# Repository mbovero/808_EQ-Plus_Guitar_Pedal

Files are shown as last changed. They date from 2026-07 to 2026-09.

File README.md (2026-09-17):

# 808 EQ+

A faithful, buildable recreation of the original Tube Screamer 808 circuit with optional bass, treble, and clipping controls.

Most of the 808 EQ+ signal path closely replicates the original TS808 using modern, functionally equivalent components. Its added controls were intentionally designed so they can be switched out of the circuit, allowing the pedal to return to the familiar mid-focused response, symmetric silicon clipping, compression, and sustain associated with a traditional TS808.

When more flexibility is desired, the added switches can extend the pedal’s bass response, open its upper-frequency response, and select between three distinct clipping configurations.

<p align="center">
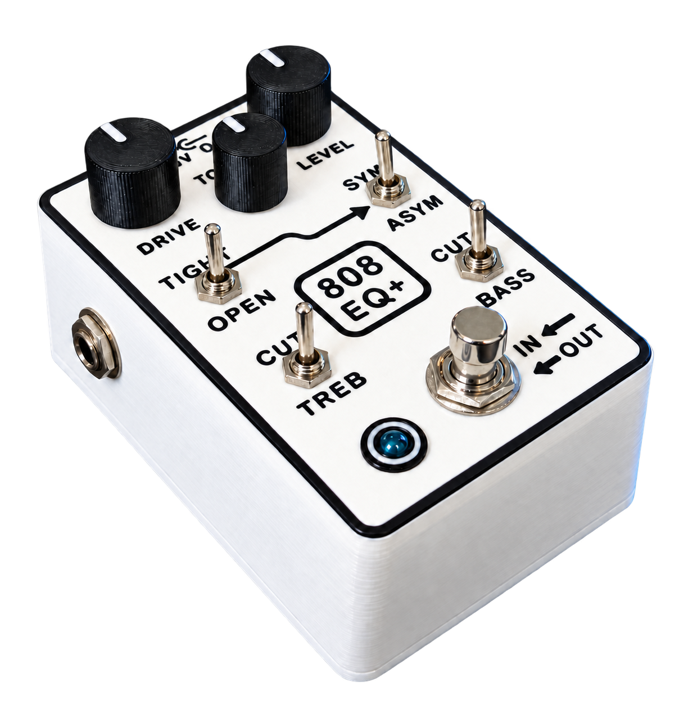
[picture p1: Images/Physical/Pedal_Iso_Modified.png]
Completed 808 EQ+ overdrive pedal.
  
</p>

<p align="center"><em>Completed 808 EQ+ overdrive pedal.</em></p>

## Table of Contents

* [What Is the 808 EQ+?](#what-is-the-808-eq)
* [Why Build Another Tube Screamer?](#why-build-another-tube-screamer)
* [Design Goals](#design-goals)
* [Controls and Operation](#controls-and-operation)
* [Technical Documentation](#technical-documentation)
* [Build Your Own 808 EQ+](#build-your-own-808-eq)
* [Warnings and Limitations](#warnings-and-limitations)
* [Credits and References](#credits-and-references)
* [Disclaimer](#disclaimer)

---

## What Is the 808 EQ+?

The Tube Screamer is best known for its characteristic mid hump, smooth symmetric clipping, and ability to act as a clean boost that pushes an amplifier while tightening and cleaning up the guitar tone.

The 808 EQ+ preserves that foundation.

Rather than replacing the original TS808 tone, the added controls make it possible to temporarily move beyond it. The bass and treble switches give the player access to a fuller, clearer sound with more low end and/or upper-frequency detail. The clipping switches change the headroom, compression, volume, and feel of the distortion.

With the added switches returned to their default positions, the pedal can operate like a traditional TS808.

### Traditional TS808 Character

In its default configuration, the 808 EQ+ provides:

* Reduced bass entering the distortion stage
* Reduced upper treble after the tone stage
* A pronounced mid-focused response
* Symmetric silicon-diode clipping
* Moderate compression and sustain
* Familiar Drive, Tone, and Level operation

### Expanded EQ+ Character

The added controls can provide:

* More low-frequency fullness without allowing excessive bass into the distortion stage
* Considerably more treble, presence, and clarity
* LED clipping with more headroom for dynamic distortion
* Asymmetric silicon clipping with slightly greater output and a rougher, more amp-like character

Beyond its expanded sound options, the project includes true-bypass switching, a custom through-hole PCB, and a fully modeled 3D-printed enclosure with custom knobs, an LED holder, integrated labels, and graphics. The repository also provides the design files, manufacturing files, and component information needed for hobbyist construction.

---

## Why Build Another Tube Screamer?

This project began as a way to learn how guitar pedals work internally and to apply the electronics, PCB design, CAD, and manufacturing skills I developed while studying computer engineering in college.

It was also an opportunity to put an existing collection of electronic components, fabrication tools, test equipment, and 3D-printing equipment to practical use.

Commercial guitar pedals can become expensive, especially when experimenting with several variations of a similar circuit. Building the pedal from the component level made it possible to study each circuit stage, experiment with tone-shaping and clipping behavior, and create a pedal tailored to my own preferences.

The idea of creating and sharing a design that could be reproduced, studied, and modified by other hobbyists was also a major motivation for the project.

## Design Goals

### Preserve the Original TS808 Circuit

The original TS808 was chosen as a reliable and well-understood foundation.

The goal was not to loosely imitate its sound or to create an unrelated overdrive with a similar name. The signal path was recreated carefully using modern but functionally equivalent components, and the added modifications were designed so they could be removed from the active signal path through the front-panel switches.

This allows the pedal to return to the original bass cut, treble cut, and symmetric silicon clipping that define the traditional Tube Screamer sound, with familiar Drive, Tone, and Level controls.

### Add More Tone-Shaping Flexibility

The original Tube Screamer response is useful because it prevents excessive low frequencies from becoming muddy and limits upper frequencies that might otherwise sound harsh.

However, those same filters can make the pedal feel narrow or overly mid-focused in some rigs.

Several tone-shaping approaches and component values were tested before selecting two modifications:

* A moderate bass extension that adds fullness without allowing the distortion to become excessively muddy
* A substantial treble extension that adds presence, clarity, and sparkle

Both modifications are independently switchable.

### Keep the Project Affordable and Customizable

A major goal was to reduce the cost of producing a complete pedal.

Traditional die-cast metal pedal enclosures can represent a significant portion of a DIY pedal’s cost. A 3D-printed enclosure reduces that cost while allowing much greater freedom over the enclosure shape, internal structure, labels, colors, mounting features, and overall appearance.

A 3D-printed enclosure can also be customized in ways that would be difficult or expensive with a standard metal box. In principle, the same electronics could be placed in a 3D-printed enclosure shaped like a cloud, mushroom, character, or other custom object.

### Make the Design Educational and Reproducible

The repository is intended for:

* Guitar-pedal enthusiasts with electronics and additive-manufacturing experience
* Electronics hobbyists interested in analog audio circuits
* Guitarists who want to build and modify their own equipment
* Students learning circuit simulation, PCB design, soldering, testing, or CAD
* Curious readers who want to understand how a Tube Screamer works
* Motivated builders who may not yet have enough knowledge to design a pedal independently

This is not intended to be the simplest possible beginner soldering kit. It is a complete engineering project that includes simulation, prototyping, PCB design, off-board wiring, mechanical design, additive manufacturing, and final assembly.

---

## Controls and Operation

The 808 EQ+ uses three knobs, four toggle switches, and a true-bypass footswitch.

<p align="center">
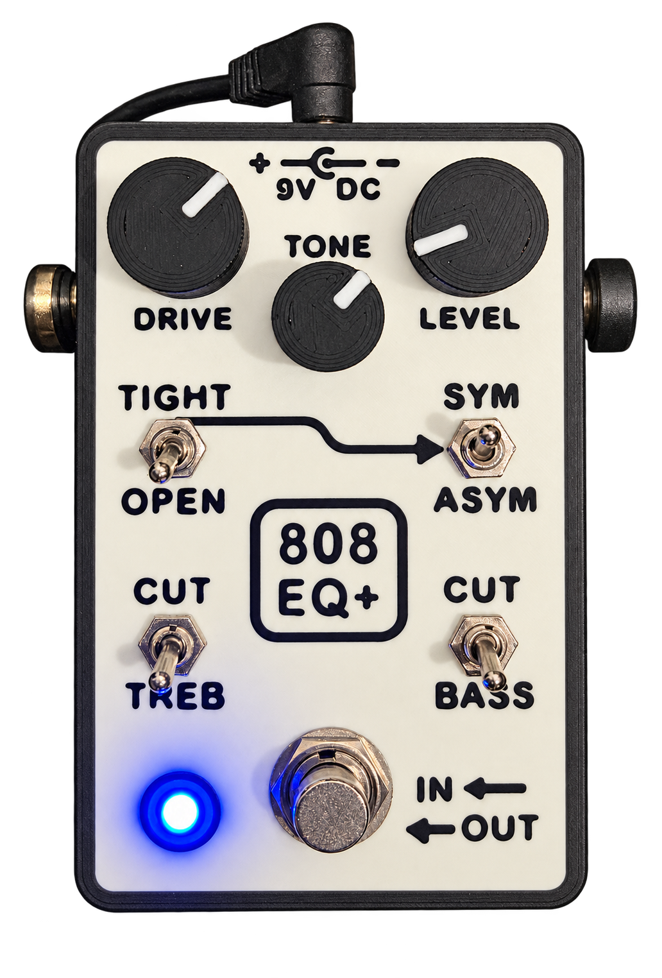
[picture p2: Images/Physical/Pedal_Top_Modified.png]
Top view of the completed 808 EQ+ pedal
  
</p>

<p align="center"><em>Top view of the completed pedal and its controls.</em></p>

| Control | What it does |
| --- | --- |
| **Drive** | Sets the amount of distortion. Turn it up for more grit, compression, and sustain. |
| **Tone** | Adjusts the pedal from darker and smoother to brighter and more present. |
| **Level** | Sets the final output volume. Start low and adjust it to match or boost the volume with the effect engaged. |
| **Tight / Open** | Selects a focused, more compressed sound or a louder, more dynamic sound. |
| **Sym / Asym** | Changes the texture of Tight-mode distortion from smoother and more even to thicker and grittier. This switch has no effect in Open mode. |
| **Cut / Treb** | Selects the traditional smoother treble response or adds clarity, presence, and sparkle. |
| **Cut / Bass** | Selects the traditional tighter low end or adds fullness and weight. |
| **Footswitch** | Turns the effect on or off. The LED lights while the effect is active; when it is off, true-bypass switching connects the input directly to the output. |

For the familiar TS808-style sound, flip all four toggle switches upward to select **Tight**, **Sym**, and both **Cut** settings. Lower the Level control before switching to Open mode because it can produce substantially more output.

For connection diagrams, detailed mode descriptions, recommended starting settings, power information, and troubleshooting help, see the [808 EQ+ User Manual](808_EQ-Plus_User_Manual.pdf).

---

## Technical Documentation

Detailed documentation for the project’s development process and major design stages is maintained separately:

* [Technical Documentation](TECHNICAL_DOCUMENTATION.md)

The separate document includes:

* Complete design and prototyping process
* In-depth circuit design
* PCB construction
* Enclosure design and mechanical integration
* 3D-printing considerations
* And plenty of information for curious minds

This material is separated to keep the main project page more approachable while preserving a deeper technical explanation for interested readers.

---

## Build Your Own 808 EQ+

If this project has made you curious about building an 808 EQ+ of your own, you are welcome to use the repository as a DIY construction resource. The project is intended for hobbyists who want to assemble the documented design, learn from it, or adapt it to suit their own ideas.

At a high level, the process involves reviewing the schematic and bill of materials, choosing between the provided PCB and a perfboard build, obtaining the components, printing and checking the enclosure parts, assembling and testing the electronics, installing the off-board controls and connections, and completing final mechanical and functional checks with a guitar and amplifier.

The complete [808 EQ+ DIY Build Guide](BUILD_GUIDE.md) brings together the component and tool lists, fabrication resources, PCB and perfboard options, recommended print settings, assembly guidance, staged testing, and troubleshooting information. Read through the guide before ordering parts or beginning construction.

---

## Warnings and Limitations

### Hobbyist 3D-Printed Enclosure Considerations

* The printed enclosure does not provide the same impact resistance as a cast-metal pedal enclosure.
* Common 3D-printing plastics are generally less resistant to high temperatures than metal enclosures and may soften, warp, or deform if exposed to excessive heat.
* A plastic enclosure does not inherently provide the electromagnetic shielding of a grounded metal enclosure.
* Print quality and dimensional accuracy will vary depending on the 3D printer, material, calibration, and print settings used. I cannot guarantee that every print will be suitable for mounting components or that all printed text will be legible.
* The enclosure does not include an internal battery compartment or an automatic battery-disconnection feature.

### Electronics and Assembly Considerations

* A regulated 9 V DC, center-negative pedal supply is recommended. An external 9 V battery adapter is also supported if its 2.1 mm connector polarity is verified before use.
* The circuit remains powered while bypassed. Disconnect an external battery when the pedal is not in use.
* Do not apply more than 9 V. The reverse-polarity diode does not protect the circuit from excessive input voltage.
* Some fabrication and assembly steps require prior soldering, electronics, CAD, or 3D-printing experience.

### Variations in Sound and Interpretation

* Exact sound will vary with the guitar, pickups, amplifier, speakers, signal level, power supply, and playing dynamics.
* Descriptions such as “smooth,” “open,” “gritty,” and “amp-like” are subjective and should not be treated as precise measurements.

---

## Credits and References

### Project Basis and Attribution

The 808 EQ+ is based on the established Tube Screamer 808 circuit topology. The underlying Tube Screamer circuit was not invented as part of this project.

The original contributions of this project include the specific circuit recreation, modern component selection, switchable tone and clipping modifications, PCB implementation, mechanical design, printed enclosure, documentation, and fabrication workflow.

Development drew on educational material covering TS808 circuit analysis, op-amp feedback-loop clipping, active tone controls, transistor buffering, analog filter design, guitar-pedal bypass wiring, through-hole PCB design, and additive-manufacturing practices.

### Primary References

Two resources were particularly helpful during the early research and circuit-analysis stages:

* [**ElectroSmash**](https://electrosmash.mas-effects.com/) — The ElectroSmash Tube Screamer analysis provided a detailed stage-by-stage explanation of the original circuit, including its operating theory, filter behavior, gain calculations, clipping, buffering, and tone control.
* [***Tracking Down Your Dream Tone — Build Your Own Guitar Effects Pedals: A Beginner’s Guide***](https://www.amazon.com/dp/B09ZCJLB9J) by Sascha Suhr — This book provided an accessible introduction to guitar-pedal electronics, circuit simulation, breadboard experimentation, component selection, practical construction, and troubleshooting.

### Additional Online Resources

The following websites, channels, and community forums were also consulted for circuit references, practical building information, equipment demonstrations, troubleshooting discussions, and perspectives from other pedal builders and guitarists:

* [Beavis Audio Research](https://beavisaudio.com/)
* [Analog Man](https://www.analogman.com/)
* [That Pedal Show](https://www.youtube.com/thatpedalshow)
* [GEO’s Effects](http://www.geofex.com/)
* [Free Stompboxes](https://www.freestompboxes.org/)
* [DIY Stompboxes](https://diystompboxes.com/wpress/)
* [PedalPCB Community Forum](https://forum.pedalpcb.com/)
* [The Gear Page](https://www.thegearpage.net/)

Community discussions and subjective descriptions were used as practical references rather than definitive technical sources. Circuit behavior and design decisions were evaluated through component datasheets, circuit analysis, simulation, electrical measurements, and hands-on listening tests.

### Software and Development Tools

Software and equipment used during development included:

* LTspice
* Analog Discovery 2 and WaveForms
* Altium Designer
* Autodesk Fusion 360
* Bambu Studio
* Bambu H2S
* DIY Layout Creator
* General electronic test, soldering, and assembly equipment

---

## Disclaimer

This project is provided for educational and personal-use purposes.

Build and use it at your own risk. Verify component values, component orientation, diode polarity, transistor pinouts, integrated-circuit orientation, power-supply polarity, operating voltages, and enclosure clearances before connecting the pedal to other equipment.

Disconnect power before modifying the circuit. Avoid making component changes while the pedal is connected to a guitar, amplifier, computer, audio interface, or other valuable equipment.

The repository may contain mistakes, and reports of any inconsistencies or errors would be greatly appreciated.

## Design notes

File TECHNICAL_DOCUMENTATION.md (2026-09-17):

# 808 EQ+ — Technical Documentation

This document contains the detailed development process, circuit design, PCB design, enclosure design, additive-manufacturing information, and experimental results for the 808 EQ+ guitar pedal.

For the project overview, controls, build guide, and current release status, return to the [main README](README.md).

## Table of Contents

<details>
<summary><strong><a href="#design-and-prototyping-overview">Design and Prototyping Overview</a></strong></summary>

* [1. Circuit Research and Part-by-Part Analysis](#1-circuit-research-and-part-by-part-analysis)
* [2. Original TS808 Simulation and Breadboard Prototype](#2-original-ts808-simulation-and-breadboard-prototype)
* [3. Frequency-Response and Clipping Experiments](#3-frequency-response-and-clipping-experiments)
* [4. Perfboard, Faceless Enclosure, and Prototype Validation](#4-perfboard-faceless-enclosure-and-prototype-validation)
* [5. Component Selection and Price Optimization](#5-component-selection-and-price-optimization)
* [6. PCB Design in Altium Designer](#6-pcb-design-in-altium-designer)
* [7. Enclosure Remodeling and Mechanical Integration](#7-enclosure-remodeling-and-mechanical-integration)
* [8. Final Assembly and Testing](#8-final-assembly-and-testing)

</details>

<details>
<summary><strong><a href="#circuit-design">Circuit Design</a></strong></summary>

* [Signal-Path Overview](#signal-path-overview)
* [Power Supply and Bias Network](#power-supply-and-bias-network)
* [Input Buffer](#input-buffer)
* [Variable-Gain and Clipping Stage](#variable-gain-and-clipping-stage)
* [Active Tone Stage](#active-tone-stage)
* [Output Buffer](#output-buffer)
* [True-Bypass and LED Circuit](#true-bypass-and-led-circuit)

</details>

<details>
<summary><strong><a href="#pcb-design">PCB Design</a></strong></summary>

* [Process Overview](#process-overview)
* [Design Priorities](#design-priorities)
* [Library Development](#library-development)
* [Through-Hole Components](#through-hole-components)
* [Socketed and Replaceable Components](#socketed-and-replaceable-components)
* [Routing and Grounding](#routing-and-grounding)
* [Manufacturer Selection and Design Files](#manufacturer-selection-and-design-files)

</details>

<details>
<summary><strong><a href="#enclosure-design-and-3d-printing">Enclosure Design and 3D Printing</a></strong></summary>

* [Why Use a Printed Enclosure?](#why-use-a-printed-enclosure)
* [Component-Driven Design](#component-driven-design)
* [Printed Labels and Graphics](#printed-labels-and-graphics)
* [Multi-Color Printing](#multi-color-printing)
* [Final Print Files and Build Guidance](#final-print-files-and-build-guidance)

</details>

<p><strong><a href="README.md">Return to the Main README</a></strong></p>

---

## Design and Prototyping Overview

The 808 EQ+ was developed through several stages, beginning with an in-depth study of the original TS808 circuit and progressing through simulation, breadboarding, measurement, perfboard prototyping, PCB design, enclosure modeling, and final assembly.

### 1. Circuit Research and Part-by-Part Analysis

The original TS808 circuit was studied in detail before beginning the physical design.

The [ElectroSmash](https://electrosmash.mas-effects.com/) Tube Screamer analysis was an especially useful reference. It provides an approachable but detailed explanation of the theory, mathematics, and behavior of the circuit and is a valuable resource for readers who want to understand why each stage operates as it does.

Additional background came from Sascha Suhr's book, [*Tracking Down Your Dream Tone — Build Your Own Guitar Effects Pedals: A Beginner's Guide*](https://www.amazon.com/dp/B09ZCJLB9J), which introduces both the theory and practical process involved in designing and building guitar effects pedals.

Other relevant concepts were researched through a wide range of freely available online educational resources. This research was supplemented by my background in computer engineering from the University of Utah.

Each major section of the TS808 circuit was analyzed separately, including:

* Input and output buffers
* Bias network
* Op-amp gain stage
* Frequency-dependent feedback
* Diode clipping
* Active tone control
* Power filtering
* Bypass behavior

This research established a known working baseline and made it possible to evaluate later modifications without losing track of the original circuit behavior. The part-by-part analysis was also used to identify modern components that could replace less-available original parts while preserving their electrical function.

### 2. Original TS808 Simulation and Breadboard Prototype

The development process began with a publicly available schematic of the original [TS808 circuit](https://electrosmash.mas-effects.com/ElectroSmash%20-%20Tube%20Screamer%20Circuit%20Analysis.pdf). That unmodified circuit was first recreated in LTspice and then assembled on a breadboard using the original topology and modern, functionally equivalent components.

Establishing a working unmodified circuit *first* provided a reference against which every later change could be evaluated. Full-size potentiometers, audio jacks, and a DC barrel jack were integrated into the breadboard during this stage so the circuit could be evaluated as a complete pedal system.

The breadboard stage facilitated the analysis of:

* Basic signal flow
* Input and output buffer operation
* Bias voltages
* Drive, Tone, and Level control behavior
* Symmetric silicon clipping
* Practical operation with a guitar and amplifier

The visual documentation in the following section begins with the final LTspice model and breadboard prototype after the EQ+ modifications were integrated.

### 3. Frequency-Response and Clipping Experiments

After the original circuit was operating correctly, the breadboard and LTspice models were modified one component and one circuit branch at a time.

The goal was to strike a useful balance between preserving the original TS808 character and adding meaningful tone-shaping options. The modifications were intended to be clearly audible without becoming either extreme or lackluster.

The Analog Discovery 2 and WaveForms software were used to examine:

* Frequency response
* Filter corner frequencies
* Gain changes
* Symmetric and asymmetric clipping
* Diode forward-voltage effects
* Output amplitude
* Waveform shape

Although these tools provided useful electrical measurements, a guitar-pedal circuit is difficult to characterize completely with a single set of tests. Its behavior can vary with the frequency and amplitude of the input signal, component tolerances, power-supply quality, radio-frequency interference, and other practical conditions. Each physical build may therefore behave slightly differently.

Final design decisions were made using a combination of circuit theory and analysis, LTspice simulation, Analog Discovery 2 measurements, and careful listening and experimentation with a guitar and amplifier. Measurements helped explain and compare circuit behavior, while hands-on playing determined whether each change was musically useful.

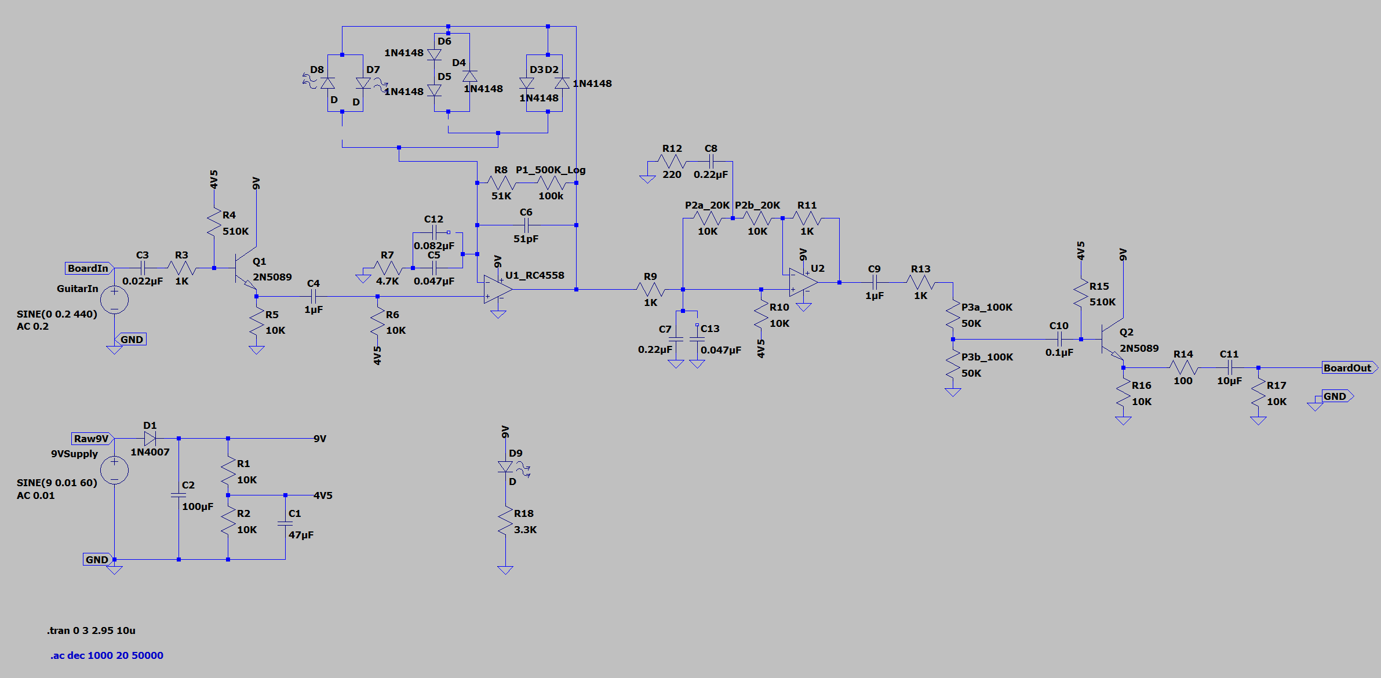
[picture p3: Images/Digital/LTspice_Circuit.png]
Modified 808 EQ+ LTspice circuit


*The circuit shown above is the final LTspice model containing the selected 808 EQ+ modifications.*

Much of the Bass Pass Through and Treble Pass Through development involved experimenting with different capacitor and resistor values, adding components at different points in the signal path, and comparing several switching arrangements.

The bass experiments focused on adding enough low-frequency content to produce a thicker, fuller sound without allowing the clipped bass frequencies to become excessively strong or muddy. The treble experiments focused on improving transparency, clarity, and presence without making the pedal sound harsh or fizzy. The final values were selected because they produced noticeable but controlled alternatives to the original TS808 response.

Detailed explanations of the selected circuits, component values, and filter corner frequencies are provided in [Bass Pass Through Switching](#bass-pass-through-switching) and [Treble Pass Through Switching](#treble-pass-through-switching).

The clipping experiments compared multiple arrangements of LEDs and 1N4148 silicon diodes. Symmetric, asymmetric, and mixed-diode configurations were evaluated for differences in output volume, compression, sustain, picking dynamics, and overall distortion character.

The final options were selected because each produced a distinct and practical sound: the original-style symmetric silicon configuration provides the familiar TS808 response, asymmetric silicon clipping offers a subtle variation with additional texture, and symmetric LED clipping provides a louder, more open, and dynamic alternative.

For a detailed explanation of the diode arrangements, clipping thresholds, and switch operation, see [Feedback-Loop Diode Clipping](#feedback-loop-diode-clipping) and [Clipping Switches and Configurations](#clipping-switches-and-configurations).

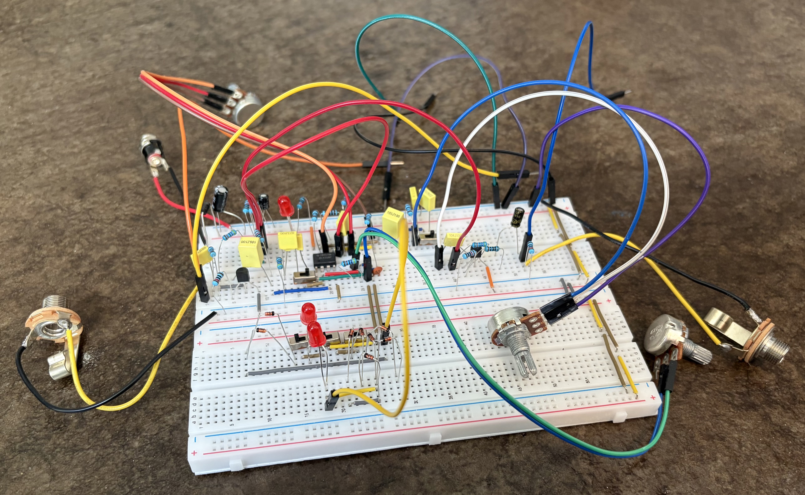
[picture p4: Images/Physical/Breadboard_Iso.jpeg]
Modified 808 EQ+ breadboard prototype


*Modified breadboard prototype used to evaluate the final EQ and clipping changes.*

Several other possible features were also considered and tested, including:

* A switch for increased distortion
* A switch that changed the output resistor between TS808 and TS9 values
* A wet/dry blend control
* Additional diode configurations

These options were not included in the final design because their changes were underwhelming or insignificant, or because the additional circuitry and controls fell outside the intended scope and complexity of the project.

### 4. Perfboard, Faceless Enclosure, and Prototype Validation

After the breadboard design was stable, it was transferred to perfboard to create a compact, more permanent circuit that reduced loose wiring, established a practical layout, and could be mounted inside a pedal enclosure.

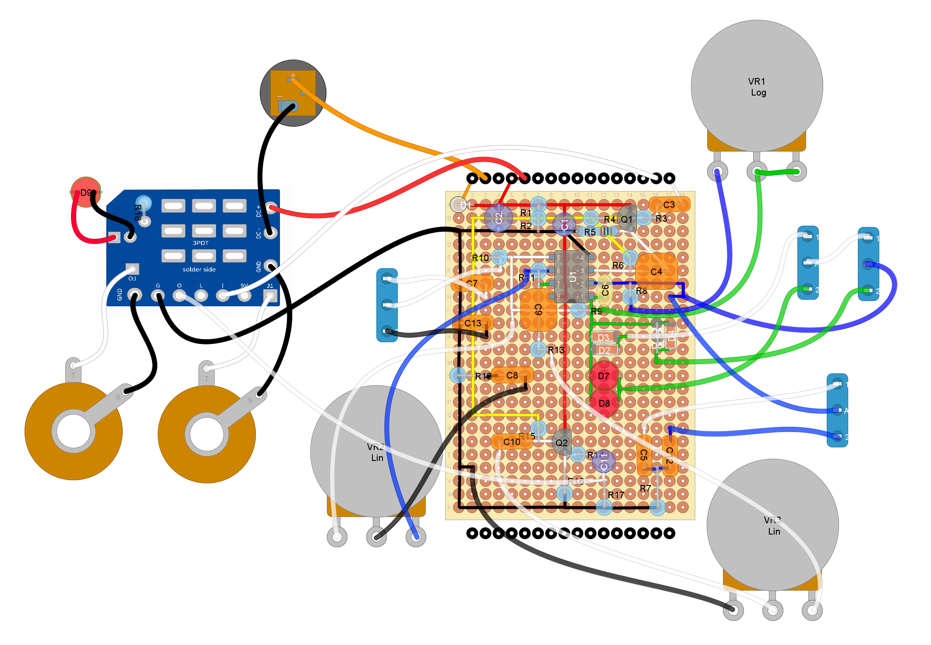
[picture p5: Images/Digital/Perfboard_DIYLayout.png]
Perfboard layout


The purpose of this design stage was to:

* Consolidate the circuit
* Integrate the true-bypass footswitch
* Reduce breadboard-related connection problems
* Test the design in a more durable and portable pedal format
* Confirm the final circuit before beginning PCB design

The first 3D-printed enclosure prototype was developed in Autodesk Fusion 360 and focused primarily on fit and function rather than appearance. It provided a practical way to mount the circuit and controls before committing to the custom PCB and final enclosure design.

The perfboard + test enclosure prototype was used to confirm:

* Basic effect operation
* True-bypass switching
* Drive, Tone, and Level controls
* Bass and Treble Pass Through behavior
* Symmetric silicon clipping
* Asymmetric silicon clipping
* LED clipping
* Switch interaction
* Practical off-board wiring
* Overall sound and usability

This validation established the final circuit configuration that would then be transferred to a custom PCB.

The perfboard circuit and faceless enclosure also exposed practical problems that were not as apparent during breadboard testing. These steps were helpful in understanding the intricacies of developing an intuitive, visually appealing, and reliable pedal. They allowed me to refine the physical circuit-assembly process, develop a more compact and easy-to-use enclosure, and configure 3D-printing settings that balanced appearance, dimensional accuracy, and functionality.

| Faceless prototype exterior | Perfboard prototype interior |
| --- | --- |
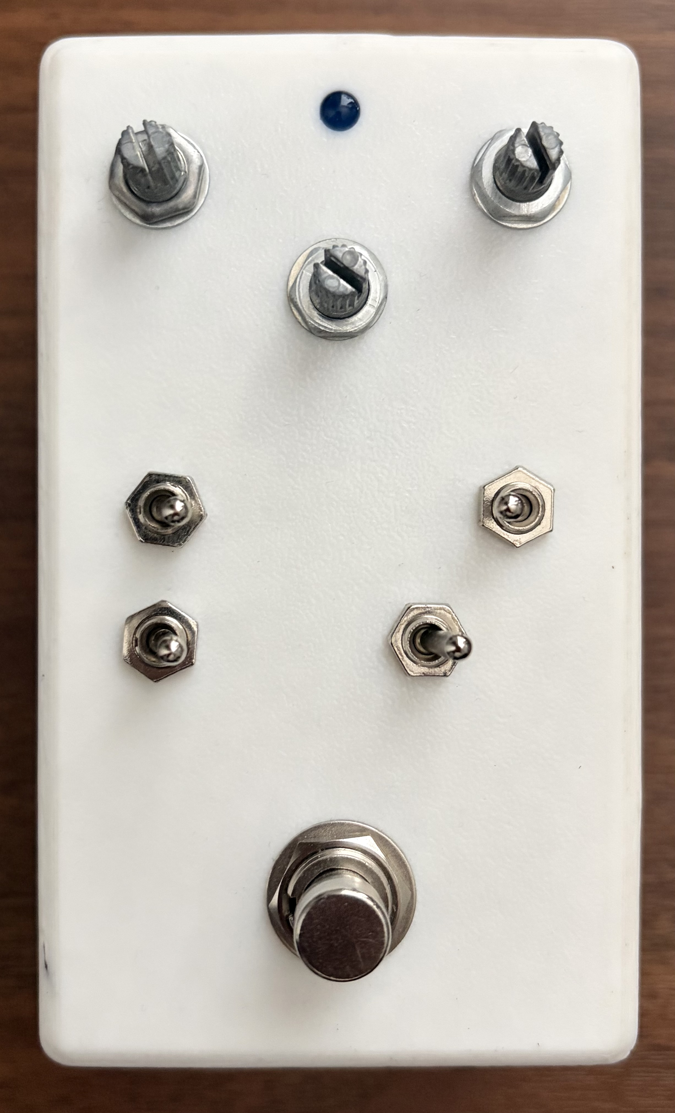
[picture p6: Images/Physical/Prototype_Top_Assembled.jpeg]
Top view of the assembled faceless prototype
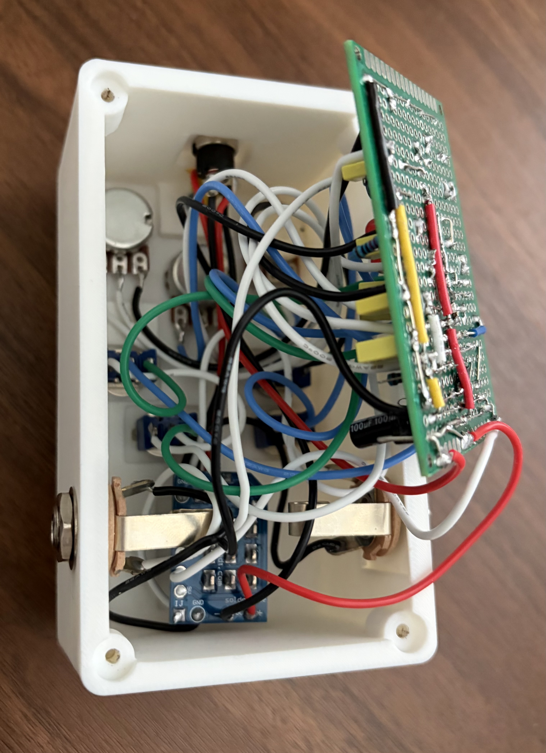
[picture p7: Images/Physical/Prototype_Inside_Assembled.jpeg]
Interior of the assembled prototype showing the perfboard circuit
|  |  |

### 5. Component Selection and Price Optimization

Considerable time was spent selecting quality components for the later revisions. This work had to be completed before PCB design because the exact component dimensions, pin spacing, and package styles were required to create or verify footprints and plan the board layout.

Many parts used in the early breadboard and perfboard prototypes came from bulk component variety kits. For the custom PCB revision, the goal was to source only the required parts, reduce unnecessary purchases, improve component consistency, and streamline assembly.

Parts were compared through [Octopart](https://octopart.com/) and supplier catalogs from [DigiKey](https://www.digikey.com/), [LCSC](https://www.lcsc.com/), [Tayda Electronics](https://www.taydaelectronics.com/), [Mouser](https://www.mouser.com/en/), and other vendors. DigiKey was selected as the primary source for on-board electronic components because it offered all the required parts, reputable component quality, reasonable pricing, and the ability to consolidate the order through one supplier.

The available options from these suppliers were less suitable for much of the off-board hardware. [Love My Switches](https://lovemyswitches.com/) was selected for affordable, good-quality potentiometers and mono jacks. The SPDT toggle switches and true-bypass footswitches were purchased through Amazon because they were significantly less expensive and the parts had already proved reliable in the first prototype.

Each supplier was chosen by balancing component cost, quality, availability, and total shipping expense. Enough parts were purchased to build five pedals, which reduced the estimated per-pedal cost through quantity pricing and by spreading shipping costs across multiple builds.

All components used in the final design, along with part numbers, quantities, suppliers, and estimated pricing, are listed in the [`808_EQ-Plus_Single_Pedal_BOM.xlsx`](Design/808_EQ-Plus_Single_Pedal_BOM.xlsx) file in the repository’s `Design` folder.

### 6. PCB Design in Altium Designer

The validated circuit was redrawn and laid out in Altium Designer as a compact, reproducible through-hole PCB. The process converted the working prototype into a board that balanced enclosure fit, signal routing, hand-assembly accessibility, serviceability, and support for continued component experimentation.

This stage included building and verifying the component libraries, organizing the circuit into functional blocks, optimizing component placement and routing, preparing clear assembly markings, checking the completed design, comparing fabrication services, and generating the required manufacturing files.

For a complete discussion of the component libraries, construction choices, socketed parts, grounding, routing, manufacturer selection, and fabrication outputs, see [PCB Design](#pcb-design).

### 7. Enclosure Remodeling and Mechanical Integration

After the electronic design and PCB dimensions were better understood, the enclosure was remodeled in Fusion around the physical requirements of the circuit and off-board hardware. Simplified models of the PCB, controls, switches, jacks, power connector, LED, and related hardware were used to refine component spacing, openings, internal clearance, wire routing, assembly access, and the overall enclosure dimensions.

The resulting enclosure was designed specifically for 3D printing and incorporates the pedal’s mounting features, labels, graphics, custom knobs, LED holder, and removable bottom cover into a unified design.

For additional information about the modeling process, component placement, printed labels, materials, multi-color fabrication, tolerances, and print considerations, see [Enclosure Design and 3D Printing](#enclosure-design-and-3d-printing).

### 8. Final Assembly and Testing

The final phase began with assembling the manufactured PCB, inspecting the solder joints, and verifying the orientation of polarized components. The completed board was then tested outside the enclosure so that electrical or assembly problems could be identified and corrected before the off-board components were mounted.

After confirming basic PCB operation, the controls, switches, jacks, LED, and other off-board components were installed. Enclosure fit, bypass operation, effect operation, and every switch configuration were evaluated alongside the pedal’s drive, output level, tone, and overall usability. Any mechanical or electrical issues identified during this process were corrected through further revisions.

The enclosure-printing process was also refined in Bambu Studio to improve appearance, dimensional accuracy, component fit, and overall functionality.

The completed PCB, enclosure, and assembled pedal have been fully tested and validated. Final fit checks confirmed that the PCB, off-board components, wiring, and printed enclosure function together as intended.

The final manufacturing files, PCB files, CAD exports, print files, dimensional drawings, and other supporting design resources have been released and are available in the repository’s [`Design`](Design/) folder.

---

## Circuit Design

The 808 EQ+ closely follows the original TS808 signal path while adding switchable filter and clipping options.

### Signal-Path Overview

```mermaid
flowchart TB
    IN["Guitar In"] --> SW{"3PDT true-bypass footswitch"}
    SW -->|"Bypass: effect off"| OUT["Guitar Out"]
    SW -->|"Effect engaged"| IB["Input Buffer"]
    IB --> CLIP["Variable-Gain and Clipping Stage"]
    CLIP --> TONE["Active Tone and Treble-Filtering Stage"]
    TONE --> LEVEL["Level Control"]
    LEVEL --> OB["Output Buffer"]
    OB --> OUT
```

When the effect is engaged, the footswitch routes the guitar through each functional circuit stage. In bypass, it connects the input directly to the output and grounds the unused effect input, removing the effect circuit from the guitar-signal path. The power connection is not shown; the circuit remains powered while bypassed.

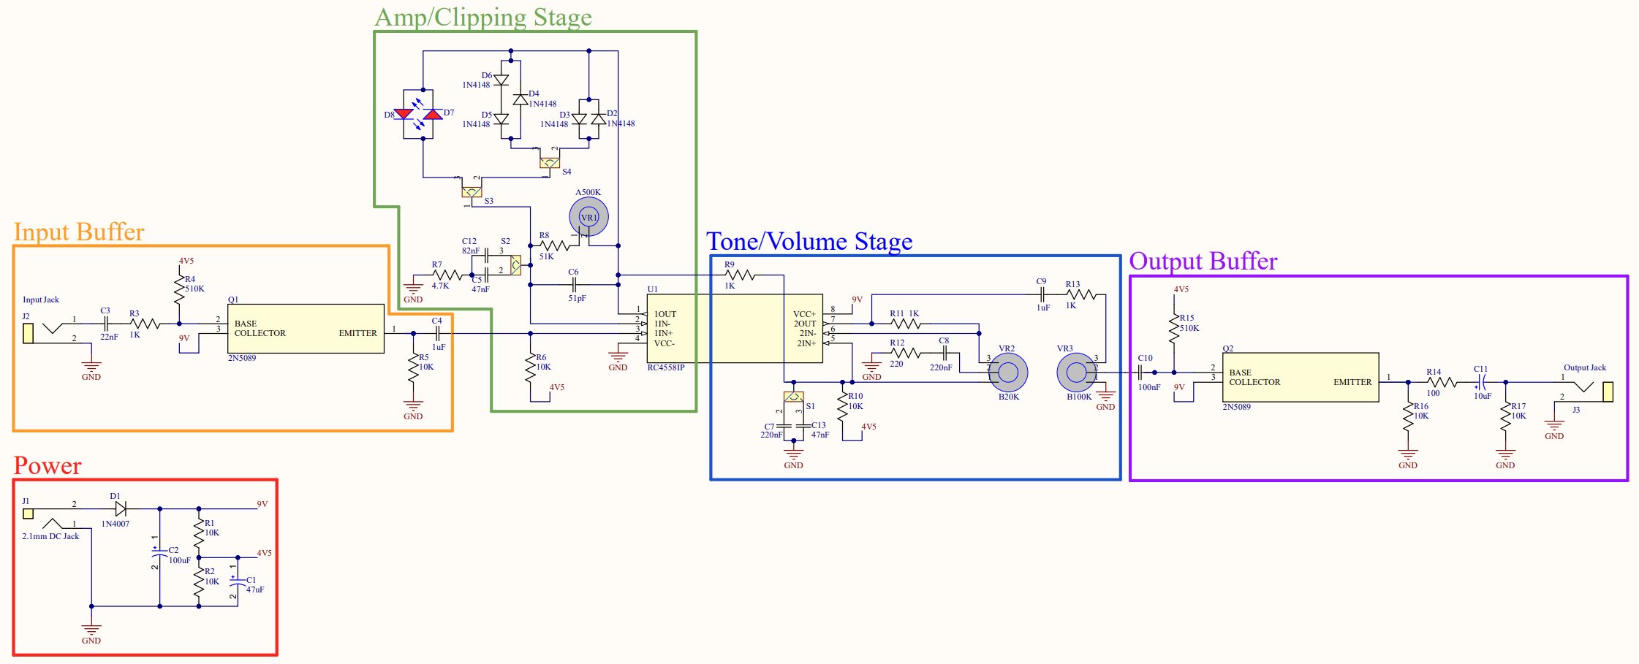
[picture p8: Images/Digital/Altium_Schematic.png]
808 EQ+ schematic


### Power Supply and Bias Network

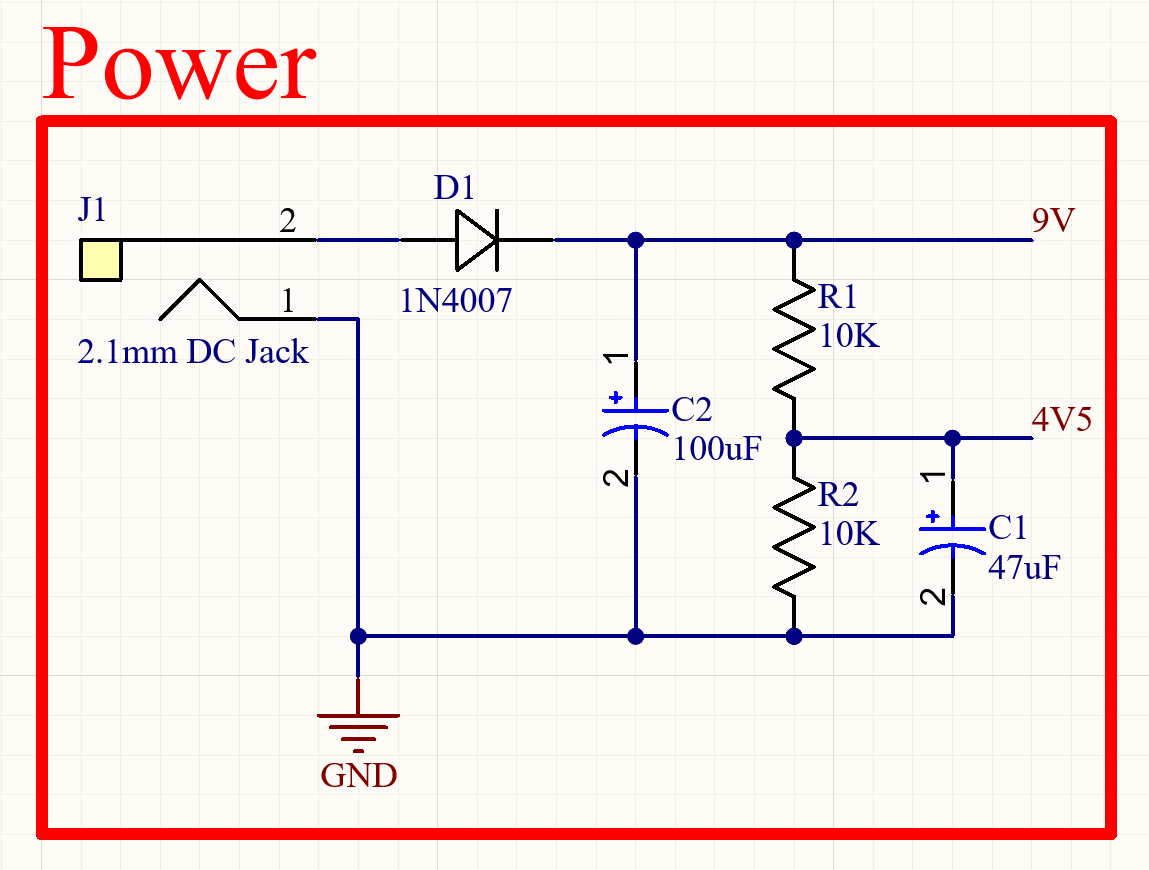
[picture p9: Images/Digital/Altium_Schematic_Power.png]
Power supply and bias network schematic


*Altium schematic of the 9 V input, reverse-polarity protection, supply filtering, and power rails.*

#### Power Input and Reverse-Polarity Protection

The recommended power source is a regulated **9 V DC, center-negative pedal supply** using the 2.1 mm barrel connector commonly found on modern guitar pedals. An external 9 V battery adapter is also supported if its connector polarity is verified before use. In either case, the connector’s outer sleeve supplies the positive voltage while its center pin is connected to ground.

D1, a **1N4007 rectifier diode**, is placed in series with the positive supply path to provide reverse-polarity protection. This diode differs from the protection components used in historical TS808 circuits, but it was selected to follow common modern pedal-design practices and provide a robust, readily available replacement. Because D1 is part of the power-supply path rather than the audio signal path, this change has no significant effect on the pedal’s sound or tone during normal operation.

If a supply with the opposite polarity is connected, the diode becomes reverse-biased and prevents significant current from flowing through the circuit. The pedal will not operate, and its transistors, op-amp, and polarized capacitors should be protected from reverse-polarity damage.

The diode protects against reversed polarity, but it does not regulate the input or protect the circuit from excessive voltage. Inputs above 9 V should not be used because they could exceed component ratings and damage the pedal.

#### 4V5 Bias Reference

R1 and R2 form a voltage divider that produces a nominal voltage equal to half of the protected supply rail. This node is labeled **4V5** and acts as a virtual midpoint for biasing the audio signal throughout the circuit.

Relatively low divider-resistance values were selected to reduce the reference node’s output impedance. This creates a firmer bias reference that is less susceptible to loading and transient voltage changes.

Because the circuit uses a single positive supply rather than positive and negative power rails, the guitar signal cannot remain centered around 0 V. Doing so would cause the negative half of the waveform to approach the ground rail, where it could be clipped or distorted by the BJTs and op-amp. Biasing the signal near half the supply voltage provides room for both halves of the AC waveform to swing above and below their DC operating point.

#### Supply Filtering and Distribution

C2 filters and stabilizes the protected 9 V rail, while C1 filters and stabilizes the 4V5 reference. Their relatively large capacitances provide a low-impedance path to ground for low-frequency supply ripple, transient disturbances, and some coupled interference. This helps provide cleaner and more stable power to the audio circuit, although it cannot eliminate every possible source of power-supply or radio-frequency noise.

The protected 9 V rail powers the active devices directly, including the op-amp supply and BJT collectors. The 4V5 reference is distributed through biasing resistors to establish the DC operating point at the beginning of the circuit’s audio stages.

#### Nominal and Actual Voltages

Labels such as **9V** and **4V5** describe the intended function of these rails rather than guaranteed measured voltages. The actual DC supply may differ slightly from exactly 9 V, and D1 introduces a forward-voltage drop that is typically around 0.7 V, although it varies with current and temperature. As a result, the protected rail may be closer to approximately 8–8.5 V when powered by a nominal 9 V supply, and the divided reference will be approximately half of that value.

A biasing resistor also does not automatically create a fixed voltage drop; the drop depends on the current flowing through it. Op-amp inputs draw very little current and may remain close to the 4V5 reference, while BJT bias nodes may differ more because of base current and surrounding component values.

These variations are expected and do not prevent normal operation. The important requirement is that each stage maintains a stable operating point with enough headroom for the guitar waveform. A guitar signal is often only a few hundred millivolts during typical playing, although strong transients from high-output pickups can approach roughly 2 V peak-to-peak or more.

### Input Buffer

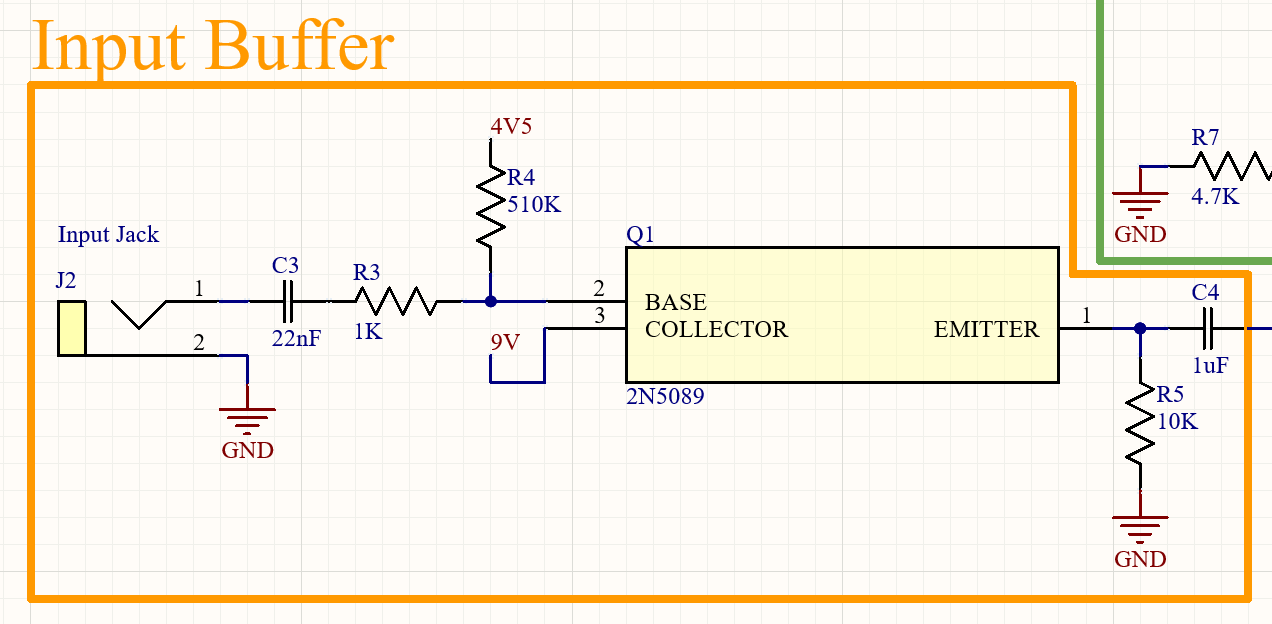
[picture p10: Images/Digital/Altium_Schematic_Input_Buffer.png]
Input buffer schematic


*Altium schematic of the input jack, coupling capacitors, bias network, and BJT emitter-follower buffer.*

#### Purpose and Impedance

The input buffer provides a stable interface between the guitar and the rest of the effect circuit. It isolates the guitar pickups from the more complex loading conditions created by the clipping stage and allows the original signal to be passed forward without intentional voltage amplification.

A good guitar buffer has a **high input impedance** and a **low output impedance**. An input impedance near 1 MΩ is commonly considered desirable, although values of several hundred kilohms are also widely used in guitar pedals. A high input impedance prevents the circuit from drawing substantial current from the pickups and reduces the damping of their natural frequency response. In this circuit, R4 and the transistor’s base impedance provide a sufficiently high input impedance for the guitar signal.

Cable and wiring capacitance can contribute to unwanted filtering. Before the buffer, the guitar pickup impedance, cable capacitance, and pedal input impedance form a more complex frequency-dependent network that can reduce high-frequency content and alter the pickup resonance. Commonly described as “tone sucking,” this effect becomes more noticeable when the following circuit presents too low of an input impedance or when long cables add substantial capacitance.

After the buffer, the interaction can be approximated more simply using:

`f_c = 1 / (2πRC)`

In this relationship, reducing the driving resistance moves the low-pass corner frequency upward. The buffer’s low output impedance therefore allows it to drive the following circuit and its associated capacitance without producing significant filtering within the audible range. A buffer cannot recover high frequencies already lost in the cable before it, but it prevents the following pedal stages from adding substantial additional loading.

#### Input Jack

The input uses a mono 1/4-inch audio jack. The sleeve is connected to circuit ground, while the tip carries the guitar signal into the input buffer.

Stereo input jacks are often used in pedals to disconnect an internal battery when the instrument cable is removed. The 808 EQ+ has no internal battery compartment or automatic battery-disconnection feature, so a mono jack was selected to simplify the wiring and reduce cost. An external 9 V battery adapter remains supported, but it supplies the circuit whenever it is connected—including while the effect is bypassed—and should be disconnected when the pedal is not in use.

#### Coupling Capacitors and Bias Transfer

C3 is an input coupling capacitor. The guitar signal arriving from the input jack is centered around 0 V, while the transistor base must operate at a positive DC bias. C3 blocks the guitar’s original DC level while allowing its AC audio content to pass into the transistor’s bias network.

R4 connects the transistor base to the 4V5 reference, causing the incoming guitar waveform to become centered around the nominal half-supply voltage. This provides room for the signal to swing above and below its new DC operating point without approaching the circuit’s ground rail.

C4 performs a similar function at the buffer output. Because the transistor is configured as an emitter follower, its emitter sits approximately one base-emitter voltage drop below the base—typically around 3–4 V DC in this circuit. C4 blocks that emitter DC level while passing the AC guitar signal to the clipping stage, where it is established around that stage’s own nominal 4V5 bias.

In addition to transferring signals between different DC operating points, the coupling capacitors interact with the surrounding resistances to form high-pass filters. Their values were selected so the desired guitar-frequency range can pass without excessive low-frequency loss.

#### BJT Emitter-Follower Configuration

The BJT is configured as an **emitter follower**, also called a **common-collector amplifier**. The input signal enters through the base, and the buffered output is taken from the emitter. The collector is connected directly to the protected 9 V rail, which supplies the transistor’s operating current and establishes its upper voltage limit.

R3 is a small series base resistor that provides isolation, limits transient base current, and can help reduce unwanted high-frequency or radio-frequency behavior. R4 supplies the base bias while also contributing to the buffer’s input impedance.

R5 provides the emitter with a path to ground and helps establish the transistor’s quiescent current and DC operating point. It also introduces negative feedback: changes in emitter current change the voltage across R5 in a direction that resists further change, improving stability.

An emitter follower has a voltage gain slightly below 1, so it does not significantly amplify the guitar waveform. Its primary benefit is current gain and impedance conversion. The original high-impedance guitar signal is reproduced at the emitter as a lower-impedance, higher-drive signal that can reliably feed the clipping stage.

### Variable-Gain and Clipping Stage

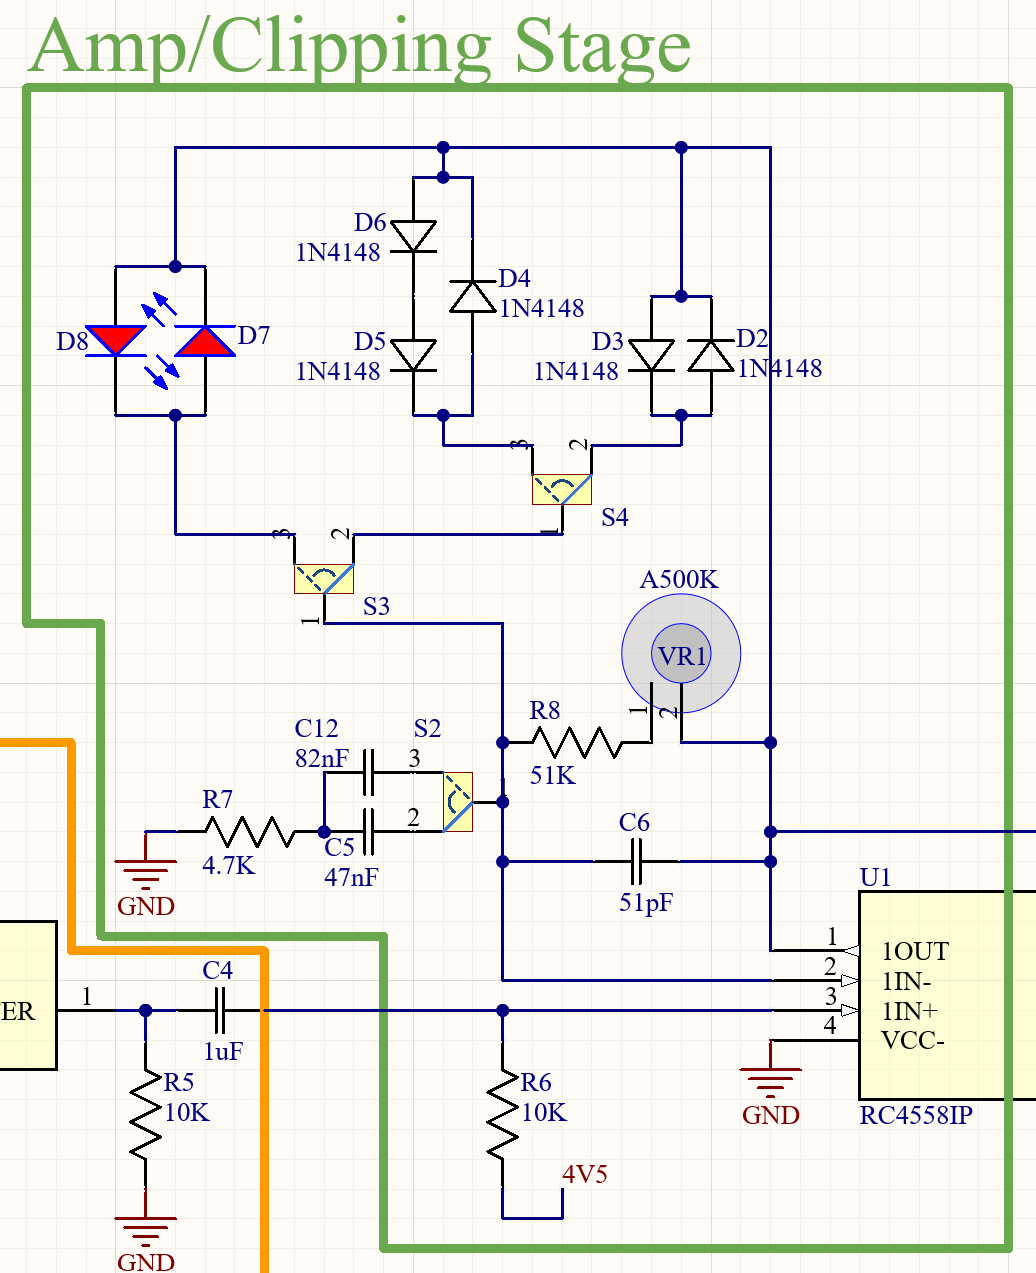
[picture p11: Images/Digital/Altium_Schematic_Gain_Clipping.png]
Amplification and clipping stage schematic


*Altium schematic of the non-inverting op-amp gain stage, frequency-dependent feedback network, Bass Pass Through switching, and selectable diode-clipping configurations.*

#### High-Level Behavior

The purpose of this stage is to add controlled, musically useful distortion to the guitar signal. The input is amplified by an op-amp in a non-inverting configuration until the voltage across the feedback network becomes large enough to forward-bias the clipping diodes. As the diodes begin conducting, they reduce the stage’s effective gain and progressively limit the waveform’s peaks. This produces the smoother transition into distortion commonly described as **soft clipping**.

Rather than amplifying every frequency equally, the TS808 feedback network reduces the gain applied to lower frequencies. This keeps excessive bass out of the clipped signal and helps prevent the distortion from becoming loose or muddy. The stage’s frequency-dependent gain, phase response, and diode clipping combine to produce the Tube Screamer’s characteristic waveform, including its tilted and rounded peaks and valleys.

This stage also contains the Bass Pass Through modification and the switches used to select the three clipping configurations.

#### Non-Inverting Amplifier and Drive Control

The op-amp is configured as a non-inverting amplifier. Within the frequency range where the feedback capacitors are not substantially affecting the circuit, its closed-loop gain can be approximated as:

`Gain = 1 + (Rf / Rg)`

In this circuit, `Rf` is primarily formed by R8 and the variable resistance of the Drive potentiometer, while `Rg` is R7. This produces an approximate midband gain range of **12 to 120**.

At the minimum Drive setting, the potentiometer’s wiper and connected outer terminal produce nearly 0 Ω of additional feedback resistance. The gain is then determined primarily by R8 and R7. Turning the Drive control clockwise increases the potentiometer resistance in the feedback path, raising the stage gain and driving the clipping diodes harder.

These gain values are frequency-dependent rather than constant across the entire guitar spectrum. At sufficiently low frequencies, the impedance of C5 or C12 causes the gain to fall toward unity. At very high frequencies, C6 also reduces the gain.

#### Frequency-Dependent Feedback

A capacitor’s opposition to AC current is called **capacitive reactance** and can be approximated as:

`Xc = 1 / (2πfC)`

Capacitive reactance decreases as frequency increases.

C6 is connected across the op-amp’s feedback resistance. At low and middle frequencies, its reactance is high, so the Drive potentiometer and R8 primarily determine `Rf`. At very high frequencies, C6 presents a lower-impedance path around the feedback resistance. This lowers the effective value of `Rf`, reduces the stage gain, and helps prevent very high-frequency noise and harsh, fizzy content from being excessively amplified.

C5 and C12 create the opposite frequency-dependent effect because the selected capacitor is placed in series with R7 in the feedback path to ground. At higher frequencies, the capacitor’s reactance is low and the stage operates near the gain predicted by `1 + Rf/R7`. As frequency decreases, the capacitor’s reactance rises, increasing the impedance of the feedback path to ground (`Rg`) and reducing the stage gain toward unity.

The result is a high-pass response in the stage’s distortion gain: middle and upper frequencies receive substantial amplification and clipping, while lower frequencies remain comparatively cleaner.

#### Bass Pass Through Switching

The original C5 value creates a distortion-stage high-pass corner at approximately **720 Hz**. Selecting C12 lowers this corner to approximately **410 Hz**, allowing more low-frequency content to receive the additional gain needed to enter clipping.

The Bass Pass Through capacitor value was chosen to give the guitar a thicker and fuller low end without allowing the distorted bass frequencies to become excessively strong or muddy.

A passive SPDT switch selects between C5 and C12. This keeps the modification simple and avoids placing an additional active switching circuit inside the sensitive feedback network. However, the inactive capacitor does not have a dedicated discharge path and may retain a small charge. A brief switching pop may therefore occur when changing between the Bass Cut and Bass Pass Through settings.

C5 and C12 also introduce a frequency-dependent phase shift, particularly around their respective corner frequencies. This phase response contributes to the shape of the resulting waveform, although the visible waveform is produced by the combined effects of filtering, amplification, clipping, and phase shift rather than by a simple time delay alone.

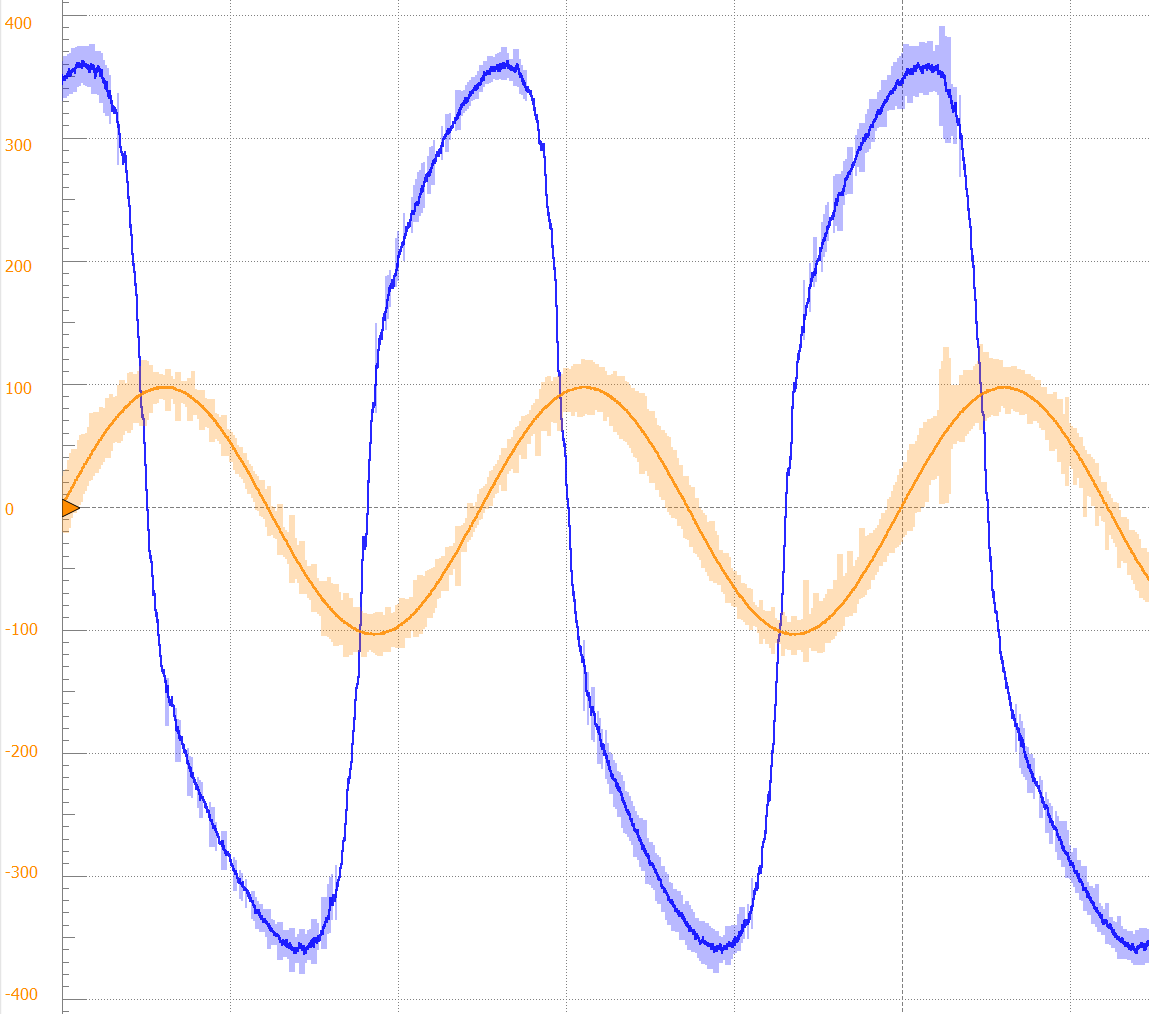
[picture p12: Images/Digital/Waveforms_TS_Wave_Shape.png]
Tube Screamer waveform shape


*Measured Tube Screamer-style waveform showing the characteristic shape produced by frequency-dependent amplification, capacitor phase shift, and feedback-loop clipping. Input is orange, and output is blue.*

#### Feedback-Loop Diode Clipping

The clipping diodes are connected inside the op-amp feedback loop. When the voltage difference across the diode network remains below its forward-conduction threshold, the diodes have little effect and the op-amp operates at the gain established by the feedback resistors.

As the amplified signal increases, the diodes begin to conduct and provide a lower-impedance feedback path. This increases negative feedback and reduces the stage’s effective gain near the waveform peaks. Because diode conduction increases progressively rather than switching instantaneously, the peaks are rounded instead of being cut off abruptly.

The 1N4148 silicon diodes have a forward voltage of approximately **0.6–0.7 V**, while the red LEDs have a substantially higher forward voltage of approximately **1.8 V**. The exact values vary with current, temperature, and the individual components.

Lower-forward-voltage diodes begin clipping at a lower signal level, producing greater compression and a tighter, more saturated response. Higher-forward-voltage diodes allow the op-amp output to reach a greater amplitude before substantial clipping occurs, resulting in more output volume, greater headroom, less compression, and a more dynamic response.

Amplification + clipping reduces the difference between louder and quieter portions of the signal. This compression can make the decaying portion of a note remain more consistent in volume and distortion character, which is often perceived as increased sustain.

#### Clipping Switches and Configurations

The **Tight/Open** switch selects between the silicon-diode network and the symmetric LED network:

* **Tight** engages the 1N4148 silicon clipping selected by the Sym/Asym switch.
* **Open** engages symmetric red-LED clipping and bypasses the Sym/Asym selection.

The **Sym/Asym** switch only affects the silicon clipping network:

* **Sym** uses one 1N4148 diode in each direction for the traditional symmetric TS808 configuration.
* **Asym** uses one 1N4148 in one direction and two series-connected 1N4148 diodes in the opposite direction, producing different positive and negative clipping thresholds.

| Tight/Open | Sym/Asym | Clipping configuration | General character |
| --- | --- | --- | --- |
| **Tight** | **Sym** | Symmetric silicon clipping | Traditional TS808-style clipping with relatively low headroom, moderate compression, and an even response on both halves of the waveform. |
| **Tight** | **Asym** | Asymmetric silicon clipping | Unequal clipping thresholds produce slightly greater output, less uniform compression, and additional even-order harmonic content associated with a thicker, more textured sound. |
| **Open** | Either position | Symmetric LED clipping | The higher clipping threshold provides substantially greater output, more headroom, reduced compression, and a more dynamic distortion response. |

The three configurations were selected because they provide distinct but practical variations without moving too far from the original TS808 character.

### Active Tone Stage

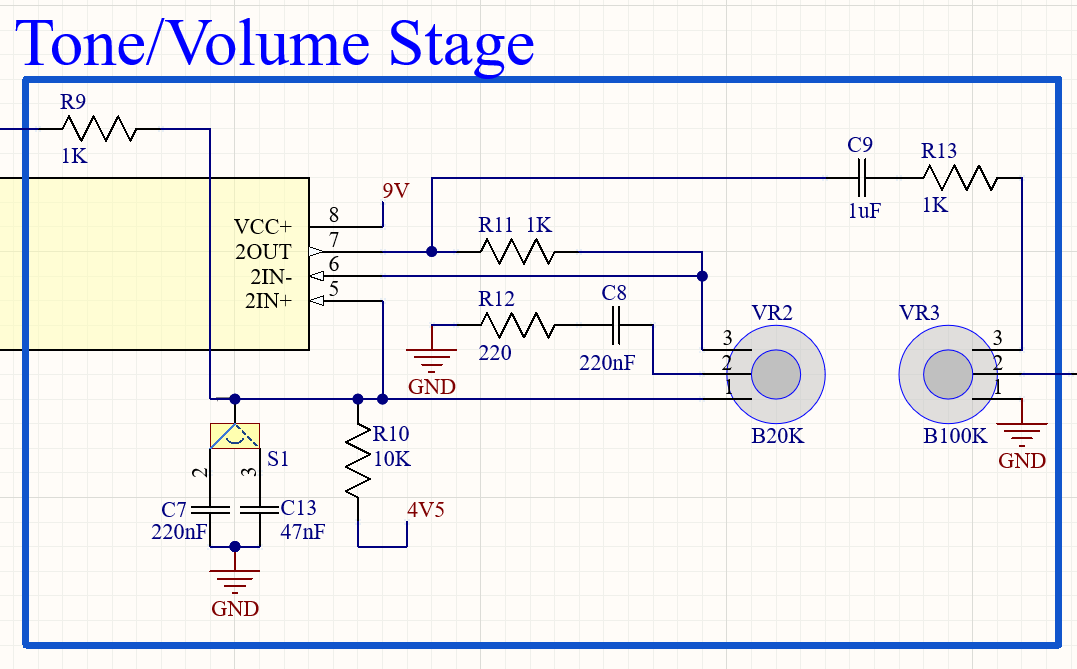
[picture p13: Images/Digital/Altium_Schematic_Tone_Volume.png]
Active tone and level-control schematic


*Altium schematic of the fixed low-pass filter, active upper-frequency boost, Tone control, Treble Pass Through modification, and Level control.*

#### High-Level Function

This stage provides control over the pedal’s upper-midrange and treble response. It combines a passive low-pass filter with an active, frequency-dependent op-amp stage. The Tone potentiometer blends between the darker filtered interaction and the brighter actively boosted interaction, allowing the player to move gradually from substantial treble reduction to a brighter and more present response.

The selected signal is then passed to the Level potentiometer, which controls the overall output amplitude. The coupling and buffering circuitry surrounding the Level control prevents the DC bias and external load from substantially interfering with the tone circuit.

#### Frequency-Dependent Signal Paths

The tone stage contains two primary frequency-dependent paths. The first is a low-pass filter formed by R9 and either C7 or C13, depending on the position of the Treble Pass Through switch. Its output is connected to the non-inverting (`+`) input of the op-amp. The selected capacitor determines the filter corner: C7 produces a corner near **720 Hz**, while C13 raises it to approximately **3.4 kHz**. The filter reduces content above the selected corner and passes the remaining signal into the rest of the tone circuit.

The second frequency-dependent path is formed by R12 and C8. This path can be reached from the initial low-pass-filtered path through one portion of the Tone potentiometer. C8 and R12 also interact with the op-amp feedback loop through the other side of the Tone potentiometer.

#### Active Upper-Frequency Boost

The op-amp is configured as a non-inverting amplifier. R11 forms the feedback resistance, while the Tone potentiometer, R12, and C8 form the frequency-dependent path from the inverting input to ground. Initially, it is helpful to analyze this portion of the circuit assuming the Tone pot is positioned all the way clockwise, giving a direct path from the feedback loop through C8 and R12 to ground.

At lower frequencies, C8 has relatively high capacitive reactance. This restricts current through the feedback path to ground and causes the op-amp gain to remain close to 1.

At higher frequencies, C8’s reactance decreases, leaving R12 as the primary resistance in the feedback path to ground. The high-frequency gain can then be approximated as:

`Gain = 1 + (R11 / R12)`

Using the selected component values, the maximum high-frequency gain is approximately **5.5**. This means the active path can amplify upper-frequency content by roughly five times relative to its low-frequency gain.

However, this does not mean the pedal’s final treble output is five times greater than the original guitar signal. The active boost occurs after the R9 and C7/C13 low-pass filter, which has already reduced some of the upper-frequency content. The final response results from the interaction between the initial low-pass filter, active high-frequency boost, Tone-pot position, and surrounding circuit impedances.

Although this simplified analysis does not capture every interaction in the circuit, it provides an intuitive explanation of how the tone stage can move between substantial treble reduction and an actively emphasized upper-frequency response.

#### Tone-Pot Operation

With the Tone control turned fully counterclockwise, its wiper is positioned toward the passive low-pass side of the circuit. This effectively puts C8 and R12 in parallel with C7 or C13, leading to a stronger reduction in upper-midrange and treble content. Simultaneously, the Tone pot's full resistance contributes to `Rg`, reducing the gain of the non-inverting op amp close to unity. These interactions produce a much darker, muted output.

With the Tone potentiometer turned fully clockwise, upper frequencies are actively boosted, providing substantially more upper-midrange and treble content. At the same time, the Tone potentiometer reduces current flow through C8 and R12, preventing higher frequencies from being cut as dramatically. This results in a significantly brighter and potentially harsh output.

Intermediate settings blend the two responses nicely, allowing the player to adjust the pedal continuously between a darker, more heavily filtered sound and a brighter, more present sound.

#### Treble Pass Through Switching

S1 and C13 form the **Treble Pass Through** modification. The SPDT switch selects the capacitor used with R9 in the tone-stage low-pass filter:

* Selecting C7 restores the original TS808-style corner frequency of approximately **720 Hz**.
* Selecting C13 raises the corner frequency to approximately **3.4 kHz**.

Raising the corner frequency allows substantially more upper-frequency content to reach the active tone circuit. C13 was selected to provide noticeably greater clarity, presence, and transparency without making the pedal excessively harsh or fizzy.

The Treble Pass Through switch changes the signal entering both sides of the Tone control. The Tone potentiometer continues to provide its normal dark-to-bright adjustment, but the overall available frequency range is extended when C13 is selected.

#### Level Control

After the Tone control selects the desired blend of passive and active responses, the AC signal is coupled to the Level potentiometer. The Level pot is configured as a voltage divider between the tone-stage output and ground.

At lower settings, a larger portion of the signal is directed toward ground and a smaller signal is taken from the wiper. Turning the Level control clockwise increases the proportion of the signal passed to the output buffer.

The Level control only attenuates the available signal; it does not provide additional gain. Its purpose is to set the final pedal output volume after the distortion and tone-shaping stages.

### Output Buffer

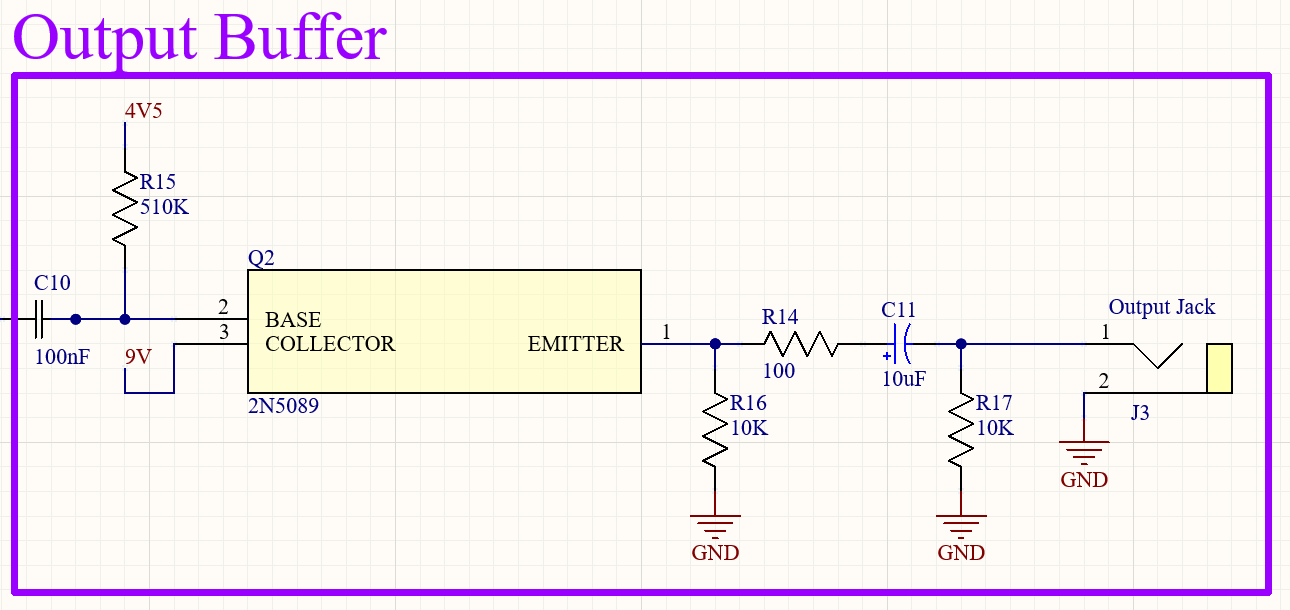
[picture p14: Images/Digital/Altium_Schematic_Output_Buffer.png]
Output buffer schematic


*Altium schematic of the BJT output buffer, output coupling capacitor, pull-down resistor, and output jack.*

#### Purpose

The output buffer performs a function similar to the [Input Buffer](#input-buffer), but its design priorities are slightly different. An extremely high input impedance is less critical here because the buffer is driven by the low-impedance tone-stage op-amp through the Level control rather than directly by passive guitar pickups.

Greater emphasis is placed on producing a low output impedance so the pedal can reliably drive an amplifier, another pedal, and the capacitance of the connected cable without significant signal loss or unwanted filtering.

The BJT uses essentially the same emitter-follower configuration as the input buffer. It provides a voltage gain close to 1 while increasing the available current drive and lowering the signal’s output impedance. See the [Input Buffer](#input-buffer) section for a more detailed explanation of emitter-follower operation.

#### Final Signal Preparation

The BJT emitter operates at a positive DC bias, but other pedals and amplifiers generally expect an audio signal centered around 0 V. C11 acts as the final coupling capacitor, blocking the buffer’s DC bias while allowing the AC guitar signal to pass to the output jack.

R17 is connected between the output side of C11 and ground. It establishes a 0 V DC reference and gives C11 a path to discharge when no output cable is connected. This prevents the output node from floating and helps reduce loud pops when connecting the pedal to other equipment.

C11, R17, and the input impedance of the connected equipment form a high-pass filter. Their values were selected to place the filter corner below the desired guitar-frequency range, preventing noticeable bass loss. The surrounding buffer components were selected to maintain a stable operating point and sufficiently low output impedance.

The prepared signal is delivered through the tip of the mono output jack, while the sleeve provides the ground connection.

### True-Bypass and LED Circuit

#### 3PDT Switching

Several true-bypass wiring arrangements are commonly used and can be found online. A 3PDT footswitch is especially useful when true-bypass signal routing, effect-input grounding, and LED indication must all be controlled by one switch.

A 3PDT switch contains three electrically independent poles that change state together. Each pole has a center common lug that connects to one of two outer lugs depending on the footswitch position. The switches purchased for this project included small breakout PCBs that simplify these connections and reduce the amount of point-to-point wiring required during assembly.

In this implementation, the three center connections correspond to the input jack, ground, and output jack. Pressing the footswitch connects these points to one of two sets of switched contacts.

#### Bypass State

When the effect is bypassed, the input jack is connected directly to the output jack. The guitar signal therefore travels through the mechanical switch without passing through the pedal’s input buffer, clipping stage, tone circuit, or output buffer.

At the same time, the effect-circuit input is connected to ground. Grounding the unused input prevents it from floating, where it could collect noise or create unpredictable behavior that becomes audible when the effect is re-engaged.

“True bypass” refers to the audio signal being disconnected from the effect circuit. The internal circuit remains electrically powered while bypassed, but it is removed from the active guitar-signal path.

#### Effect State

When the effect is engaged, the input jack is connected to the effect-circuit input and the effect-circuit output is connected to the output jack. The guitar signal then passes through the complete pedal circuit before continuing to the next pedal or amplifier.

The third pole completes the status-LED circuit, illuminating the LED to indicate that the effect is active.

#### LED Current Limiting

An LED requires a series current-limiting resistor to prevent excessive current from damaging the LED or placing unnecessary load on the power supply. The required resistance depends on the supply voltage, the LED’s forward voltage, and the desired operating current:

`R = (Vsupply - Vf) / ILED`

The LED forward voltage depends on its color and construction, while the selected current determines its brightness. In practice, a standard resistor value at or above the calculated resistance should be selected to keep the LED within its rated current. A lower-current operating point is often sufficient for a pedal indicator and reduces power consumption.

#### True Bypass Versus Buffered Bypass

Some pedals use buffered bypass, meaning the guitar signal continues to pass through an active buffer even when the effect itself is disabled. This can provide a low output impedance that helps drive long cables and other pedals, but it also means the bypassed signal is not completely isolated from the pedal’s electronics.

The 808 EQ+ does not use buffered bypass. When bypassed, the guitar signal follows a passive mechanical path directly from the input jack to the output jack. The pedal’s input and output buffers are only part of the signal path while the effect is engaged.

---

## PCB Design

The custom PCB was developed in Altium Designer to translate the validated prototype into a more durable, reproducible, and serviceable format.

### Process Overview

The PCB was developed through the following process:

1. Collect, revise, and organize the required schematic symbols and PCB footprints.
2. Redraw the complete schematic and assign the verified components, footprints, and designators.
3. Define the board shape and systematically place the through-hole components.
4. Position the off-board connection pads and orient component labels, values, and polarity markings for straightforward assembly.
5. Route the signal and power traces, then create the top and bottom ground pours.
6. Run electrical- and PCB-design-rule checks, correcting any identified problems.
7. Review the completed board in both 2D and 3D.
8. Generate the fabrication files and inspect the manufacturer previews before ordering.

| PCB top | PCB bottom |
| --- | --- |
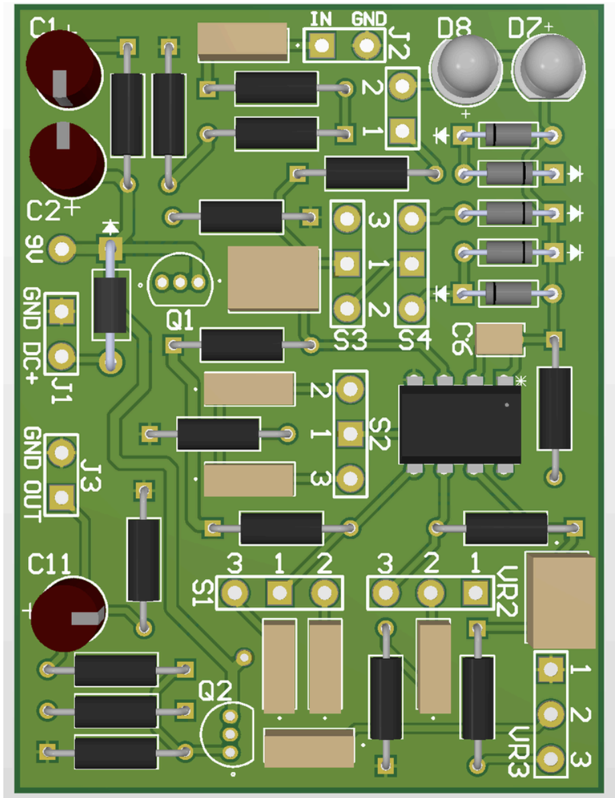
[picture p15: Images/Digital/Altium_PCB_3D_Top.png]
PCB top
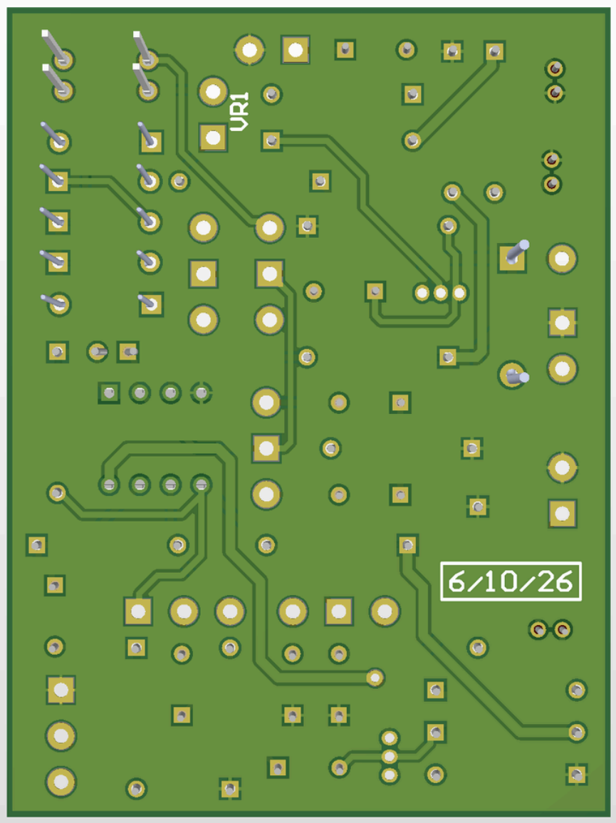
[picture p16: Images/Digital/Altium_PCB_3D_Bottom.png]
PCB bottom
|  |  |

### Design Priorities

The PCB was designed around the following priorities:

* Preserve the validated TS808-style circuit
* Use readily solderable through-hole components
* Group components by functional circuit block
* Provide practical connection points for off-board wiring
* Support component replacement and experimentation
* Fit efficiently within the custom printed enclosure
* Minimize trace length, unnecessary crossings, and layer changes
* Provide clearly aligned component designators, value labels, and polarity markings
* Make fabrication possible through common prototype-PCB services

### Library Development

Many schematic symbols and PCB footprints were sourced from DigiKey and collected into organized Altium project libraries. Each resource was reviewed for dimensional accuracy and checked against the corresponding component datasheet to verify its pinout, package dimensions, and lead spacing. Existing library components were corrected when necessary, and custom symbols or footprints were created when suitable resources were unavailable.

The completed Altium library files are available in the repository’s [`Design/PCB/Altium`](Design/PCB/Altium/) folder.

### Through-Hole Components

Through-hole components were selected because they are relatively easy to solder by hand, inspect visually, and replace when necessary. They are also familiar to many hobbyists, readily available in small quantities, and compatible with machine-pin sockets for experimentation or repair.

Although through-hole construction requires more board space than surface-mount construction, the increased accessibility and serviceability made the larger PCB area a worthwhile tradeoff.

### Socketed and Replaceable Components

Selected components can be installed in machine-pin sockets.

This is useful for:

* Comparing op-amps
* Comparing clipping diodes
* Replacing transistors
* Revising filter capacitors
* Troubleshooting damaged components
* Experimenting without repeatedly heating PCB pads

Sockets should be used selectively. Permanently installing every component in a socket would increase cost, assembly time, contact resistance, and the risk of intermittent connections.

Suggested components for machine-pin sockets include Q1, Q2, U1, C12, C13, and the clipping diodes. These locations are especially useful for tone experimentation, troubleshooting, repair, and comparing compatible replacement components.

### Routing and Grounding

The circuit’s typical current draw was measured at approximately **7–10 mA**. This range was entered into a PCB trace-width calculator, but the low current produced unusually narrow minimum-width recommendations. After researching trace widths commonly used by other guitar-pedal designers, wider traces were selected to provide more practical fabrication margins and greater physical robustness. The final layout uses **0.8 mm traces for the power rails** and **0.6 mm traces for signal paths**.

Signal traces were routed with attention to:

* Keeping related components close together
* Minimizing board area and trace length
* Reducing unnecessary trace crossings and layer changes
* Separating sensitive signal paths from power wiring
* Avoiding interference with through-hole pads
* Maintaining fabrication clearances

The board uses copper pours on both sides for ground distribution.

### Manufacturer Selection and Design Files

Several PCB manufacturers, including [OSH Park](https://oshpark.com/), [JLCPCB](https://jlcpcb.com/), [PCBWay](https://www.pcbway.com/orderonline.aspx), and [Elecrow](https://www.elecrow.com/pcb-manufacturing.html), were considered for producing the final board. Pricing, order quantities, fabrication options, shipping costs, turnaround time, and experiences reported by other hobbyists were compared. JLCPCB was ultimately selected because it offered an affordable option for the required boards and had received substantial positive feedback from other users online.

The relevant Altium project files, Gerber files, drill files, and other manufacturing outputs are available in the repository’s [`Design/PCB`](Design/PCB/) folder.

<table>
  <thead>
    <tr>
      <th>Bare PCB — component side</th>
      <th>Bare PCB — solder side</th>
    </tr>
  </thead>
  <tbody>
    <tr>
      <td align="center">
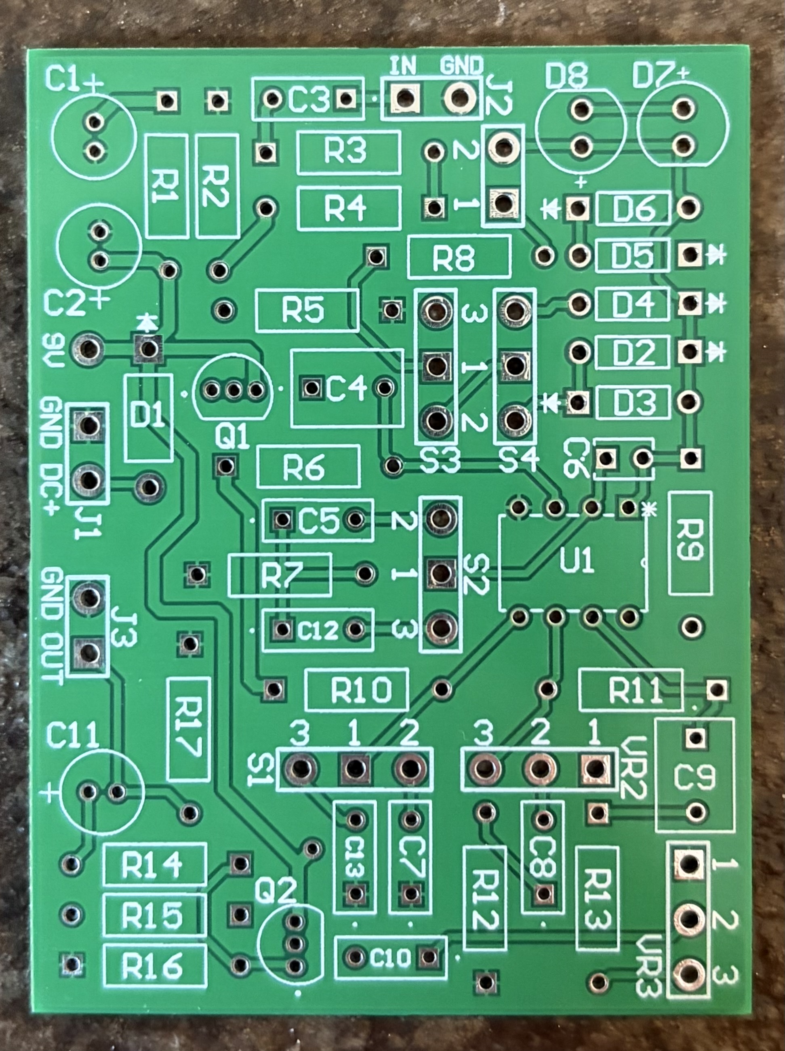
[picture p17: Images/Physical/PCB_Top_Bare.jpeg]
Component side of the bare PCB
        
      </td>
      <td align="center">
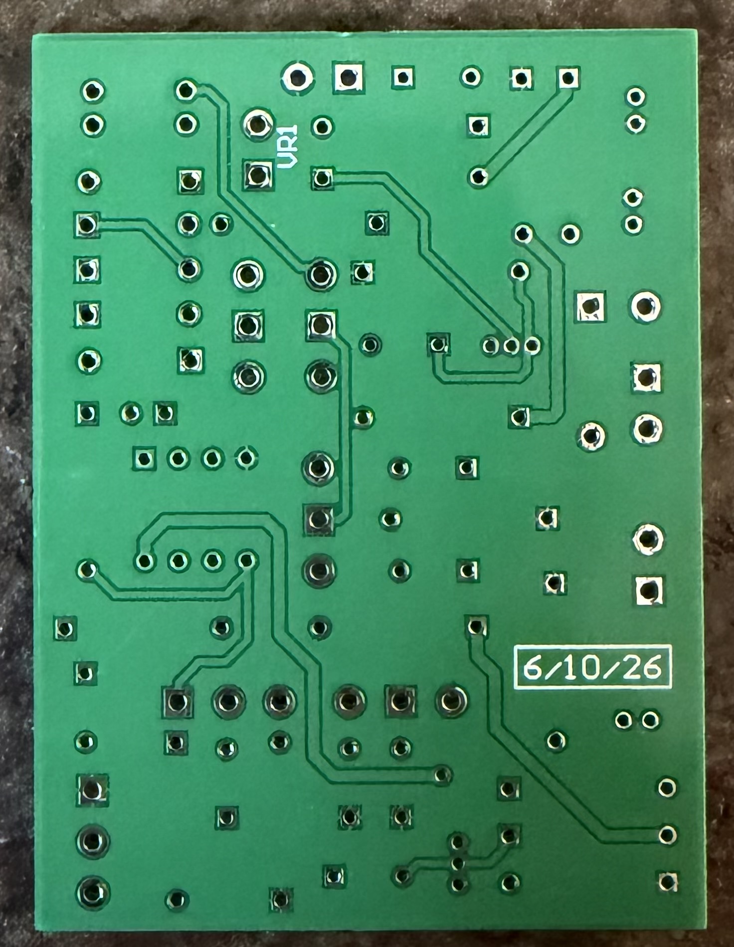
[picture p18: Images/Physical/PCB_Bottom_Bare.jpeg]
Solder side of the bare PCB
        
      </td>
    </tr>
  </tbody>
</table>

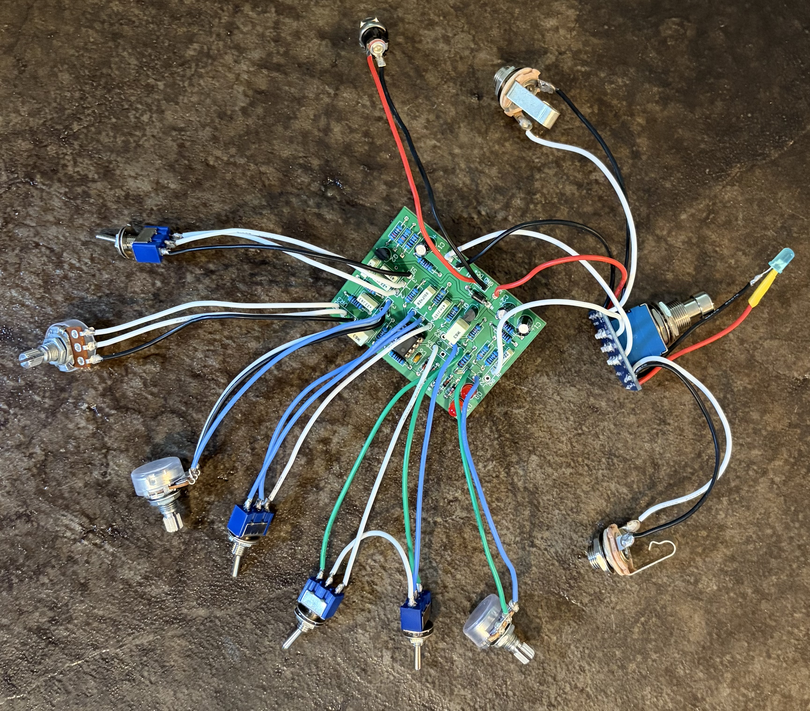
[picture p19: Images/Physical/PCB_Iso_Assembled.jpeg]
Assembled PCB with the off-board controls connected


*Assembled PCB and off-board controls prepared for bench testing.*

---

## Enclosure Design and 3D Printing

The enclosure was designed as an integrated part of the project rather than as a generic box added after the electronics were complete.

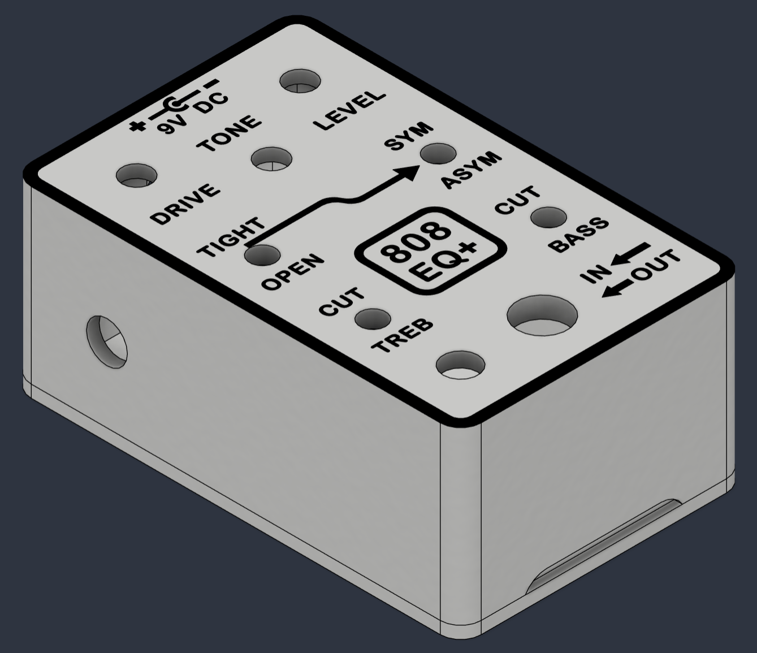
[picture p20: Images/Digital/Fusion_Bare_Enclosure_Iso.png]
Bare enclosure


### Why Use a Printed Enclosure?

A printed enclosure provides several advantages:

* Lower cost than many commercial pedal enclosures
* Freedom over the outer shape and proportions
* Integrated labels and symbols
* Rapid revision of holes and component spacing
* Custom knobs and LED hardware
* Multiple colors without decals or screen printing
* Easy reproduction from digital files

The main tradeoffs are:

* Reduced impact resistance
* Reduced temperature resistance
* Reduced electromagnetic shielding
* Potentially longer fabrication time
* Greater dependence on print orientation and tolerances

> **Warning:** Common 3D-printing plastics may soften, warp, or deform at temperatures that would not damage a metal enclosure.

### Component-Driven Design

All enclosure-mounted components were modeled specifically for this project, including the potentiometers, toggle switches, footswitch, input and output jacks, DC power connector, PCB boundary, and LED. No existing component models were imported. Nuts, washers, and other fasteners were excluded because their detailed geometry was not necessary for the enclosure design.

These component models were used to determine the required hole diameters, internal spacing, PCB position, wire-routing space, footswitch clearance, jack depth, wall thickness, bottom-cover geometry, and tool access needed during assembly.

| Component placement (top-down) | Enclosure interior |
| --- | --- |
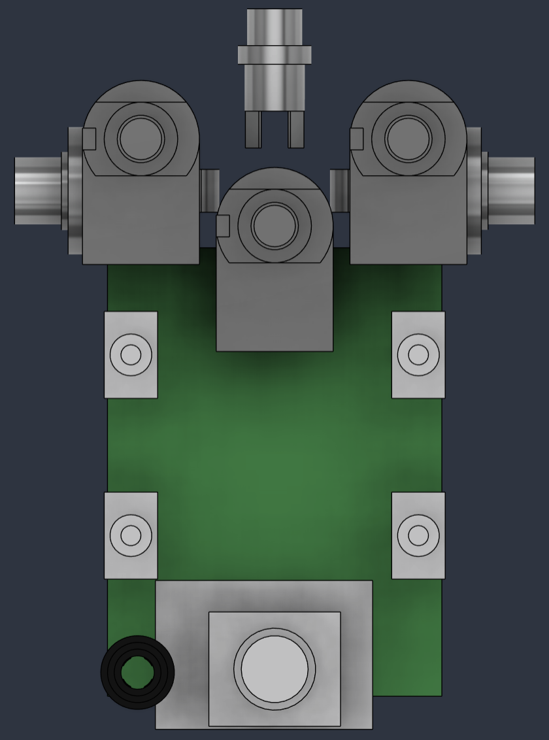
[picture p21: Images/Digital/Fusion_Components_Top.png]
Component placement
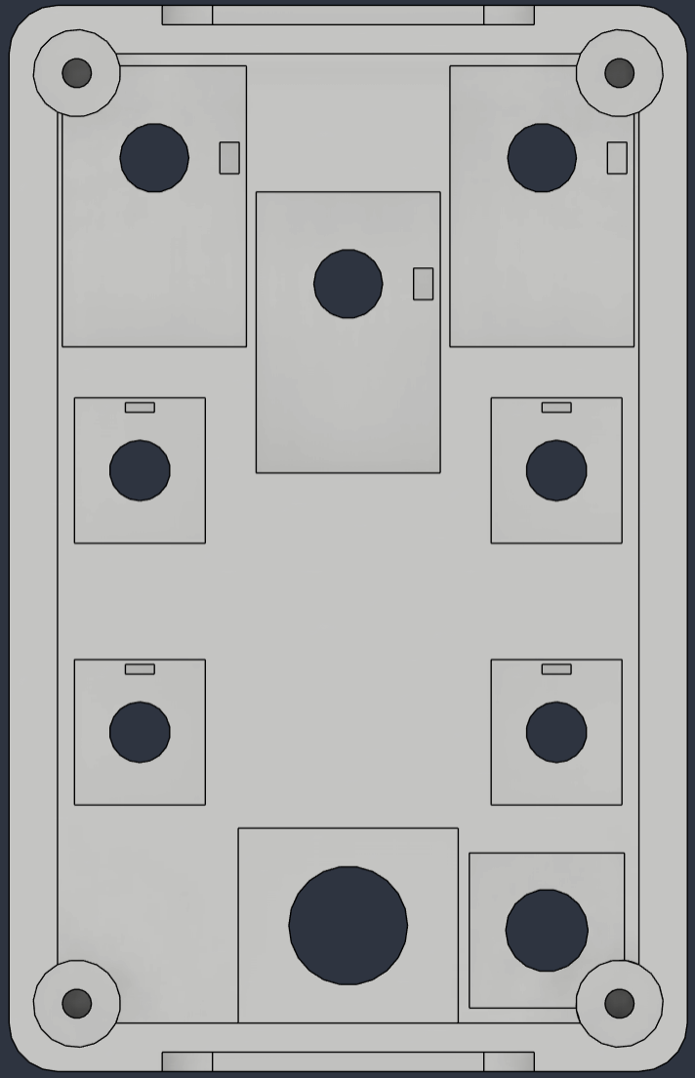
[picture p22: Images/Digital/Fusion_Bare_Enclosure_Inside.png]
Enclosure interior
|  |  |

The enclosure also includes:

* Custom printed knobs
* A custom LED holder
* Bottom-cover locating features
* Openings for enclosure-mounted components
* Print-aware wall thicknesses and tolerances
* A small access cutout that makes the bottom plate easier to remove after its screws have been removed

Dedicated PCB mounting features were intentionally omitted to simplify the enclosure design and final assembly process. Because the internal layout is compact, the PCB does not move freely once the pedal is fully assembled. The connected wiring constrains its position, while the bottom plate limits vertical movement and keeps the board mostly stationary inside the enclosure.

### Printed Labels and Graphics

The face labels and symbols are integrated into the enclosure model rather than applied afterward.

Contrasting filament is inlaid flush with the enclosure surface. The label geometry is designed to print against the build plate, producing a clean, flat front face without raised or recessed lettering.

A smooth PEI plate was used to improve the finish and readability of the labels. A textured plate may also work, but it can produce a shinier surface texture, less crisp lettering, more irregular edges, and blobbier or harder-to-read small text.

<p align="center">
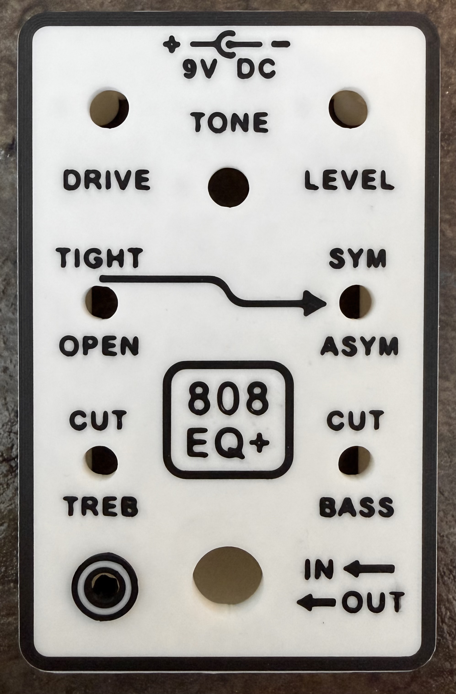
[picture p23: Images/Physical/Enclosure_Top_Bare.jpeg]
Printed enclosure face showing the flush labels and graphics.
  
</p>

<p align="center"><em>Printed enclosure face showing the flush labels and graphics.</em></p>

### Multi-Color Printing

The enclosure graphics were designed as separate inlays that print flush with the front surface. Printing the enclosure face-down places both the enclosure and label geometry against the build plate, producing a unified surface without decals, raised lettering, or post-processing.

The validated design uses shallow black inlays against a white enclosure. A dark accent remained clearly visible in a single layer, so the inlays could be kept thin to reduce filament changes and purge waste. The design is not limited to black and white, but contrast and opacity should guide other color choices. Light or translucent accents over a dark enclosure may require deeper inlays or a different finishing method to remain legible.

Multi-color printing is optional; the enclosure can also be printed in one color or finished with painted, filled, raised, recessed, or separately printed labels. For filament assignments, print order, manual STL preparation, and other fabrication guidance, see [Part 3 of the build guide](BUILD_GUIDE.md#3-print-and-verify-the-enclosure-parts).

| Sliced enclosure | Sliced underside |
| --- | --- |
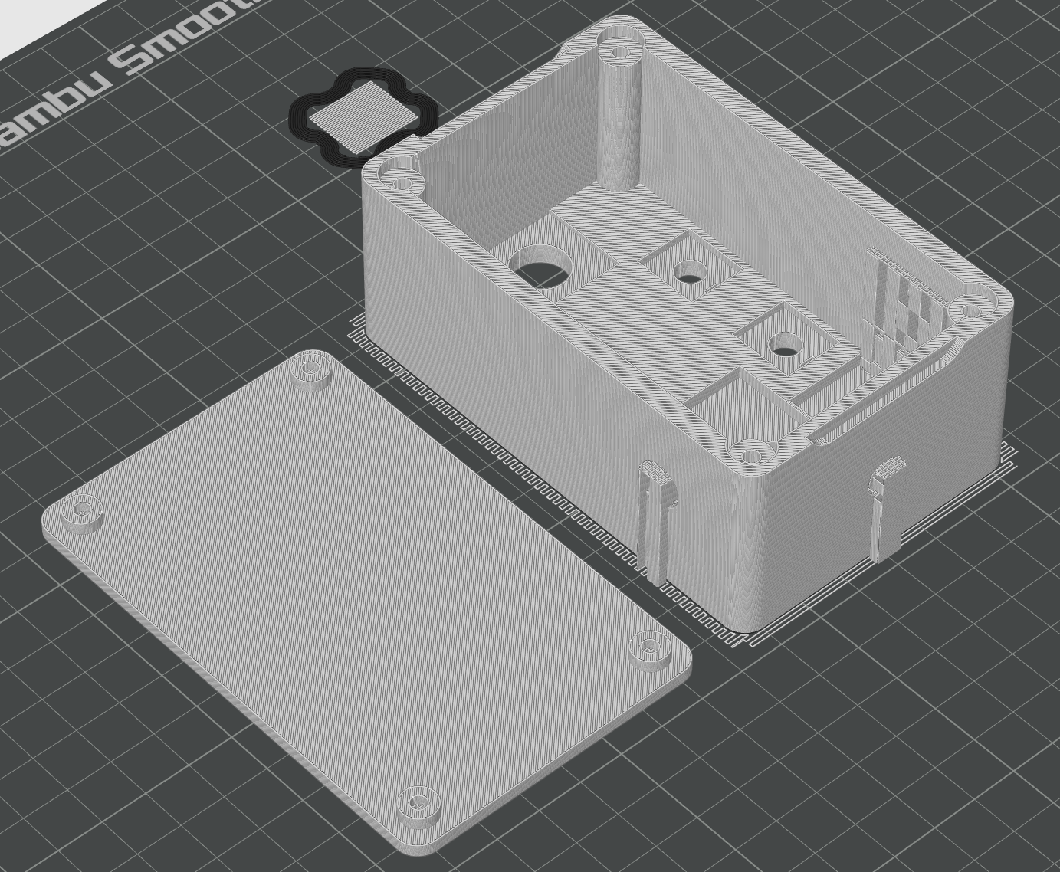
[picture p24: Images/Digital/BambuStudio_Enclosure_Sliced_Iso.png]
Sliced enclosure
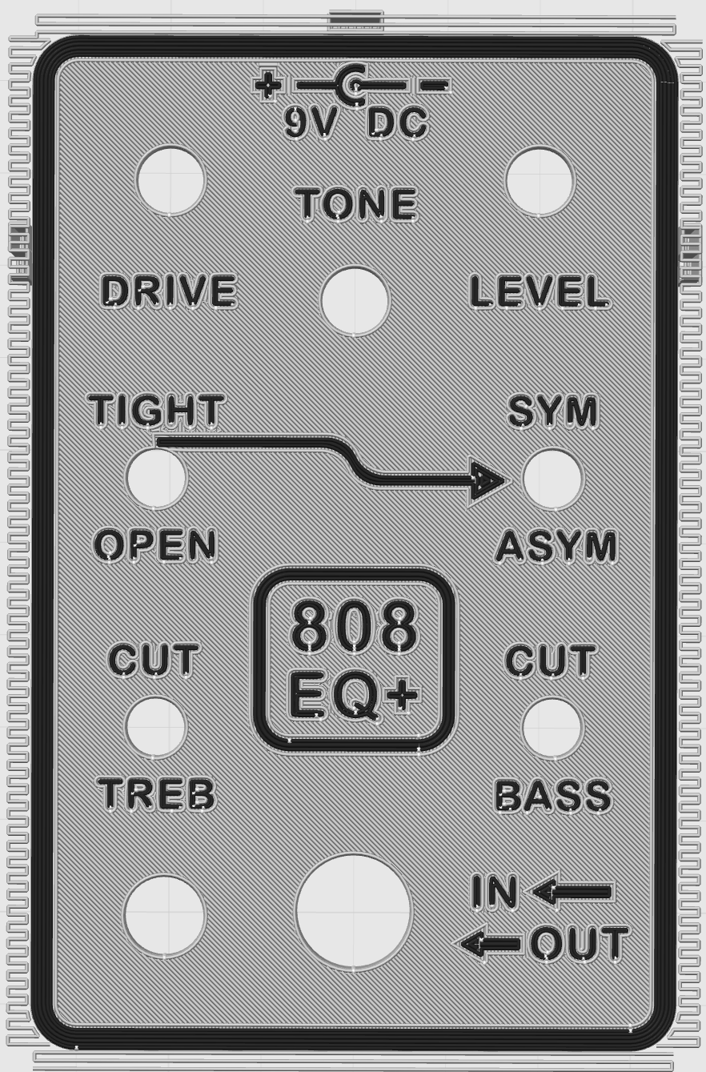
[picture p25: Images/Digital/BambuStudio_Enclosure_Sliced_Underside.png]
Sliced underside of enclosure
|  |  |

### Final Print Files and Build Guidance

The final enclosure geometry, tolerances, component fit, and appearance were physically validated before the print files were released. The design was developed around the components listed in the project BOM and balances label clarity, structural strength, accessible assembly, and a compact internal layout.

Both STL geometry and prepared 3MF projects are provided in [`Design/3D_Printing`](Design/3D_Printing/). The STL files preserve broad slicer compatibility, while the 3MF projects retain the validated Bambu Studio arrangement and provide a reference for the intended orientation, object separation, and color assignments.

Printer-specific results will still vary, so practical slicer settings, support checks, seam placement, part orientation, and pre-assembly fit guidance are maintained in [Part 3 of the build guide](BUILD_GUIDE.md#3-print-and-verify-the-enclosure-parts).

---

Return to the [main project README](README.md).

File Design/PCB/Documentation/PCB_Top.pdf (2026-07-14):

R3 | N

D6

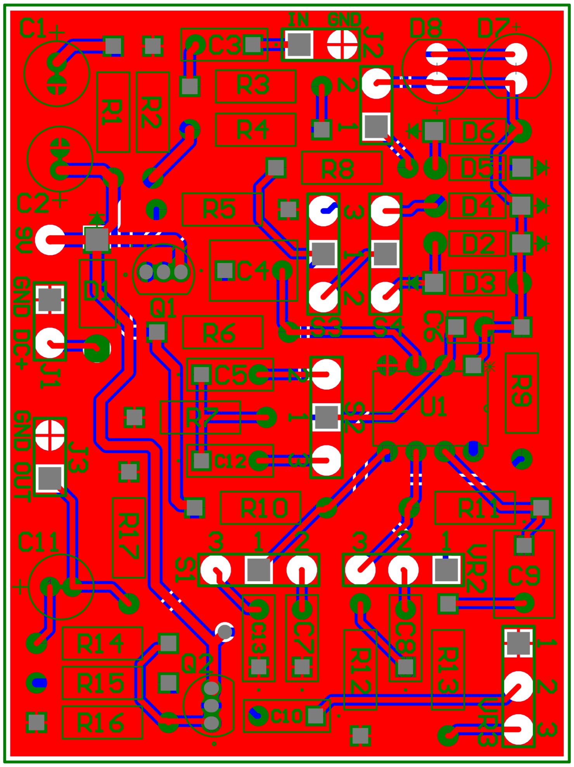
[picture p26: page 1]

R9

# C1+ IN GND D8 C3 R1 R2

+
R4 1

R8

C2+ | R5 | 3 | D4 R12 J3 J1 ⁹U GND DC+ GND OUT

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
R10 | R1
3 | 1 | 3
C9

1

2 3

# UR2 URB

R13

C8
R14
R12

C13

R15
R16 | C10




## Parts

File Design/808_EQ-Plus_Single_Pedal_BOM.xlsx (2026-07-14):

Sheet: Single Pedal BOM
Category | Qty / Pedal | Description | Manufacturer | Manufacturer Part No. | Supplier | Supplier SKU | Unit Cost | Allocated Cost | Purchased Pack | Pack Cost | Notes | Source / Datasheet
Capacitor | 1 | Film capacitor 0.022 µF, 5%, 100 V, radial | KEMET | R82EC2220SH50J | DigiKey | 399-11868-1-ND | $0.30 | $0.30 | 1 each | $0.30 | Quantities from DigiKey ModdedTS Parts List (https://www.digikey.com/en/mylists/list/OOEIMICZI4) | https://content.kemet.com/datasheets/KEM_F3101_R82.pdf
Capacitor | 2 | Film capacitor 0.047 µF, 5%, 100 V, radial | KEMET | R82EC2470SH60J | DigiKey | 399-R82EC2470SH60JCT-ND | $0.31 | $0.62 | 2 each | $0.62 | Quantities from DigiKey ModdedTS Parts List (https://www.digikey.com/en/mylists/list/OOEIMICZI4) | https://content.kemet.com/datasheets/KEM_F3101_R82.pdf
Capacitor | 1 | Film capacitor 0.082 µF, 5%, 100 V, radial | KEMET | R82EC2820SH60J | DigiKey | 399-R82EC2820SH60JCT-ND | $0.51 | $0.51 | 1 each | $0.51 | Quantities from DigiKey ModdedTS Parts List | https://content.kemet.com/datasheets/KEM_F3101_R82.pdf
Capacitor | 1 | Film capacitor 0.1 µF, 10%, 63 V, radial | KEMET | R82DC3100AA50K | DigiKey | 399-9684-ND | $0.28 | $0.28 | 1 each | $0.28 | Quantities from DigiKey ModdedTS Parts List | https://yageogroup.com/content/datasheet/asset/file/KEM_F3101_R82
Capacitor | 2 | Film capacitor 0.22 µF, 5%, 63 V, radial | KEMET | R82DC3220Z360J | DigiKey | 399-9688-ND | $0.31 | $0.62 | 2 each | $0.62 | Quantities from DigiKey ModdedTS Parts List | https://yageogroup.com/content/datasheet/asset/file/KEM_F3101_R82
Capacitor | 2 | Film capacitor 1 µF, 10%, 63 V, radial | KEMET | R82DC4100AA60K | DigiKey | 399-11515-ND | $0.60 | $1.20 | 2 each | $1.20 | Quantities from DigiKey ModdedTS Parts List | https://yageogroup.com/content/datasheet/asset/file/KEM_F3101_R82
Capacitor | 1 | Ceramic capacitor 51 pF, C0G/NP0, 25 V, radial | KEMET | C315C510K3G5TA | DigiKey | C315C510K3G5TA-ND | $0.39 | $0.39 | 1 each | $0.39 | Quantities from DigiKey ModdedTS Parts List | https://yageogroup.com/content/datasheet/asset/file/KEM_C1049_GOLDMAX_C0G
Capacitor | 1 | Electrolytic capacitor 100 µF, 25 V, radial | Rubycon | 25PX100MEFC5X11 | DigiKey | 1189-1224-ND | $0.22 | $0.22 | 1 each | $0.22 | Quantities from DigiKey ModdedTS Parts List | https://www.rubycon.co.jp/wp-content/uploads/catalog-aluminum/PX.pdf
Capacitor | 1 | Electrolytic capacitor 47 µF, 35 V, radial | Rubycon | 35YXJ47M5X11 | DigiKey | 1189-2919-ND | $0.22 | $0.22 | 1 each | $0.22 | Quantities from DigiKey ModdedTS Parts List | https://www.rubycon.co.jp/wp-content/uploads/catalog-aluminum/YXJ.pdf
Capacitor | 1 | Electrolytic capacitor 10 µF, 63 V, radial | Rubycon | 63PX10MEFC5X11 | DigiKey | 1189-1474-ND | $0.23 | $0.23 | 1 each | $0.23 | Quantities from DigiKey ModdedTS Parts List | https://www.rubycon.co.jp/wp-content/uploads/catalog-aluminum/PX.pdf
LED | 2 | Red diffused LED, 5 mm, through-hole | Würth Elektronik | 151051RS11000 | DigiKey | 732-5016-ND | $0.16 | $0.32 | 2 each | $0.32 | Quantities from DigiKey ModdedTS Parts List | https://www.we-online.com/components/products/datasheet/151051RS11000.pdf
Diode | 5 | 1N4148 switching diode, DO-35 | onsemi | 1N4148-T50R | DigiKey | 1N4148-T50RCT-ND | $0.10 | $0.50 | 5 each | $0.50 | Quantities from DigiKey ModdedTS Parts List | https://www.onsemi.com/pub/Collateral/1N914-D.PDF
Diode | 1 | 1N4007 rectifier diode, axial | onsemi | 1N4007FFG | DigiKey | 1N4007FFGOSCT-ND | $0.23 | $0.23 | 1 each | $0.23 | Quantities from DigiKey ModdedTS Parts List | https://www.onsemi.com/pub/Collateral/1N4001-D.PDF
Transistor | 2 | 2N5089 NPN transistor, TO-92 | Central Semiconductor | 2N5089 PBFREE | DigiKey | 1514-2N5089PBFREE-ND | $0.81 | $1.62 | 2 each | $1.62 | Quantities from DigiKey ModdedTS Parts List | https://my.centralsemi.com/datasheets/2N5088%20SERIES.PDF
Resistor | 1 | 100 Ω, 1%, 1/4 W axial resistor | YAGEO | MFR-25FRF52-100R | DigiKey | 13-MFR-25FRF52-100RCT-ND | $0.10 | $0.10 | 1 each | $0.10 | Quantities from DigiKey ModdedTS Parts List | https://yageogroup.com/content/Resource%20Library/Datasheet/YAGEO-MFR_DATASHEET.pdf
Resistor | 1 | 220 Ω, 1%, 1/4 W axial resistor | YAGEO | MFR-25FTE52-220R | DigiKey | 13-MFR-25FTE52-220RCT-ND | $0.10 | $0.10 | 1 each | $0.10 | Quantities from DigiKey ModdedTS Parts List | https://yageogroup.com/content/Resource%20Library/Datasheet/YAGEO-MFR_DATASHEET.pdf
Resistor | 4 | 1 kΩ, 1%, 1/4 W axial resistor | YAGEO | MFR-25FRF52-1K | DigiKey | 13-MFR-25FRF52-1KCT-ND | $0.10 | $0.40 | 4 each | $0.40 | Quantities from DigiKey ModdedTS Parts List | https://yageogroup.com/content/Resource%20Library/Datasheet/YAGEO-MFR_DATASHEET.pdf
Resistor | 1 | 3.3 kΩ, 1%, 1/4 W axial resistor | YAGEO | MFR-25FTE52-3K3 | DigiKey | 13-MFR-25FTE52-3K3CT-ND | $0.10 | $0.10 | 1 each | $0.10 | Quantities from DigiKey ModdedTS Parts List | https://yageogroup.com/content/Resource%20Library/Datasheet/YAGEO-MFR_DATASHEET.pdf
Resistor | 1 | 4.7 kΩ, 1%, 1/4 W axial resistor | YAGEO | MFR-25FTE52-4K7 | DigiKey | 13-MFR-25FTE52-4K7CT-ND | $0.10 | $0.10 | 1 each | $0.10 | Quantities from DigiKey ModdedTS Parts List | https://yageogroup.com/content/Resource%20Library/Datasheet/YAGEO-MFR_DATASHEET.pdf
Resistor | 7 | 10 kΩ, 1%, 1/4 W axial resistor | YAGEO | MFR-25FRF52-10K | DigiKey | 13-MFR-25FRF52-10KCT-ND | $0.10 | $0.70 | 7 each | $0.70 | Quantities from DigiKey ModdedTS Parts List | https://yageogroup.com/content/Resource%20Library/Datasheet/YAGEO-MFR_DATASHEET.pdf
Resistor | 1 | 51 kΩ, 1%, 1/4 W axial resistor | YAGEO | MFR-25FTE52-51K | DigiKey | 13-MFR-25FTE52-51KCT-ND | $0.10 | $0.10 | 1 each | $0.10 | Quantities from DigiKey ModdedTS Parts List | https://yageogroup.com/content/Resource%20Library/Datasheet/YAGEO-MFR_DATASHEET.pdf
Resistor | 2 | 510 kΩ, 1%, 1/4 W axial resistor | YAGEO | MFR-25FTE52-510K | DigiKey | 13-MFR-25FTE52-510KCT-ND | $0.10 | $0.20 | 2 each | $0.20 | Quantities from DigiKey ModdedTS Parts List | https://yageogroup.com/content/Resource%20Library/Datasheet/YAGEO-MFR_DATASHEET.pdf
IC | 1 | RC4558 dual op-amp, DIP-8 | Texas Instruments | RC4558IP | DigiKey | 296-17460-5-ND | $0.38 | $0.38 | 1 each | $0.38 | Quantities from DigiKey ModdedTS Parts List | https://www.ti.com/lit/gpn/rc4558
Connector | 1 | 2.1 × 5.5 mm DC power jack, solder terminals | MPD | EJ501A | DigiKey | EJ501A-ND | $1.89 | $1.89 | 1 each | $1.89 | Quantities from DigiKey ModdedTS Parts List | https://www.memoryprotectiondevices.com/datasheets/EJ501A/EJ501A-datasheet.pdf
LED | 1 | Blue diffused LED, 5 mm, through-hole | Würth Elektronik | 151051BS04000 | DigiKey | 732-5015-ND | $0.25 | $0.25 | 1 each | $0.25 | Quantities from DigiKey ModdedTS Parts List | https://www.we-online.com/components/products/datasheet/151051BS04000.pdf
Socket | 1 | 8-position machined-pin DIP socket | Preci-Dip | 110-87-308-41-001101 | DigiKey | 1212-1003-ND | $0.49 | $0.49 | 1 each | $0.49 | Quantities from DigiKey ModdedTS Parts List
Connector | 2 | 1/4" mono panel jack, Switchcraft #11 | Switchcraft | 11 | Love My Switches | #11 | $3.23 | $6.46 | 10-pack | $31.20 | Also available for a good price on Amazon (https://a.co/d/06v0HEmx) | https://lovemyswitches.com/1-4-mono-jack-switchcraft-11/
Potentiometer | 1 | 16 mm A500K audio-taper potentiometer, 18T knurled shaft, solder lug |  | A500K | Love My Switches |  | $0.74 | $0.74 | 5-pack | $3.70 | Drive potentiometer | https://lovemyswitches.com/16mm-potentiometers-18t-knurled-shaft-solder-lug/
Potentiometer | 1 | 16 mm B20K linear potentiometer, 18T knurled shaft, solder lug |  | B20K | Love My Switches |  | $0.74 | $0.74 | 5-pack | $3.70 | Tone potentiometer | https://lovemyswitches.com/16mm-potentiometers-18t-knurled-shaft-solder-lug/
Potentiometer | 1 | 16 mm B100K linear potentiometer, 18T knurled shaft, solder lug |  | B100K | Love My Switches |  | $0.74 | $0.74 | 5-pack | $3.70 | Level potentiometer | https://lovemyswitches.com/16mm-potentiometers-18t-knurled-shaft-solder-lug/
Footswitch | 1 | 3PDT latching stomp footswitch with breakout PCB and washers |  |  | Amazon | B01HJDOF2Y | $2.59 | $2.59 | 10-pack | $25.90 | Package price retained; allocated cost assumes one switch per pedal. | https://www.amazon.com/dp/B01HJDOF2Y
Switch | 4 | MTS-102 miniature SPDT ON-ON toggle switch, 3-pin |  | MTS-102 | Amazon | B0CZ6XZ2P9 | $0.35 | $1.40 | 20-pack | $6.99 | Four switches used for pedal modifications; allocated cost assumes 20 switches per pack. | https://www.amazon.com/dp/B0CZ6XZ2P9

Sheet: Cost Summary
Single-Pedal Cost Summary
Supplier | Allocated Parts Cost | Notes
DigiKey | $12.07 | One-pedal quantities from https://www.digikey.com/en/mylists/list/OOEIMICZI4
Love My Switches | $8.68 | One-pedal quantities from https://lovemyswitches.com/
Amazon | $32.89 | Bulk-package prices rather than per-pedal cost.
Estimated parts total: | $53.64 | Excludes PCB fabrication, filament, wire, solder, hardware, tax, and shipping.
Estimated per-pedal cost: | $24.74 | Uses per-part cost of Amazon orders rather than cost of full bulk packages

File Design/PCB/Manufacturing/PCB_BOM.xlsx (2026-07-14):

Line # | Name | Description | Designator | Quantity | Manufacturer 1 | Manufacturer Part Number 1 | Manufacturer Lifecycle 1 | Supplier 1 | Supplier Part Number 1 | Supplier Unit Price 1 | Supplier Subtotal 1
 | 47uF | 47 µF 35 V Aluminum Electrolytic Capacitors Radial, Can 5000 Hrs @ 105°C | C1 | 1
 | 100uF | 100 µF 25 V Aluminum Electrolytic Capacitors Radial, Can 1000 Hrs @ 105°C | C2 | 1
 | 22nF | 0.022 µF Film Capacitor 63V 100V Polyester, Polyethylene Terephthalate (PET), Metallized - Stacked Radial | C3 | 1
 | 1uF | 1 µF Film Capacitor 40V 63V Polyester, Polyethylene Terephthalate (PET), Metallized - Stacked Radial | C4, C9 | 2
 | 47nF | 0.047 µF Film Capacitor 63V 100V Polyester, Polyethylene Terephthalate (PET), Metallized - Stacked Radial | C5, C13 | 2
 | 51pF | 51 pF ±10% 25V Ceramic Capacitor C0G, NP0 Radial | C6 | 1
 | 220nF | 0.22 µF Film Capacitor 40V 63V Polyester, Polyethylene Terephthalate (PET), Metallized - Stacked Radial | C7, C8 | 2
 | 100nF | 0.1 µF Film Capacitor 40V 63V Polyester, Polyethylene Terephthalate (PET), Metallized - Stacked Radial | C10 | 1
 | 10uF | 10 µF 63 V Aluminum Electrolytic Capacitors Radial, Can 1000 Hrs @ 105°C | C11 | 1
 | 82nF | 0.082 µF Film Capacitor 63V 100V Polyester, Polyethylene Terephthalate (PET), Metallized - Stacked Radial | C12 | 1
 | 1N4007 | Diode 1000 V 1A Through Hole Axial | D1 | 1
 | 1N4148 | Diode 100 V 200mA Through Hole DO-35 | D2, D3, D4, D5, D6 | 5
 | Red, 2.1V, 60° | WL-TMRC Mono-color Round Color, THT, D5.9 x H8.7mm, Red, 2.1V, 60° | D7, D8 | 2
 | 2.1mm DC Jack | Power Barrel Connector Jack 2.10mm ID (0.083"), 5.50mm OD (0.217") Chassis Mount | J1 | 1 | Memory Protection Devices | EJ501A | Unknown | DigiKey | EJ501A-ND | 1.89 | 1.89
 | Input Jack | 6.35mm (0.250", 1/4") - Headphone Phone Jack Mono Connector Solder Eyelet(s) | J2 | 1 | Switchcraft | 11 | Volume Production | RS (Formerly Allied Electronics) | 11 | 4.22 | 4.22
 | Output Jack | 6.35mm (0.250", 1/4") - Headphone Phone Jack Mono Connector Solder Eyelet(s) | J3 | 1 | Switchcraft | 11 | Volume Production | RS (Formerly Allied Electronics) | 11 | 4.22 | 4.22
 | 2N5089 | Bipolar (BJT) Transistor NPN 25 V 50 mA 50MHz 625 mW Through Hole TO-92-3 | Q1, Q2 | 2
 | 10K | 10 kOhms ±1% 0.25W, 1/4W Through Hole Resistor Axial Metal Film | R1, R2, R5, R6, R10, R16, R17 | 7
 | 1K | 1 kOhms ±1% 0.25W, 1/4W Through Hole Resistor Axial Metal Film | R3, R9, R11, R13 | 4
 | 510K | 510 kOhms ±1% 0.25W, 1/4W Through Hole Resistor Axial Metal Film | R4, R15 | 2
 | 4.7K | 4.7 kOhms ±1% 0.25W, 1/4W Through Hole Resistor Axial Metal Film | R7 | 1
 | 51K | 51 kOhms ±1% 0.25W, 1/4W Through Hole Resistor Axial Metal Film | R8 | 1
 | 220 | 220 Ohms ±1% 0.25W, 1/4W Through Hole Resistor Axial Metal Film | R12 | 1
 | 100 | 100 Ohms ±1% 0.25W, 1/4W Through Hole Resistor Axial Metal Film | R14 | 1
 | SPDT_TOGGLE_SWITCH_OFFBOARD | Toggle Switch SPDT Panel Mount | S1, S2, S3, S4 | 4
 | RC4558IP | Standard (General Purpose) Amplifier 2 Circuit Differential 8-PDIP | U1 | 1
 | A500K | A500K, 16mm Potentiometers - 18T Knurled Shaft - Solder Lug | VR1 | 1
 | B20K | B20K, 16mm Potentiometers - 18T Knurled Shaft - Solder Lug | VR2 | 1
 | B100K | B100K, 16mm Potentiometers - 18T Knurled Shaft - Solder Lug | VR3 | 1

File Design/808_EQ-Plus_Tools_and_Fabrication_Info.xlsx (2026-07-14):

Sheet: Tools & Equipment
Tools, Equipment, and Shared Supplies
Category | Item | Supplier | Quantity / Pack | Price | Source | Notes
3D Printing | Bambu Lab H2S 3D printer | Bambu Lab | 1 printer | $1249.00 | https://us.store.bambulab.com/products/h2s | The H2S natively supports multi-color printing; however, multi-color prints can produce significant purge waste.
3D Printing | Bambu PLA Basic – Jade White | Bambu Lab | 1 kg spool | $19.99 | https://us.store.bambulab.com/products/pla-basic-filament | Used for most of the enclosure and for accent areas on the knobs and LED holder.
3D Printing | Bambu PLA Basic – Black | Bambu Lab | 1 kg spool | $19.99 | https://us.store.bambulab.com/products/pla-basic-filament | Used for accents on the enclosure face and as the primary color of the knobs and LED holder.
3D Printing | Bambu Smooth PEI Plate | Bambu Lab | 1 plate | $61.99 | https://us.store.bambulab.com/products/bambu-smooth-pei-plate | Used only to obtain a cleaner first-surface finish. A textured plate can work, but the face may appear shinier and the text/labels may be more blobby and harder to read.
Power & Soldering | PINECIL Smart Mini Portable Soldering Iron V2 | PINE64 | 1 iron | $25.99 | https://pine64.com/product/pinecil-smart-mini-portable-soldering-iron/ | Somewhat overkill for this level of soldering, but it is an excellent and versatile soldering iron.
Power & Soldering | DIAIARY adjustable DC bench power supply, 32 V / 10 A | Amazon | 1 supply |  | https://www.amazon.com/dp/B0C17NLZNH | Used to power the Pinecil and test the guitar pedal. The Pinecil and pedal use opposite connector polarities, so verify polarity before connecting either device.
Power & Soldering | PNGKNYOCN banana plug to 2.1 mm DC barrel leads | Amazon | 2-pack | $14.99 | https://www.amazon.com/dp/B0BC1J63RD | Used to power the Pinecil and pedal from the bench supply. Reversing the banana leads swaps the barrel connector polarity.
Workholding | KOTTO helping hands soldering stand | KOTTO | 1 stand | $39.99 | https://www.amazon.com/dp/B07MDKXNPC | Extremely valuable for soldering both on-board and off-board components; highly recommended.
Soldering Consumable | MAIYUM 63/37 rosin-core solder, 0.8 mm | Amazon | 50 g spool | $8.99 | https://www.amazon.com/dp/B075WB98FJ | Required for assembly. Rosin core helps solder wet PCB through-holes and off-board terminals. Avoid breathing fumes; use a fan or other ventilation while soldering.
Desoldering | Teenitor solder sucker / desoldering pump | Amazon | 3-pack | $7.01 | https://a.co/d/gTplbbg | Optional. Other solder-removal methods are available, but this is useful for occasional rework.
Wire | Fermerry 22 AWG stranded silicone wire | Amazon | 6 colors × 25 ft | $15.99 | https://a.co/d/2dcg7iv | Preferred for off-board wiring because it tolerates compression and movement better and is less likely to fatigue and break.
Wire | TUOFENG 22 AWG solid-core hookup wire | Amazon | 6 colors × 30 ft | $15.49 | https://a.co/d/1wuelIb | Useful for breadboarding and short perfboard connections, but less suitable for off-board wiring because repeated movement can cause it to break.
Hand Tools | kaverme precision tweezer set | Amazon | 3-piece set | $5.99 | https://www.amazon.com/dp/B0BNNGC3Q2 | Optional, but useful for handling, placing, and manipulating small components and wire.
Hand Tools | IDEAL Reflex wire stripper | IDEAL / Amazon | 1 tool | $22.00 | https://www.amazon.com/dp/B000B632YO | Very useful for preparing wire before soldering it to the PCB or off-board components.
Fasteners | Fgruh M2/M3/M4/M5 metric screw assortment | Amazon | 1760-piece set | $21.99 | https://www.amazon.com/dp/B0FJFVG31G | Only four M3×12 screws are required per pedal. M3×16 screws also work.
Not every tool, supply, or exact product listed here is required. Equivalent alternatives will generally work. Some items are optional, including the tweezers, solid-core wire, solder sucker, and multiple filament colors.

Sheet: 3D Printing Stats
Per-Pedal 3D Printing Statistics
Printed Part | Quantity | Material | Mass (g) | Print Time | Estimated Cost
Enclosure set: housing, labels, and bottom plate | 1 | White + black Bambu PLA Basic | 120 | 3 h 30 min | $3.00
Knobs | 3 | White + black Bambu PLA Basic | 14 | 35 min | $0.35
LED holder | 1 | White + black Bambu PLA Basic | 3.5 | 20 min | $0.10
Total |  |  | 137.5 | 4 h 25 min | $3.45
Printing notes
The knobs and LED holder are small multi-color prints, so purge waste can be a large fraction of their material use. Print several at the same time to spread the purge cost across more parts and keep spares available in case a knob or LED holder breaks.

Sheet: Wrench Reference
Enclosure Hardware Wrench Reference
Hardware | Nut Size | Wrench Used | Notes
SPDT toggle switch | 1/3 in | 9 mm wrench | 9 mm fit the supplied nut.
3PDT stomp footswitch | 14 mm | 9/16 in wrench | 9/16 in is the close SAE equivalent used.
16 mm potentiometers | 10 mm | 10 mm wrench | Use the same size for all three pots.
DC barrel jack | 10 mm | 10 mm wrench | Same wrench size as the potentiometers.
Switchcraft #11 mono jack | 1/2 in | 13 mm wrench | 13 mm fit the supplied jack nut.

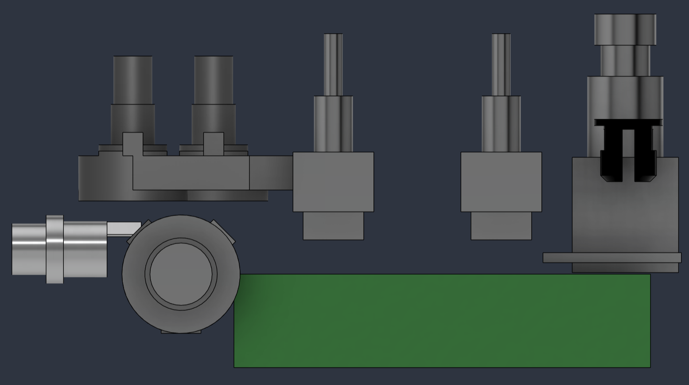
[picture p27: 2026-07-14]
Images/Digital/Fusion_Components_Side.png

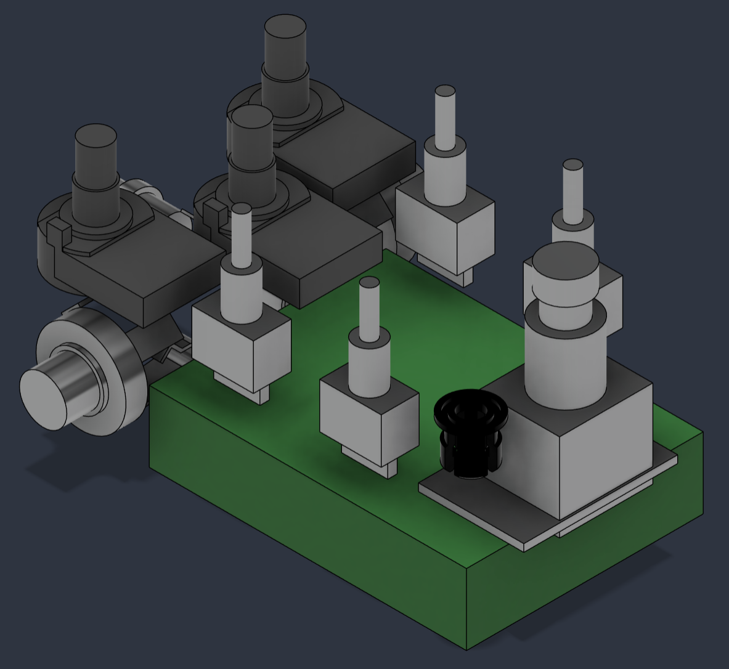
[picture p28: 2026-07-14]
Images/Digital/Fusion_Components_Iso.png

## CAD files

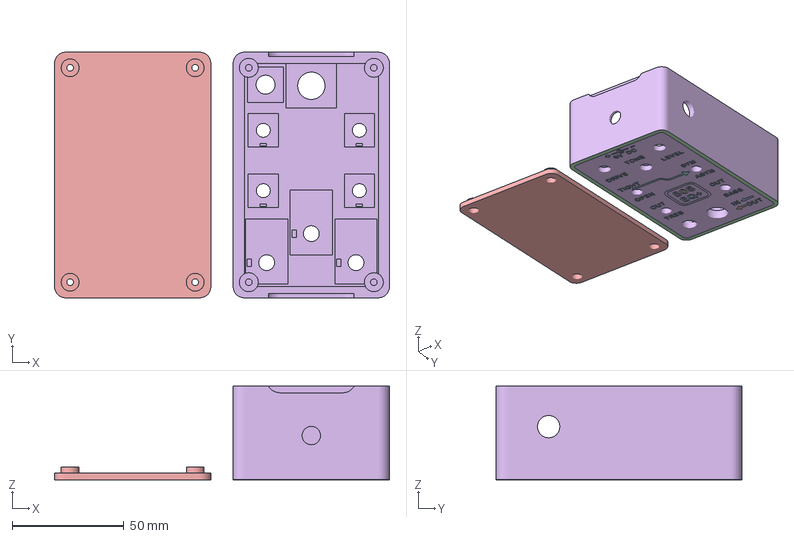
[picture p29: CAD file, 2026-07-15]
Design/3D_Printing/3MF/ModdedTSEnclosure_v1.3.3mf
150.0 x 110.0 x 42.0 mm
Modded_TS_Enclosure_v1.3.stl_2
Modded_TS_Enclosure_v1.3.stl_3
Modded_TS_Enclosure_v1.3.stl_4
Modded_TS_Enclosure_v1.3.stl_5
Modded_TS_Enclosure_v1.3.stl_6
Modded_TS_Enclosure_v1.3.stl_7
Modded_TS_Enclosure_v1.3.stl_8
Modded_TS_Enclosure_v1.3.stl_9
Modded_TS_Enclosure_v1.3.stl_10
Modded_TS_Enclosure_v1.3.stl_11
Modded_TS_Enclosure_v1.3.stl_12
Modded_TS_Enclosure_v1.3.stl_13
Modded_TS_Enclosure_v1.3.stl_14
Modded_TS_Enclosure_v1.3.stl_15
Modded_TS_Enclosure_v1.3.stl_16
Modded_TS_Enclosure_v1.3.stl_17
Modded_TS_Enclosure_v1.3.stl_18
Modded_TS_Enclosure_v1.3.stl_19
Modded_TS_Enclosure_v1.3.stl_20
Modded_TS_Enclosure_v1.3.stl_21
Modded_TS_Enclosure_v1.3.stl_22
Modded_TS_Enclosure_v1.3.stl_23
Modded_TS_Enclosure_v1.3.stl_24
Modded_TS_Enclosure_v1.3.stl_25
Modded_TS_Enclosure_v1.3.stl_26
Modded_TS_Enclosure_v1.3.stl_27
Modded_TS_Enclosure_v1.3.stl_28
Modded_TS_Enclosure_v1.3.stl_29
Modded_TS_Enclosure_v1.3.stl_30
Modded_TS_Enclosure_v1.3.stl_31
Modded_TS_Enclosure_v1.3.stl_32
Modded_TS_Enclosure_v1.3.stl_33
Modded_TS_Enclosure_v1.3.stl_34
Modded_TS_Enclosure_v1.3.stl_35
Modded_TS_Enclosure_v1.3.stl_36
Modded_TS_Enclosure_v1.3.stl_37
Modded_TS_Enclosure_v1.3.stl_38
Modded_TS_Enclosure_v1.3.stl_39
Modded_TS_Enclosure_v1.3.stl_40
Modded_TS_Enclosure_v1.3.stl_41
Modded_TS_Enclosure_v1.3.stl_42
Modded_TS_Enclosure_v1.3.stl_43
Modded_TS_Enclosure_v1.3.stl_44
Modded_TS_Enclosure_v1.3.stl_45
Modded_TS_Enclosure_v1.3.stl_46
Modded_TS_Enclosure_v1.3.stl_47
Modded_TS_Enclosure_v1.3.stl_48
Modded_TS_Enclosure_v1.3.stl_49
Modded_TS_Enclosure_v1.3.stl_50
Modded_TS_Enclosure_v1.3.stl_51
Modded_TS_Enclosure_v1.3.stl_52
Modded_TS_Enclosure_v1.3.stl_53
Modded_TS_Enclosure_v1.3.stl_54
Modded_TS_Enclosure_v1.3.stl_55
Modded_TS_Enclosure_v1.3.stl_56
Modded_TS_Enclosure_v1.3.stl_57
Modded_TS_Enclosure_v1.3.stl_58
Modded_TS_Enclosure_v1.3.stl_59
Modded_TS_Enclosure_v1.3.stl_60
Modded_TS_Enclosure_v1.3.stl_61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

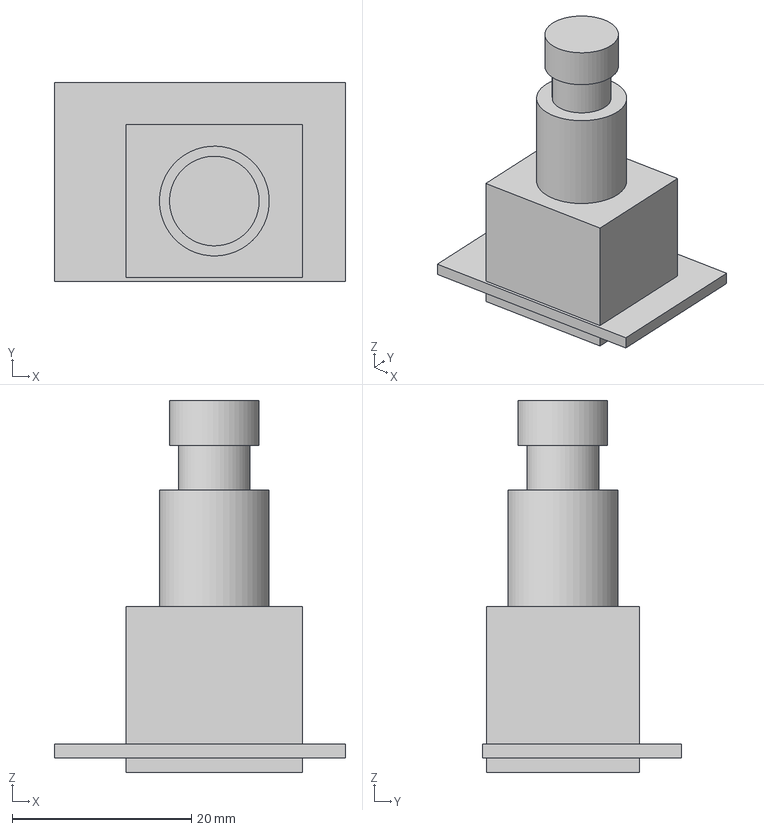
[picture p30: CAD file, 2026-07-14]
Design/CAD/True_Bypass_Switch.step
32.5 x 22.2 x 41.5 mm

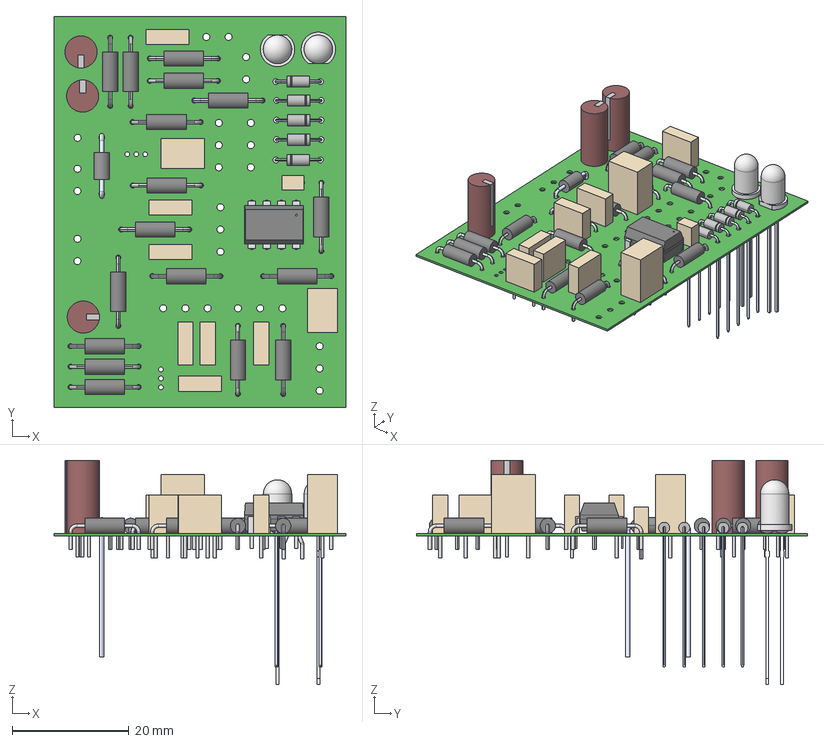
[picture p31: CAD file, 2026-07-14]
Design/PCB/Mechanical/Modded_TS_PCB.step
50.0 x 67.0 x 38.4 mm
STEP-WL-TMRC-5mm-wos-rev1 x 2
1N4148-T50R x 5
1N4007FFG

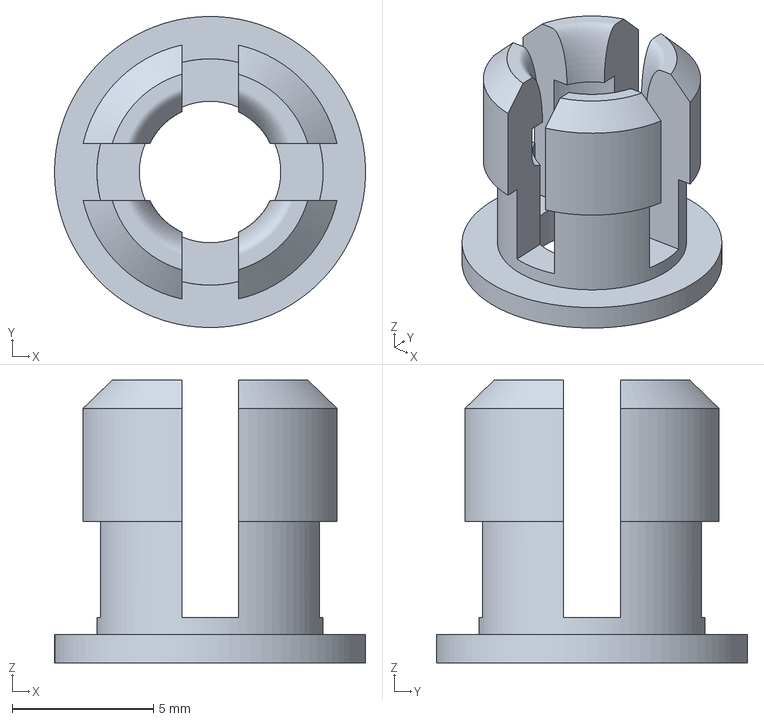
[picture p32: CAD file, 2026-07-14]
Design/3D_Printing/3MF/LED_Holder_Multicolor.3mf
11.0 x 11.0 x 10.0 mm
LED Holder.stl_1
LED Holder.stl_2

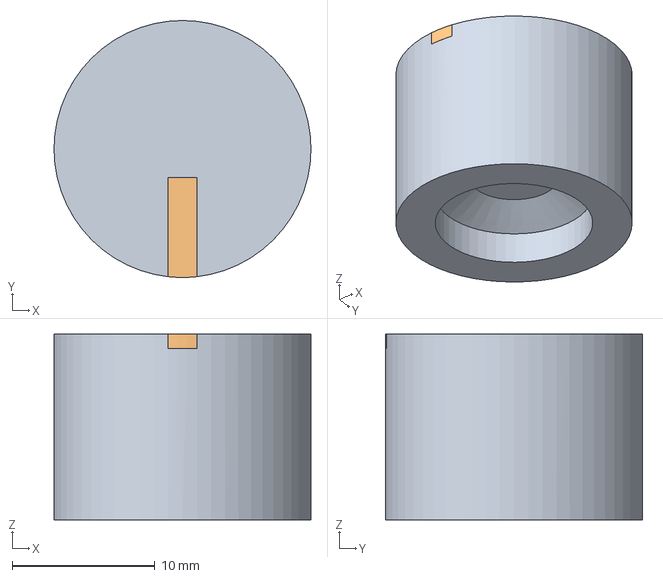
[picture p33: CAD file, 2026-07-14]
Design/CAD/Knob_Smooth_Dia18.step
18.0 x 18.0 x 13.0 mm

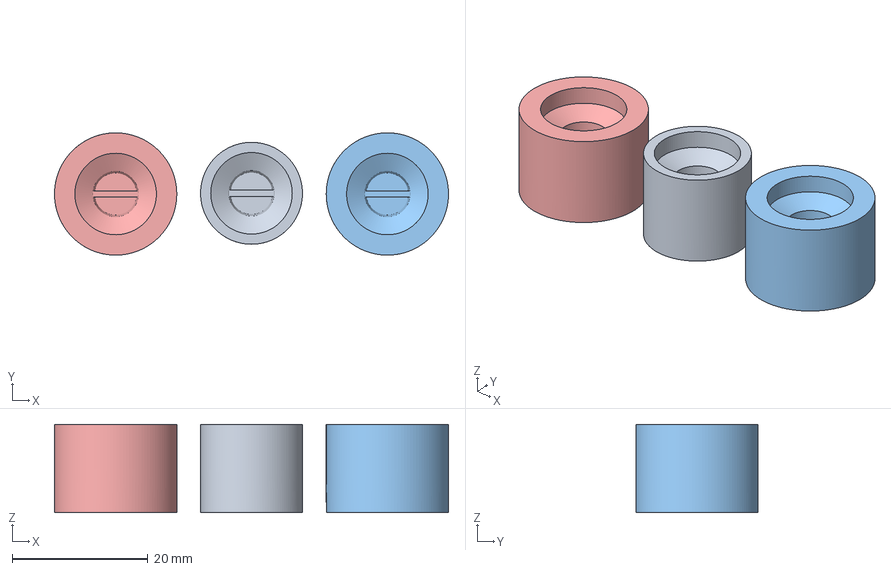
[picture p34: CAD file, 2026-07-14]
Design/3D_Printing/3MF/Knobs_Multicolor.3mf
58.0 x 18.0 x 13.0 mm
Knob Smooth Dia15.stl_1
Knob Smooth Dia15.stl_2
Knob Smooth Dia18.stl_1 x 2
Knob Smooth Dia18.stl_2 x 2

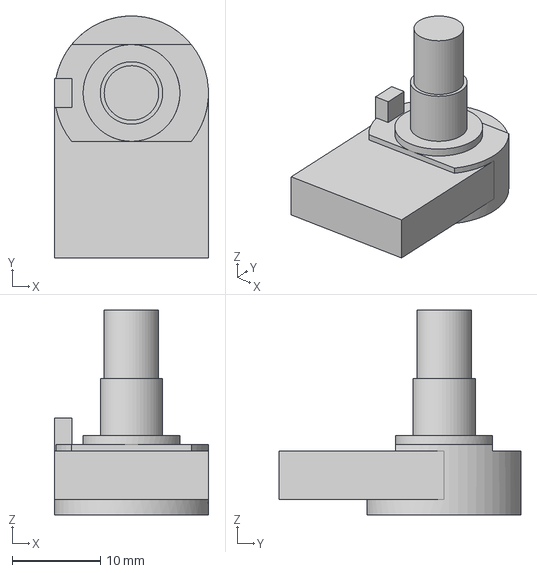
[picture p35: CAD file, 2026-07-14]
Design/CAD/16mm_Pot_18T_Knurled_Shaft_Solder_Lug.step
17.5 x 27.5 x 23.2 mm

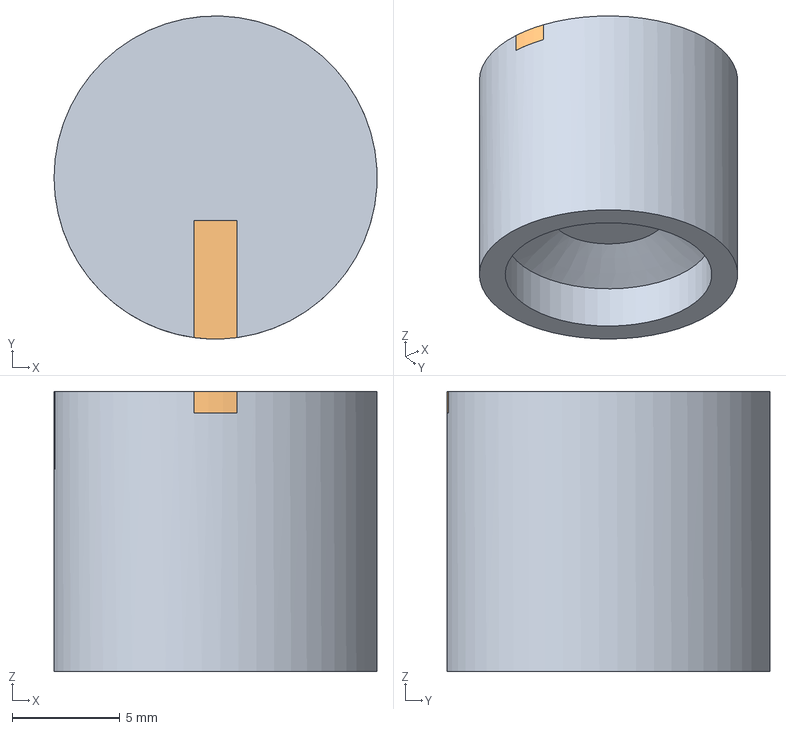
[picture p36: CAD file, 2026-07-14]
Design/CAD/Knob_Smooth_Dia15.step
15.0 x 15.0 x 13.0 mm

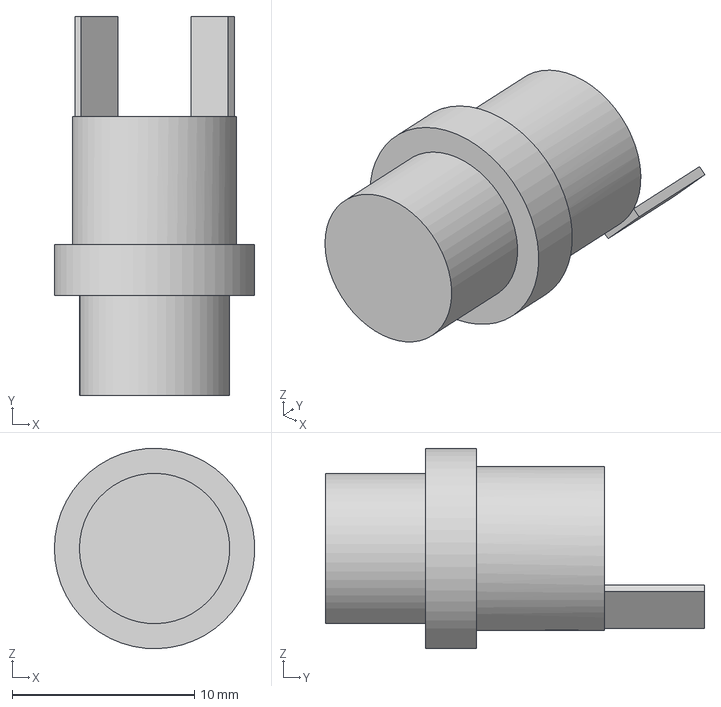
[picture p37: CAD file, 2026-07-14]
Design/CAD/2.1mm_DC_Power_Jack.step
11.0 x 20.8 x 11.0 mm

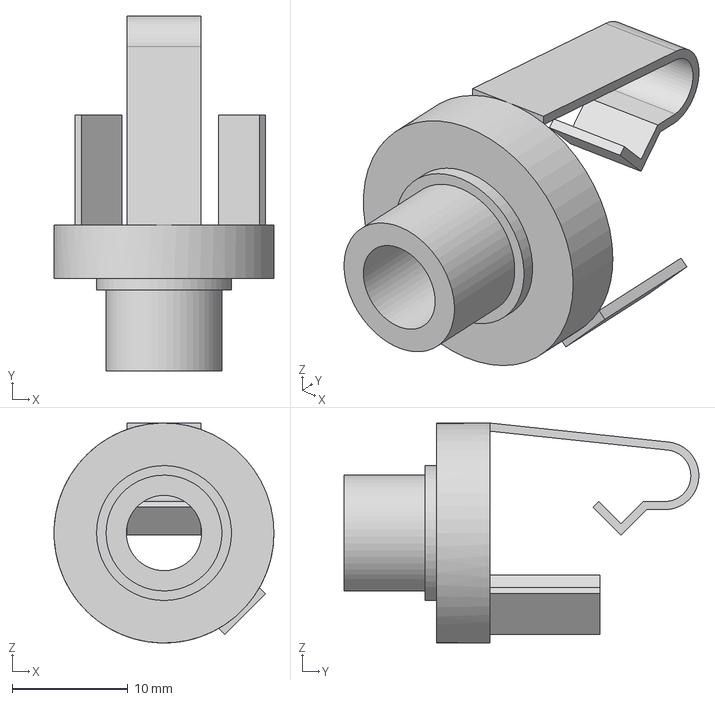
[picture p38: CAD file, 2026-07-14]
Design/CAD/Quarter-Inch_Mono_Jack.step
19.0 x 30.6 x 19.0 mm

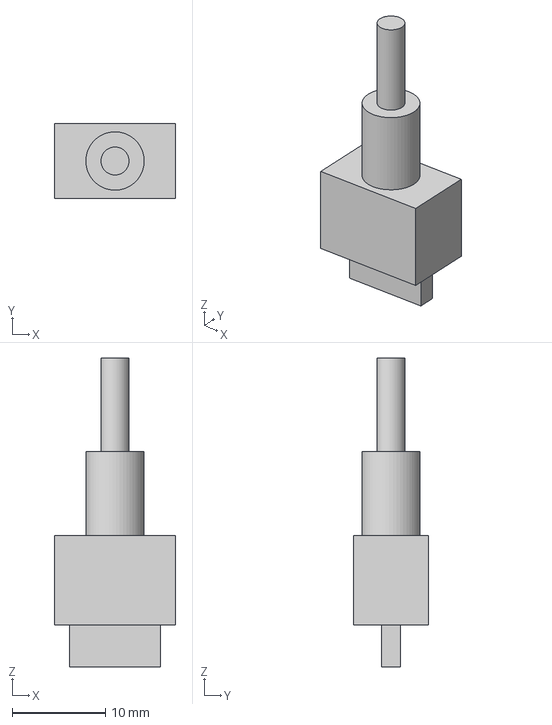
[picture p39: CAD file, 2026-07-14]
Design/CAD/SPDT_Switch.step
13.0 x 8.00 x 33.1 mm

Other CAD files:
Design/CAD/LED_Holder.step
Design/3D_Printing/STL/16mm_Pot_18T_Knurled_Shaft_Solder_Lug.stl
Design/3D_Printing/STL/2.1mm_DC_Power_Jack.stl
Design/3D_Printing/STL/Knob_Smooth_Dia15.stl
Design/3D_Printing/STL/Knob_Smooth_Dia18.stl
Design/3D_Printing/STL/LED_Holder.stl
Design/3D_Printing/STL/Modded_TS_Enclosure_v1.3.stl
Design/3D_Printing/STL/Quarter-Inch_Mono_Jack.stl
Design/3D_Printing/STL/SPDT_Switch.stl
Design/3D_Printing/STL/True_Bypass_Switch.stl

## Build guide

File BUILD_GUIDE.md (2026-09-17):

# 808 EQ+ — DIY Build Guide

This guide provides a practical roadmap for building the 808 EQ+ guitar pedal from the files in this repository. It is intended for hobbyists who are comfortable with basic soldering, through-hole electronics, component identification, and 3D printing.

It is not a step-by-step beginner course. Review the entire guide, the bill of materials, and the technical documentation before ordering parts or beginning assembly.

For an overview of the pedal, see the [main README](README.md). For circuit theory, design decisions, PCB development, and enclosure details, see the [Technical Documentation](TECHNICAL_DOCUMENTATION.md).

## Table of Contents

* [Before You Begin](#before-you-begin)
* [Repository Resources](#repository-resources)
* [Bill of Materials and Tools](#bill-of-materials-and-tools)
* [Build Roadmap](#build-roadmap)
* [1. Review the Design and Plan the Build](#1-review-the-design-and-plan-the-build)
* [2. Choose a Circuit-Board Method and Obtain Components](#2-choose-a-circuit-board-method-and-obtain-components)
* [3. Print and Verify the Enclosure Parts](#3-print-and-verify-the-enclosure-parts)
* [4. Assemble the Circuit Board](#4-assemble-the-circuit-board)
* [5. Test the Circuit Board Outside the Enclosure](#5-test-the-circuit-board-outside-the-enclosure)
* [6. Install the Off-Board Components](#6-install-the-off-board-components)
* [7. Complete the Final Assembly](#7-complete-the-final-assembly)
* [8. Perform Final Validation](#8-perform-final-validation)
* [Troubleshooting Guidelines](#troubleshooting-guidelines)

---

## Before You Begin

This project combines analog electronics, circuit-board assembly, off-board wiring, mechanical assembly, and additive manufacturing. A successful build requires careful inspection and staged testing rather than assembling everything at once and troubleshooting only at the end.

> [!CAUTION]
> A regulated **9 V DC, center-negative pedal supply** is recommended. An external 9 V battery adapter is also supported if its 2.1 mm connector polarity is verified before use. Do not apply more than 9 V; the reverse-polarity diode helps protect against reversed polarity but not excessive input voltage.
>
> The enclosure has no internal battery compartment or automatic battery-disconnection feature. The circuit remains powered while bypassed, so disconnect an external battery when the pedal is not in use. Disconnect all power before modifying the circuit or handling exposed connections.

The enclosure was designed around the specific parts listed in the project BOM. Electrically compatible substitutions may still differ in pinout, lead spacing, body size, shaft diameter, thread length, or mounting depth. Verify every substituted part before ordering or modifying the design files.

## Repository Resources

| Resource | Purpose |
| --- | --- |
| [Main README](README.md) | Project overview, features, controls, status, limitations, and general references |
| [808 EQ+ User Manual](808_EQ-Plus_User_Manual.pdf) | Connector layout, control descriptions, operating modes, starting settings, power guidance, and troubleshooting help |
| [Technical Documentation](TECHNICAL_DOCUMENTATION.md) | Circuit operation, prototype development, PCB design, enclosure design, and engineering details |
| [`808_EQ-Plus_Single_Pedal_BOM.xlsx`](Design/808_EQ-Plus_Single_Pedal_BOM.xlsx) | Components, quantities, part numbers, suppliers, and estimated single-pedal costs |
| [`808_EQ-Plus_Tools_and_Fabrication_Info.xlsx`](Design/808_EQ-Plus_Tools_and_Fabrication_Info.xlsx) | Tools, equipment, fabrication resources, and estimated costs |
| [`Design/PCB`](Design/PCB/) | Altium files, libraries, Gerber files, drill files, and other PCB manufacturing outputs |
| [`Design/3D_Printing`](Design/3D_Printing/) | STL files, prepared 3MF projects, and other enclosure-printing resources |
| [Complete schematic](Images/Digital/Altium_Schematic.png) | Full electrical schematic for assembly and troubleshooting reference |
| [Perfboard DIY layout](Images/Digital/Perfboard_DIYLayout.png) | Layout used for the working perfboard prototype and a starting point for perfboard construction |
| [PCB Design section](TECHNICAL_DOCUMENTATION.md#pcb-design) | PCB construction, socketing, routing, grounding, and manufacturer-selection notes |
| [Enclosure Design and 3D Printing section](TECHNICAL_DOCUMENTATION.md#enclosure-design-and-3d-printing) | Detailed enclosure-design rationale and print-development information |

## Bill of Materials and Tools

### Bill of Materials

The [`808_EQ-Plus_Single_Pedal_BOM.xlsx`](Design/808_EQ-Plus_Single_Pedal_BOM.xlsx) file identifies the parts required to produce one complete pedal. Review it before ordering components or choosing a circuit-board method because the PCB footprints and enclosure were designed around the listed parts.

Many parts can be replaced with electrically and mechanically compatible alternatives. Any substitution should be checked for:

* Electrical value
* Voltage and power rating
* Pinout and polarity
* Package dimensions
* Lead spacing
* Tolerance
* Mechanical fit
* Expected effect on the audio circuit

The estimated cost per pedal is lower when purchasing enough parts for several builds, but bulk purchasing is not required.

### Tools and Equipment

Not every item in the [`808_EQ-Plus_Tools_and_Fabrication_Info.xlsx`](Design/808_EQ-Plus_Tools_and_Fabrication_Info.xlsx) file is required. Some tools are optional conveniences, while others are mainly useful for modification or troubleshooting.

A basic build requires:

* Suitable soldering equipment and solder
* Flush cutters, wire strippers, and common hand tools
* A multimeter
* A regulated 9 V center-negative pedal supply, which is recommended for assembly and testing
* A method for producing the circuit board and printed enclosure parts
* A safe method for testing the completed circuit

Potentially optional items include tweezers, solid-core hookup wire, a solder sucker, multiple filament colors, a smooth build plate, a dedicated bench supply, and advanced measurement equipment.

## Build Roadmap

The recommended build order is:

1. Review the schematic, BOM, controls, and build documentation.
2. Choose between the manufactured PCB and perfboard construction, then inspect all electronic and mechanical components.
3. Print the enclosure, bottom plate, knobs, and LED holder while waiting for any manufactured parts to arrive.
4. Confirm that the printed parts and enclosure-mounted components fit correctly.
5. Populate and inspect the selected circuit board.
6. Test the power network and completed circuit board outside the enclosure.
7. Mount the off-board components to the printed enclosure, then re-test the pedal.
8. Complete the enclosure assembly and validate every operating state.

Do not skip the intermediate fit and electrical checks. They make faults much easier to isolate than testing for the first time after the pedal is fully assembled.

---

## 1. Review the Design and Plan the Build

Before ordering or assembling anything:

1. Review the [main README](README.md) for a general overview of the project.
2. Review the [complete schematic](Images/Digital/Altium_Schematic.png) and relevant parts of the [Technical Documentation](TECHNICAL_DOCUMENTATION.md).
3. Compare the BOM against the parts you already own and identify any intended substitutions.
4. Decide whether to order the provided PCB or construct the circuit on perfboard.
5. Decide whether the experimental components will be soldered directly or installed in machine-pin sockets. See [Socketed and Replaceable Components](TECHNICAL_DOCUMENTATION.md#socketed-and-replaceable-components) for guidance.
6. Decide whether to use the prepared 3MF project or prepare the STL files manually.
7. Confirm that your selected circuit-board method and printer can produce the provided designs.

## 2. Choose a Circuit-Board Method and Obtain Components

The circuit can be constructed using either the provided manufactured PCB design or a hand-wired perfboard layout. Both methods implement the same schematic, which should be treated as the ground-truth reference whenever a connection is uncertain.

### Manufactured PCB Option

The relevant Altium project files and manufacturing outputs are available in [`Design/PCB`](Design/PCB/). JLCPCB was used for the validated build, but another manufacturer may be used if its fabrication requirements are compatible with the provided files.

Before submitting an order:

* Confirm the board outline and dimensions.
* Confirm the copper, solder-mask, silkscreen, drill, and board-outline layers.
* Review the manufacturer’s 2D or 3D preview for missing or duplicated layers.
* Verify the board thickness, copper weight, surface finish, and quantity.
* Retain a copy of the exact manufacturing files that were submitted.

### Perfboard Option

Building the circuit on perfboard can avoid PCB manufacturing and delivery delays and may reduce fabrication costs. The tradeoff is a substantial increase in time, effort, and precision: every connection must be planned and soldered individually, and the holes are not labeled or grouped by component type or circuit block. This makes assembly slower, less organized, and more error-prone.

The repository’s [perfboard DIY layout](Images/Digital/Perfboard_DIYLayout.png) is the layout I designed and used for the first working prototype. It is functional, but it is not presented as the most compact or optimized arrangement. Builders may reproduce it or develop their own layout.

Any custom perfboard layout must also fit within the available enclosure space and leave adequate room for the off-board wiring and bottom plate.

[DIY Layout Creator](https://diy-fever.com/software/diylc/) is recommended for planning a custom perfboard, stripboard, or point-to-point layout before assembly. Regardless of which layout is used, compare every connection against the [complete schematic](Images/Digital/Altium_Schematic.png). A layout drawing is a construction aid; the schematic remains the authoritative electrical reference.

### Component Inspection

When the PCB or perfboard and components are available:

* Inspect the board for obvious defects or damaged pads.
* Verify component values and quantities against the BOM.
* Check transistor and diode pinouts rather than assuming that physically similar parts share the same orientation.
* Confirm potentiometer shafts, switch threads, jack dimensions, and other enclosure-critical measurements.

## 3. Print and Verify the Enclosure Parts

The enclosure design, print settings, tolerances, component fit, and appearance were physically validated using a Bambu H2S. The related files are available in [`Design/3D_Printing`](Design/3D_Printing/).

This step can be completed while waiting for PCB manufacturing and delivery. Printing early also leaves time to identify printer-specific tolerance or fit problems before the electronics are ready for final installation.

### STL and 3MF Files

* **STL files** contain printable geometry that can be imported into most slicers. They do not preserve filament assignments, object placement, or slicer settings.
* **3MF files** contain prepared Bambu Studio projects with object arrangement, filament assignments, and the tested slicer configuration. They are the recommended starting point for a compatible Bambu printer.

> [!CAUTION]
> The provided files and settings do not guarantee identical results on every printer. Dimensional accuracy, tolerances, surface finish, and label clarity can vary with the printer, filament, build plate, calibration, environment, and slicer version.
>
> Parts that differ from those listed in the BOM may not fit the provided enclosure. Printed pieces may require adjustment or reprinting, and the labels may not be equally clear on every setup.

### Multi-Color Printing

The validated design uses white filament for most of the enclosure and black filament for the front-face inlays. A single black inlay layer remained clearly visible against the white enclosure, allowing the inlays to remain shallow and reducing filament changes and purge waste.

The print files work best when the accent color is significantly darker than the primary enclosure color. A single light or translucent layer surrounded by dark material may have poor opacity and appear gray or muted. To use a light accent over a dark enclosure, increase the inlay depth so it spans additional layers.

Multi-color printing is optional. Alternatives include:

* Using raised or recessed single-color labels
* Manually changing filament
* Painting or filling the label geometry after printing
* Printing separate label inserts
* Omitting the cosmetic accents

| Sliced enclosure | Sliced underside |
| --- | --- |
| Sliced enclosure | Sliced underside |

### Manual STL Preparation

When preparing the STL assembly manually:

1. Import the assembly containing the enclosure, inlays, and bottom plate.
2. Use **Lay on Face** to place the enclosure on its top surface so the inlays contact the build plate.
3. Split the assembly into separate objects.
4. Move the bottom plate beside the enclosure and place its flat outer face on the build plate.
5. Assign the correct filament to every object.
6. Configure the accent color to print before the primary color on every layer containing inlays.
7. Preview the generated supports and confirm that they reach the component-mounting holes in the enclosure walls.
8. Confirm that supports are also generated beneath the screw inserts near the back corners, between the potentiometer mounting locations and the bottom-plate attachment locations.

For the validated black-and-white print, filament 1 was assigned as the black accent and filament 2 as the white primary enclosure color.

### Recommended Starting Settings

These settings produced the best results during development and should be treated as starting points rather than universal requirements. Most are modest adjustments intended to improve surface appearance, label clarity, dimensional consistency, and structural integrity rather than radically change the default print profile.

| Setting | Validated value |
| --- | --- |
| Initial-layer line width | 0.42 mm |
| Seam position | Back |
| Elephant-foot compensation | 0.08 mm |
| Wall loops | 4 |
| Bottom shell layers | 4 |
| Internal solid infill pattern | Monotonic line |
| Sparse infill density | 25% |
| Sparse infill pattern | Cubic |
| Initial-layer speed | 25 mm/s |
| Support | Enabled |
| Support type | Normal (auto) |

Object-specific settings:

* For the enclosure and bottom plate, enable **Only one wall on first layer** and use **Monotonic Line** as the bottom-surface pattern.
* For the inlaid arrows and border, use **Concentric** as the bottom-surface pattern and set the seam position to **Aligned**.
* For the `9` object, set the seam position to **Aligned**.

Seam placement is especially important around the bottom plate’s locating pegs and the corresponding enclosure slots:

* Place each peg seam toward the center of the bottom plate.
* Keep interfering seams out of the corresponding enclosure slots.
* Optionally align the enclosure’s outer seam with the bottom plate’s outer seam.

### Knob and LED-Holder Printing

The knob and LED-holder settings are less critical than the enclosure settings. Place the flat top of each part against the build plate; this orientation allowed the validated parts to print without supports.

Dimensional accuracy and component tolerance are more important for these parts, so small slicer-setting changes may be necessary. Variations in LEDs, potentiometer shafts, filament behavior, and printer calibration may require minor dimensional adjustments to the models before the holder and knobs fit correctly.

### Fit Check Before Electronics Assembly

After all enclosure parts finish printing, complete a dry fit before installing the electronics:

* Confirm that the bottom plate seats without bowing.
* Check every locating peg and slot for seam-related interference.
* Test mounting the potentiometers, switches, jacks, power connector, footswitch, and LED holder in their openings.
* Confirm adequate clearance for nuts, washers, solder lugs, wiring, and tools.
* Verify label and graphic clarity before continuing with a long assembly.

<table>
  <thead>
    <tr>
      <th>Printed enclosure face</th>
      <th>Printed enclosure interior</th>
    </tr>
  </thead>
  <tbody>
    <tr>
      <td align="center">
        Top view of the empty printed enclosure
      </td>
      <td align="center">
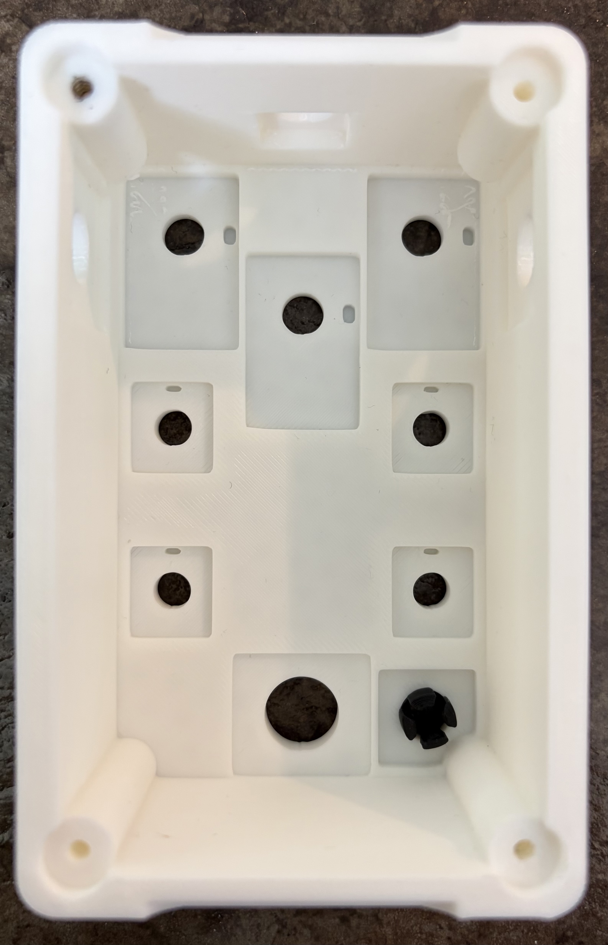
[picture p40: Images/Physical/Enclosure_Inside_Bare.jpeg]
Interior of the empty printed enclosure
        
      </td>
    </tr>
  </tbody>
</table>

Light sanding or printer-specific tolerance adjustment may be required. Avoid forcing parts into openings because this can crack the enclosure or damage component threads.

## 4. Assemble the Circuit Board

Whether using the manufactured PCB or perfboard, match every connection and component value to the BOM and [complete schematic](Images/Digital/Altium_Schematic.png). Verify diode polarity, electrolytic-capacitor polarity, transistor pinouts, and integrated-circuit orientation before soldering.

### Sockets and Board Components

If sockets will be used, install them before the surrounding components. Socket pins cannot be bent outward like ordinary component leads, so they are more difficult to hold in place while soldering. The 8-pin IC socket is recommended because it simplifies op-amp installation and replacement.

Individual machine-pin sockets are optional. Because single sockets can be difficult to align and solder, they are best reserved for components likely to be swapped during experimentation or repair.

After any sockets are installed, populate the board from the lowest-profile components to the tallest. For the provided PCB:

1. Insert each component from the labeled top face.
2. Slightly bend its leads outward on the bottom face to hold it in place.
3. Solder the connection from the bottom.
4. Trim the excess lead length after the joint is complete.

All components and off-board wire leads should enter from the top face of the provided PCB. Avoid excessive heat or repeated rework that could damage pads, and inspect the solder side for bridges, incomplete joints, or loose lead fragments.

For a perfboard build, follow the selected layout carefully and verify each new connection against the schematic. Check continuity frequently rather than waiting until every point-to-point connection is complete.

### Prepare the Off-Board Wiring

Solder wires to the potentiometers, SPDT switches, jacks, DC connector, LED, and true-bypass assembly before soldering the free wire ends to the circuit board. This provides better access to the component lugs and makes the final enclosure installation easier.

Wires up to approximately **4–5 inches** were sufficient for the validated build. Excessively long wires make the enclosure harder to organize and can increase unwanted signal coupling, while very short wires create mechanical stress and make assembly difficult. Each lead should comfortably reach from its circuit-board connection to the mounted component with some assembly clearance.

Different wire colors are not required, but they are strongly recommended for distinguishing power, ground, input, output, control, and switching connections.

Before wiring an SPDT switch, inspect its enclosure orientation, anti-rotation hardware, and intended behavior. Use a multimeter in continuity mode to identify which terminals connect in each switch position, then relate those positions to the PCB labels or perfboard connections and the enclosure markings.

3PDT wiring may vary depending on the bypass-switch hardware purchased. If a breakout board is included, review its intended wiring and compare it with the 808 EQ+ schematic and selected PCB or perfboard layout before soldering any wires. Both circuit-board layouts provide the connections needed for a compatible 3PDT true-bypass arrangement, including the effect input and output, audio jacks, ground, and LED-control connections.

On the manufactured PCB, the pad labeled `9V` provides the filtered and reverse-polarity-protected 9 V output. This pad can be connected through a current-limiting resistor (CLR) to power the effect-status LED.

## 5. Test the Circuit Board Outside the Enclosure

Testing the completed PCB or perfboard assembly before enclosure installation separates electrical faults from mechanical problems.

Assembled PCB with the off-board controls connected

*Assembled PCB and off-board controls prepared for bench testing; follow the schematic for wiring.*

### Power-Off Checks

Before applying power:

* Check for an unintended short between the 9 V and ground rails.
* Inspect the power-input polarity and 1N4007 orientation.
* Recheck polarized components and the orientations of the op-amp and BJTs.
* Verify continuity through important ground and power connections.

### Initial Powered Checks

If available, use a current-limited bench supply for the first startup. Otherwise, use a regulated 9 V center-negative pedal supply.

* Confirm that the protected supply rail is present after the reverse-polarity diode.
* Confirm that the 4V5 reference is approximately half of the protected supply rail.
* Check for unexpected heating, excessive current draw, smoke, or odor, and disconnect power immediately if any appears.
* Remember that the rails labeled `9V` and `4V5` are nominal; diode drop and supply tolerance cause the measured values to differ.

### Functional Checks

Test the circuit board with the prepared jack, control, and switch connections before mounting it permanently. Verify:

* True-bypass signal flow, effect engagement, and LED indication
* Continuous audio-signal flow through the active circuit
* Drive, Tone, and Level operation
* Bass and Treb Pass Through behavior
* Symmetric silicon, asymmetric silicon, and LED clipping
* Reasonable output level and noise

Begin with the connected amplifier or audio interface at a conservative volume. Do not connect valuable equipment until the supply polarity and DC operating points have been verified.

A steady background noise does not necessarily indicate a circuit fault. Some 9 V pedal supplies are noticeably noisier than others, and any unfiltered supply noise can be amplified by the circuit and become much more obvious while the effect is active. If the pedal otherwise operates correctly, compare it with a known low-noise isolated pedalboard supply or another regulated supply before troubleshooting the audio circuit itself. Persistent noise with multiple known-good supplies should still be investigated.

## 6. Install the Off-Board Components

The off-board components should already be wired and connected to the circuit board before this step. Carefully guide each component and its wiring into the enclosure without twisting the wires or placing excessive stress on solder joints.

The recommended installation order is:

1. Potentiometers
2. DC power jack
3. Input and output audio jacks
4. SPDT switches
5. LED holder and LED
6. True-bypass footswitch

The SPDT switches and some potentiometers have small anti-rotation tabs protruding from their mounting faces. The enclosure includes corresponding holes that accept these tabs and establish the correct component orientation. Confirm that each tab is seated before tightening the mounting hardware.

During installation:

* Route signal wires away from the power-input and LED wiring where practical.
* Prevent exposed lugs or solder joints from touching one another or the circuit board.
* Avoid using the wires or solder joints as mechanical strain relief.
* Tighten the mounting hardware enough to prevent movement without crushing or deforming the printed enclosure.
* Confirm that the controls and switches match the enclosure labels and expected operating directions.

After installation, re-test bypass operation, effect engagement, LED indication, and all controls before positioning the circuit board for final closure.

## 7. Complete the Final Assembly

The enclosure intentionally does not include a dedicated circuit-board mounting structure. In the validated PCB build, the compact internal layout, connected wiring, and bottom plate constrain the board and keep it mostly stationary. Perfboard builders must verify that their selected board dimensions and layout are similarly contained without contacting other hardware.

Carefully arrange the circuit board and wiring before closing the enclosure. Excessive force can crack, scratch, or deform the printed enclosure, damage solder joints, or place unnecessary stress on the mounted components.

Before installing the bottom plate:

* Confirm that the circuit board cannot contact exposed conductive hardware or be crushed by the bottom plate.
* Arrange the wiring so it does not place excessive force on circuit-board pads or component lugs.
* Route wires away from the input and output jack contacts. Inserting a 1/4-inch plug could catch, displace, or damage wires positioned in front of these contacts.
* Check that no wire will be pinched between the enclosure and bottom plate.
* Confirm that all external hardware is secure without being overtightened against the printed plastic.

If the bottom plate does not seat properly, do not force it into position or tighten the screws in an attempt to pull it closed. Check for interfering wires, components, locating pegs, print seams, or dimensional inaccuracies. Slight adjustments to the print settings or model dimensions may be necessary for a particular printer.

Install the printed knobs onto the potentiometer shafts during final assembly. Turn each potentiometer fully counterclockwise, align the knob indicator with the minimum position shown on the enclosure, and carefully press the knob into place. If a knob is slightly too tight or loose, pliers or another suitable hand tool can be used cautiously to close or widen the gap in the split potentiometer shaft. Make only very small adjustments because excessive force can permanently deform or break the shaft. If the fit remains incorrect, adjust the knob’s printed dimensions rather than forcing it onto the potentiometer.

Close the enclosure only after the fully wired pedal has passed another powered functional test.

## 8. Perform Final Validation

At this point, the pedal is likely ready to go. Connect your guitar and amplifier, power it up, and enjoy the result of all your hard work. As you explore the controls, pay attention to the following areas in case any final adjustments are needed:

* Bypass signal continuity
* Effect engagement and LED indication
* Drive, Tone, and Level ranges
* Bass Cut and Bass Pass Through settings
* Treb Cut and Treb Pass Through settings
* Symmetric silicon clipping
* Asymmetric silicon clipping
* Symmetric LED clipping
* Switching interaction across every control combination
* Output level, noise, and unwanted oscillation
* Jack, switch, knob, and footswitch clearance
* Bottom-plate fit and mechanical stability
* Practical operation with your guitar and amplifier

Some variation in noise, frequency response, distortion, and output level is expected because of component tolerances, the power supply, guitar, pickups, cables, amplifier, and playing dynamics. These differences are part of what makes each setup—and each completed pedal—a little unique.

For control-layout diagrams, complete mode descriptions, additional power information, and visual operating guidance, see the [808 EQ+ User Manual](808_EQ-Plus_User_Manual.pdf).

### Recommended Starting Points

The following settings are starting points, not rules. Control positions may need to be adjusted for your guitar, pickups, amplifier, and preferred playing volume.

#### 1. Dynamic and Responsive

My personal favorite setting is to engage both Bass Pass Through and Treb Pass Through, then select **Open** for the LED clipping configuration. Start with Drive and Tone around `1:30` and Level near its minimum.

From there, adjust Drive until the distortion becomes most noticeable when you really dig into the strings. Adjust Level until the pedal is near unity gain, meaning the amplifier sounds approximately as loud with the effect engaged as it does in bypass.

This setting responds well to picking dynamics. Softer playing can remain relatively clean and open, while stronger, more energetic playing introduces additional grit and character.

#### 2. Traditional TS808-Style Boost

For a more traditional Tube Screamer application, disable Bass Pass Through and Treb Pass Through, then select **Tight** and **Sym** for symmetric silicon clipping. This returns the pedal to its familiar TS808-style voicing and clipping behavior.

Start with Drive around **9 o’clock**, Tone around **11–12 o’clock**, and Level above unity gain. This approach is commonly used to push an amplifier that is already beginning to distort. It tightens the low end, adds a touch of Tube Screamer soft clipping, and drives the amplifier input harder for additional grit and sustain.

#### 3. Explore the Extremes

Do not be afraid to test the outer limits of the controls. Engage Treb Pass Through and turn Tone all the way up, or enable only Bass Pass Through and crank the Drive control. Compare every clipping configuration, combine the switches in unexpected ways, and listen to how the pedal responds to different pickup selections and playing styles.

The best setting is the one that inspires you to keep playing, so experiment freely and find the sounds that speak to you.

## Troubleshooting Guidelines

| Symptom | Initial checks |
| --- | --- |
| No power or LED | Supply polarity and voltage, DC-jack wiring, D1 orientation, LED polarity, current-limiting resistor, and 3PDT wiring |
| Bypass works but effect does not | 3PDT effect connections, circuit-board input/output wiring, op-amp orientation, 9 V rail, 4V5 bias, and signal continuity |
| No bypass signal | Input/output jack wiring, 3PDT breakout orientation, ground connection, and cable condition |
| Weak or distorted output in every mode | Incorrect component value, transistor pinout, diode orientation, bias voltage, solder bridge, or poor joint |
| Excessive hum or noise | Ground continuity, power-supply quality, wire routing, floating inputs, jack grounds, and nearby interference |
| A switch setting does not work | SPDT orientation, wiring continuity, selected capacitor or diode network, and switch-lug soldering |
| Loud switching pop | Floating capacitor charge, missing ground reference, true-bypass wiring, or output pull-down connection |
| Enclosure will not close | Component depth, wire routing, circuit-board position, locating-peg seams, bottom-plate alignment, and substituted hardware dimensions |
| Labels are unclear | Build-plate surface, first-layer calibration, filament contrast, inlay depth, filament order, and initial-layer speed |

For circuit-specific troubleshooting, use the stage diagrams and explanations in the [Technical Documentation](TECHNICAL_DOCUMENTATION.md#circuit-design). Make one change at a time and re-test after each correction.

---

Return to the [main project README](README.md).

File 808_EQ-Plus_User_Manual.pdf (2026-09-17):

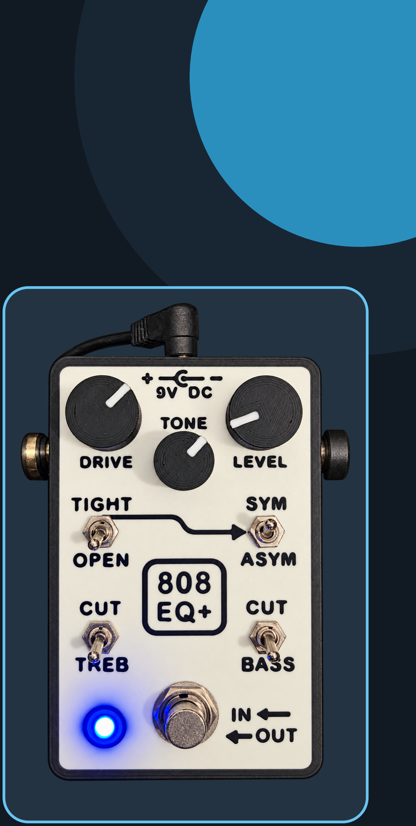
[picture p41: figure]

808
EQ+

EXPANDED TS808-STYLE OVERDRIVE

# USER MANUAL

A beginner-friendly guide to connections, controls, sound modes, and everyday operation.

9 V DC CENTER-NEGATIVE | TRUE BYPASS

808 EQ+ | GET PLAYING

01

# Quick Start

Connect the pedal safely, choose a familiar starting sound, and begin at a controlled volume.

1

Turn the volume down

Lower the amplifier or interface input before making connections.

2

Connect your guitar

Use the right-side IN jack when the pedal is viewed from

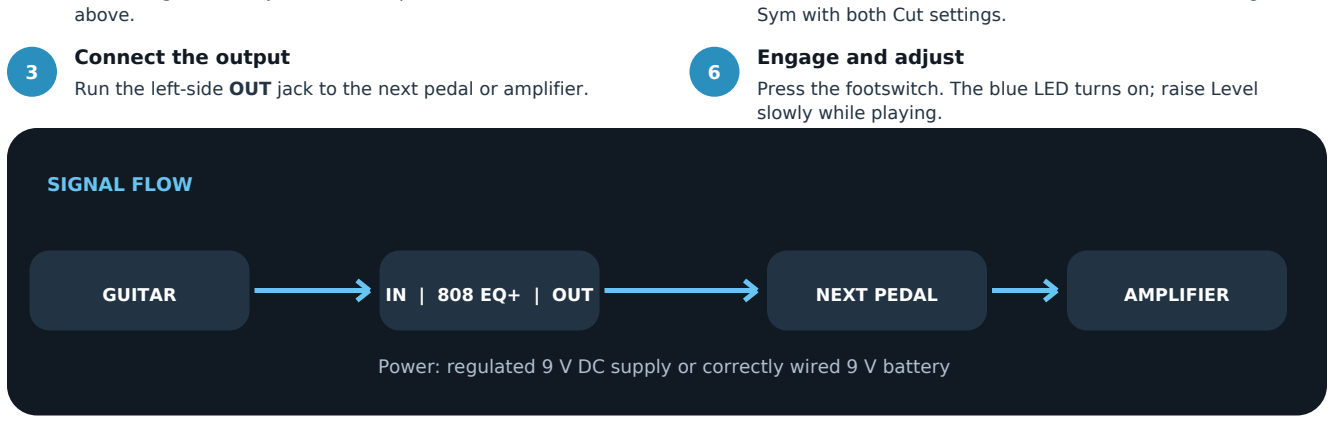
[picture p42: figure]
above.; Connect the output; Sym with both Cut settings.; Engage and adjust; slowly while playing.; SIGNAL FLOW

Run the left-side OUT jack to the next pedal or amplifier.

4

Connect power

Use regulated 9 V DC, center-negative power or a correctly wired 9 V battery adapter.

5

Choose a starting point

Set Drive and Tone near noon, Level low, and select Tight +

Press the footswitch. The blue LED turns on; raise Level

GUITAR | IN | 808 EQ+ | OUT | NEXT PEDAL | AMPLIFIER

Power: regulated 9 V DC supply or correctly wired 9 V battery

POWER CHECK

Use a regulated 9 V DC, center-negative supply, or a 9 V battery connected through a center-negative 2.1 mm plug. Verify the connector polarity before use. The circuit remains powered while bypassed, so disconnect an external battery when you are finished. Do not apply more than 9 V.

Your first useful check

With the effect engaged, move Level until the amplifier is about as loud as it is when the pedal is off -meaning the effect and LED are deactivated. This matching point is called unity gain. From there, Drive, Tone, and switch changes are easier to compare because a volume difference is not dominating what you hear.

START GENTLY
Every knob and switch can affect output volume, and some configurations vary noticeably. Open mode is especially loud. Listen closely and adjust Level as needed whenever you change settings.
808 EQ+ / USER MANUAL | 02

808 EQ+ | CONTROL LAYOUT

02

# Pedal at a Glance

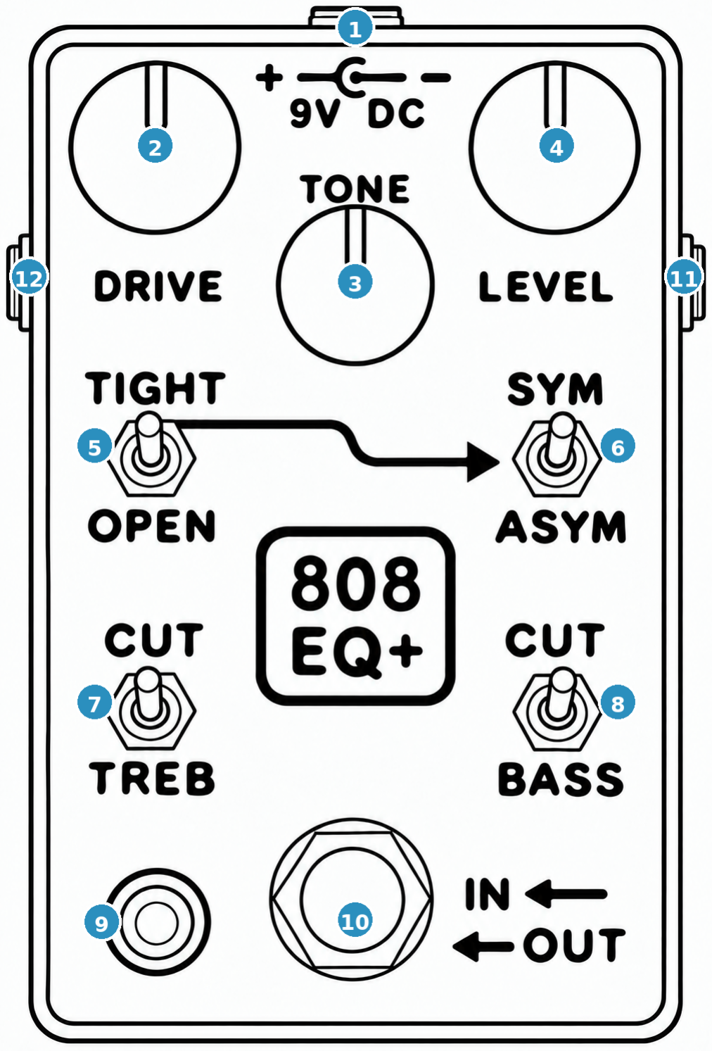
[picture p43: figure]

1

### 9 V DC

Regulated center-negative power

2

Drive

Overdrive intensity

3

Tone

Dark to bright

4

Level

Final output volume

5

Tight / Open

Compressed or dynamic clipping

6

Sym / Asym

Tight-mode clipping texture

7

Cut / Treb

Traditional or extended clarity

8

Cut / Bass

Traditional or extended fullness

9

Status LED

On while effect is active

10

Footswitch

Effect / true bypass

11

Input

Right-side 1/4-inch jack

12

Output

Left-side 1/4-inch jack

Arrow reminder: Sym/Asym only changes the sound when Tight is selected. In Open mode, that switch is ignored.

808 EQ+ | BEGINNER GUIDE

03

# Controls in Plain Language

Start with what each control feels like under your fingers; the circuit details can wait.

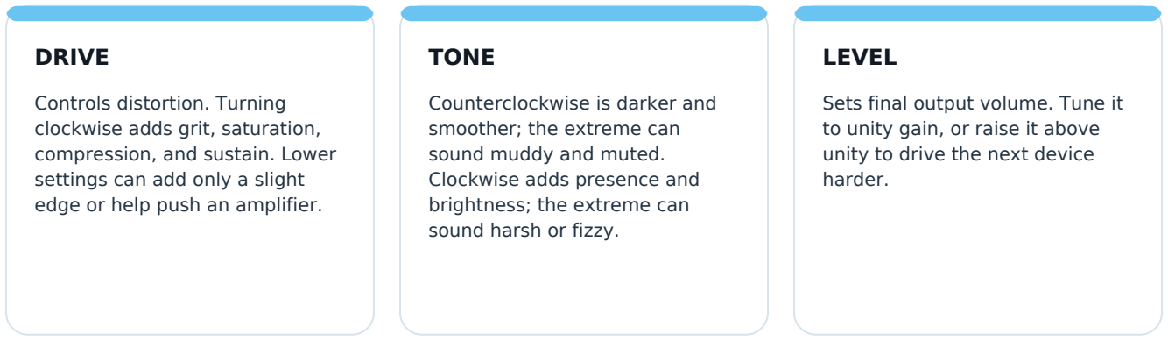
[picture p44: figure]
DRIVE; Controls distortion. Turning clockwise adds grit, saturation, compression, and sustain. Lower settings can add only a slight edge or help push an amplifier.; TONE; Counterclockwise is darker and smoother; the extreme can sound muddy and muted. Clockwise adds presence and brightness; the extreme can sound harsh or fizzy.; LEVEL; Sets final output volume. Tune it to unity gain, or raise it above unity to drive the next device harder.

# 2 clipping switches, 2 EQ switches

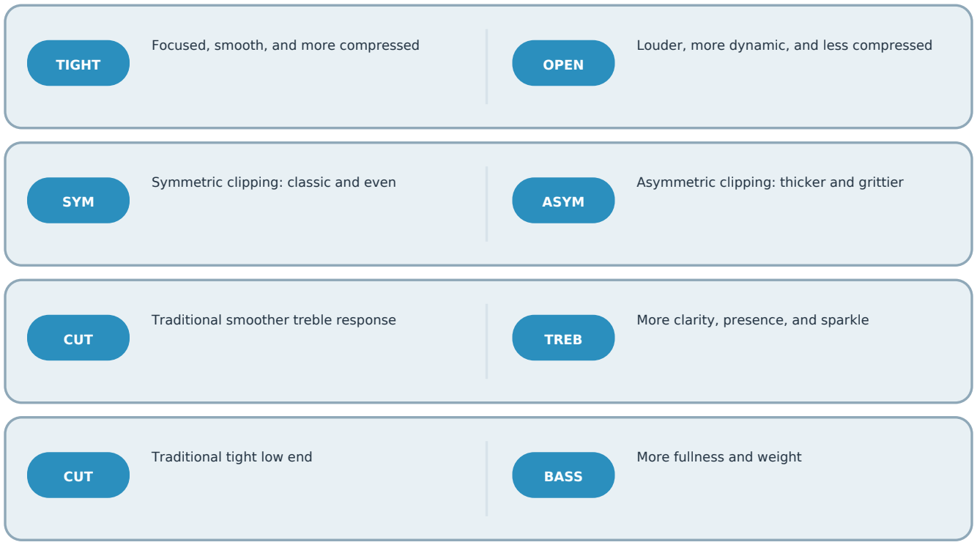
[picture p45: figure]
TIGHT; Focused, smooth, and more compressed; OPEN; SYM; Symmetric clipping: classic and even; ASYM; Asymmetric clipping: thicker and grittier; CUT; Traditional smoother treble response; TREB; More clarity, presence, and sparkle; Traditional tight low end; BASS; More fullness and weight

Louder, more dynamic, and less compressed

Easy classic reset: flip all four switches upward. This selects Tight + Sym with both EQ switches at Cut, returning the pedal to a classic Tube Screamer 808 circuit configuration.

808 EQ+ | SOUND GUIDE

04

# Sound Modes at a Glance

Think of the switches as three layers: clipping feel, clipping texture, and frequency range.

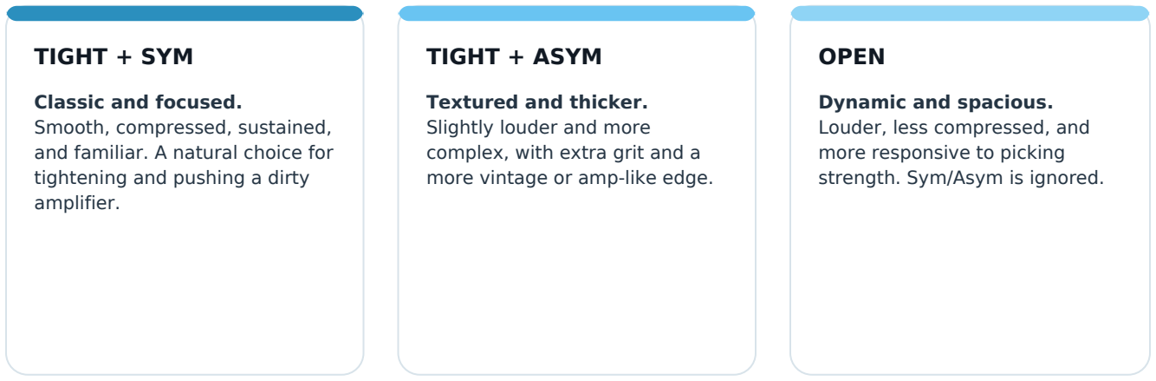
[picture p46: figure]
TIGHT + SYM; Classic and focused. Smooth, compressed, sustained, and familiar. A natural choice for tightening and pushing a dirty amplifier.; TIGHT + ASYM; Textured and thicker. Slightly louder and more complex, with extra grit and a more vintage or amp-like edge.; OPEN; Dynamic and spacious. Louder, less compressed, and more responsive to picking strength. Sym/Asym is ignored.

# Shape the range

TREB CUT

Smoother and more focused; closer to the traditional Tube Screamer upper-frequency response.

TREB

Clearer, brighter, more present, and more open. Lower Tone if the result becomes sharp.

BASS CUT

Tighter and leaner. Helpful with high Drive, bass-heavy amplifiers, or dense mixes.

BASS

Fuller and thicker, adding weight beneath the distorted sound.

Combine freely. Bass and Treb operate independently. Use either extension alone, both together, or neither. The best combination depends on the guitar, amplifier, speaker, and how hard you are driving the pedal.

808 EQ+ | STARTING SOUNDS

05

# Three Places to Begin

Approximate clock positions are only starting points. Match Level to your rig before judging the tone.

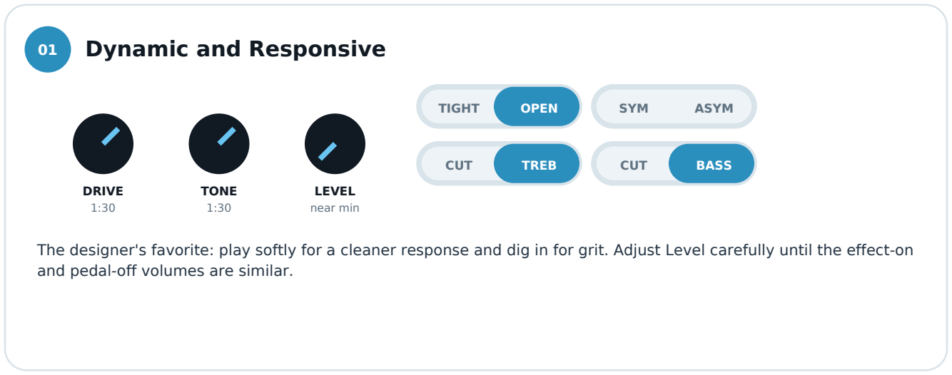
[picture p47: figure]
01 Dynamic and Responsive; DRIVE; TONE; LEVEL; near min; TIGHT; OPEN; SYM; ASYM; CUT; TREB; BASS; and pedal-off volumes are similar.

The designer's favorite: play softly for a cleaner response and dig in for grit. Adjust Level carefully until the effect-on

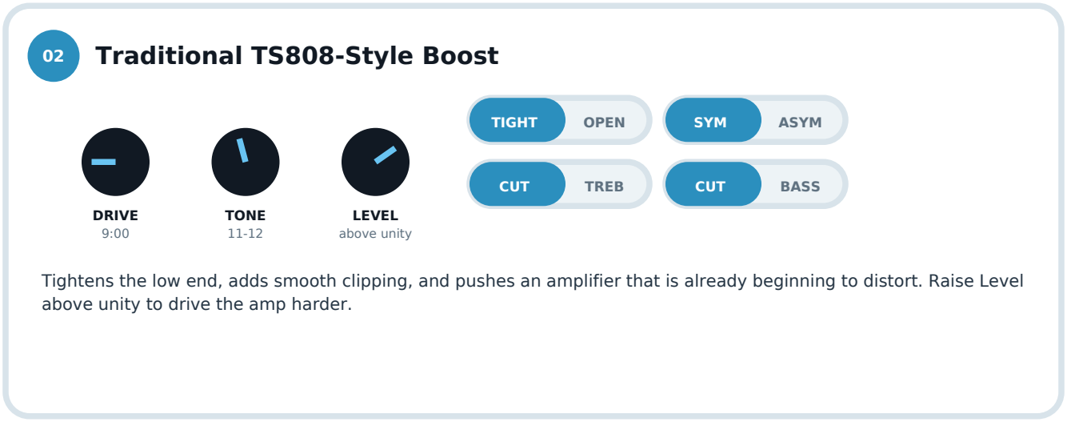
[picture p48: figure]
02 Traditional TS808-Style Boost; DRIVE; TONE; LEVEL; above unity; TIGHT; OPEN; SYM; ASYM; CUT; TREB; BASS; above unity to drive the amp harder.

Tightens the low end, adds smooth clipping, and pushes an amplifier that is already beginning to distort. Raise Level

### 03 EXPLORE THE EXTREMES

Try Treb with Tone fully clockwise for a sharp, immediate sound, or select Bass and turn Drive high for a larger, heavier character. Compare pickup selections and change how hard you play. The setting that makes you keep playing is the right one.

808 EQ+ | DEEPER DETAIL

06

# Why the Controls Change the Sound

The circuit is complex, but its musical behavior can be understood without equations.

DRIVE | HOW HARD IT IS PUSHED

Drive enlarges the signal entering the clipping section. As the signal grows, its peaks are rounded and limited more strongly, creating overdrive, compression, and sustain.

TONE | UPPER-MID AND TREBLE SHAPE

The Tone knob primarily controls upper-mid and high frequencies while leaving low and lower-mid content largely unchanged. The Treb switch sets the available high-frequency range before the signal reaches the Tone shaping portion of the circuit.

BASS | WEIGHT INTO THE OVERDRIVE

Bass allows more low-frequency content to receive distortion gain. The result is fuller and larger. Bass Cut keeps low frequencies tighter and can preserve definition with high Drive or a bass-heavy rig.

TREB | DETAIL BEFORE TONE CONTROL

The Treble switch acts on the effected signal before the Tone control. Activating Treb allows substantially more upper-frequency detail into that stage, increasing overall clarity and openness; Cut restores the traditional smoother response of a TS808.

The controls interact

A bright guitar through a bright amplifier may need less Tone or Treb, while high Drive can make extra bass feel looser. Different knob and switch combinations can also change output volume noticeably. Treat the controls as a system.

808 EQ+ | DEEPER DETAIL

07

# Clipping Feel and Texture

Clipping changes more than the amount of distortion: it also changes compression, output, and touch response.

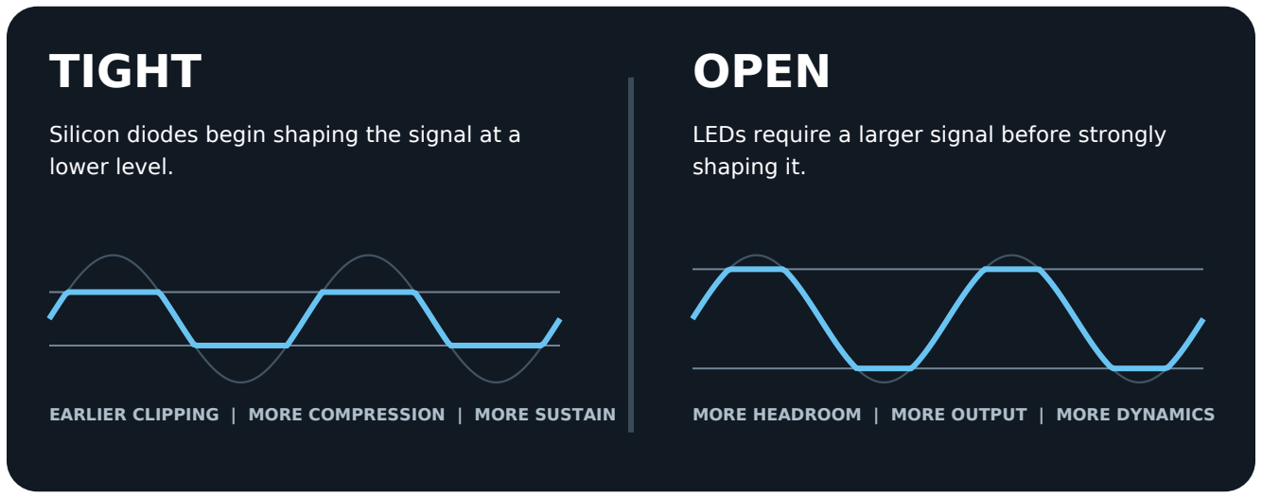
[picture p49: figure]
TIGHT; lower level.; OPEN; shaping it.

Silicon diodes begin shaping the signal at a

EARLIER CLIPPING | MORE COMPRESSION | MORE SUSTAIN

LEDs require a larger signal before strongly

MORE HEADROOM | MORE OUTPUT | MORE DYNAMICS
SYM | SYMMETRIC CLIPPING

In Tight mode, symmetric clipping shapes the positive and negative halves similarly. This creates the traditional smooth, balanced TS808-style character and tends to emphasize odd-order harmonics.

ASYM | ASYMMETRIC CLIPPING

In Tight mode, asymmetric clipping treats the two halves differently. It adds a little output and a thicker texture, with a combination of odd- and even-order harmonics.

Why the arrow is printed on the pedal: the Sym/Asym switch belongs to Tight mode. Open selects its own LED clipping arrangement, so moving Sym/Asym while Open is selected produces no change.

808 EQ+ | CONNECTIONS AND SPECIFICATIONS

08

# Power, Bypass, and Physical Details

The essentials for reliable everyday use and pedalboard integration.

POWER

### 9 V DC | center-negative | 2.1 mm

Average current draw is approximately 7-10 mA. A verified center-negative 9 V battery also works. The circuit remains powered while bypassed, so disconnect the battery when not in use. Do not use higher voltage.

AUDIO AND BYPASS

Right-side 1/4-inch jack: IN
Left-side 1/4-inch jack: OUT

True bypass completely disconnects the guitar from the effect circuit while off, preserving the guitar's raw tone as much as possible.

# Signal and enclosure

ACTIVE

IN -> input buffer -> drive / clipping

-> tone / level -> output buffer -> OUT

BYPASS

IN -------------------------------------> OUT

LED on = active effect | LED off = true bypass

### 70 mm

110 mm

45 mm body depth

Approximate body size

EFFECT | TS808-style overdrive with expanded EQ and clipping
CONTROLS | Drive, Tone, Level; four two-position toggles
POWER | Regulated 9 V DC center-negative
BATTERY | External 9 V battery supported with verified center-negative 2.1 mm connection
CURRENT | Approximately 7-10 mA average
ENCLOSURE | 3D-printed plastic; approximately 110 x 70 x 45 mm body

808 EQ+ | CARE AND HELP

09

# Troubleshooting and Care

Start with connections, power, and control positions before assuming an internal fault.

NO SOUND

Confirm the guitar is connected to right-side IN, left-side OUT feeds the amplifier, and both cables work.

BYPASS WORKS; EFFECT DOES NOT

Check regulated 9 V center-negative power, confirm Level is not at minimum, and look for the active LED.

TOO LOUD

Lower Level. Different knob and switch settings can change output volume noticeably; Open mode is especially loud. Readjust Level after changing settings.

STEADY NOISE

Try a known low-noise or isolated supply. The active circuit can amplify supply noise along with the guitar signal.

TOO BRIGHT

Lower Tone or select Treb Cut.

TOO MUDDY

Select Bass Cut, reduce Drive, or turn up Tone.

SYM/ASYM HAS NO EFFECT

Select Tight. Sym/Asym is intentionally ignored in Open mode.

BRIEF SWITCH POP

A small pop can occur when a tone-switch capacitor changes. Switch at a sensible listening level.

PRINTED ENCLOSURE CARE

The printed enclosure does not provide the impact resistance, heat resistance, or inherent electromagnetic shielding of a grounded cast-metal enclosure. Avoid excessive heat, impact, crushing force, and unnecessary stress on the controls and connectors.

If a problem persists, disconnect the pedal from valuable equipment before inspecting or modifying it.

808
EQ+

MORE PROJECT INFORMATION

For the build guide, schematic, BOM, PCB and perfboard resources, CAD drawings, print files, and technical documentation, visit the GitHub repository:

github.com/mbovero/

808_EQ-Plus_Guitar_Pedal

USE RESPONSIBLY

This educational, personal-use project is provided without a guarantee of error-free documentation. Build and use it at your own risk, and disconnect power before opening or modifying it. Reports of inconsistencies are appreciated.

808 EQ+ | USER MANUAL

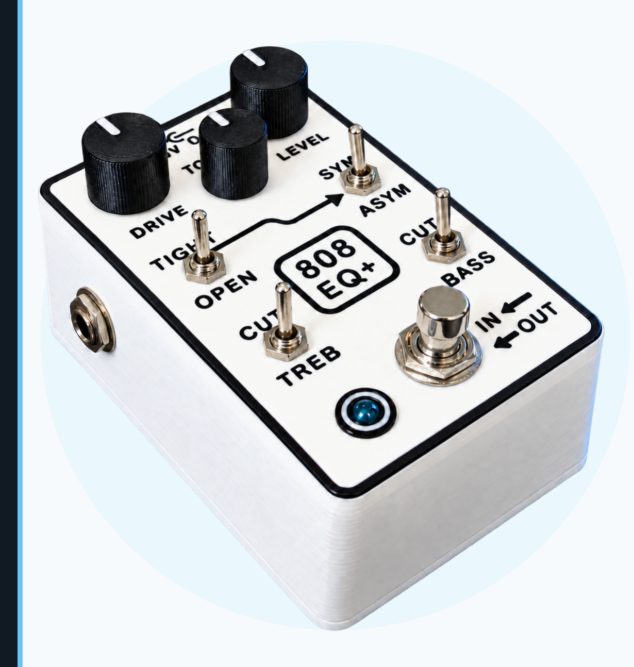
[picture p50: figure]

KEEP PLAYING.
KEEP EXPLORING.

The best setting is the one that responds to your hands, your guitar, and your amplifier. Use the starting points, then make the pedal your own.

This document was generated and revised using ChatGPT.

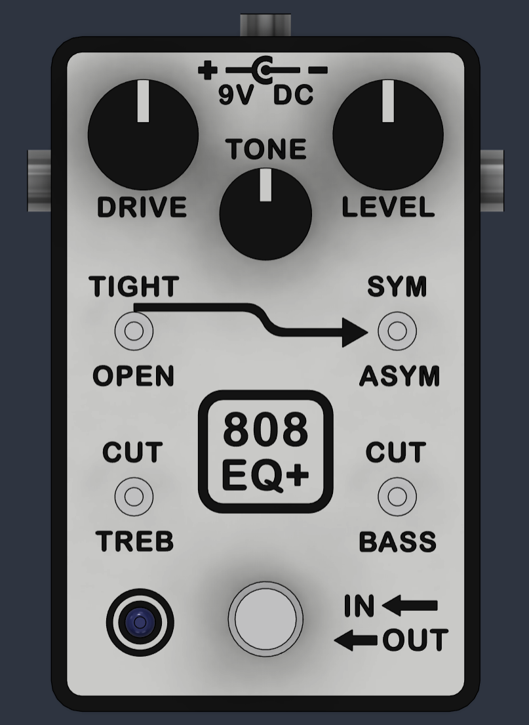
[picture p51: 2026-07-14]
Images/Digital/Fusion_Assembled_Enclosure_Top.png

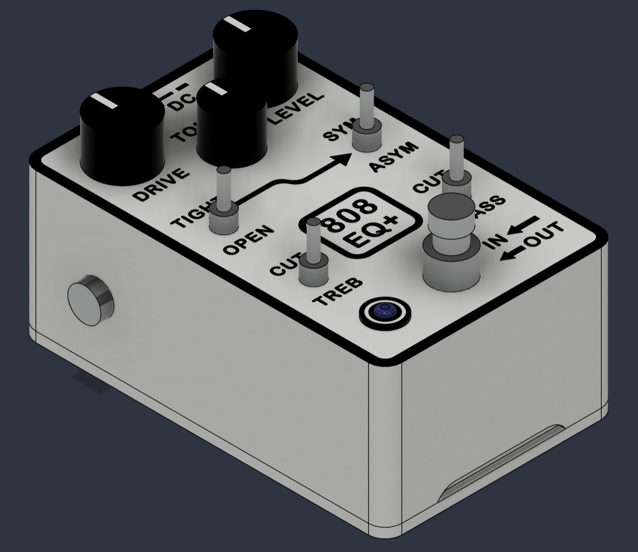
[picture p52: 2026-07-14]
Images/Digital/Fusion_Assembled_Enclosure_Iso.png

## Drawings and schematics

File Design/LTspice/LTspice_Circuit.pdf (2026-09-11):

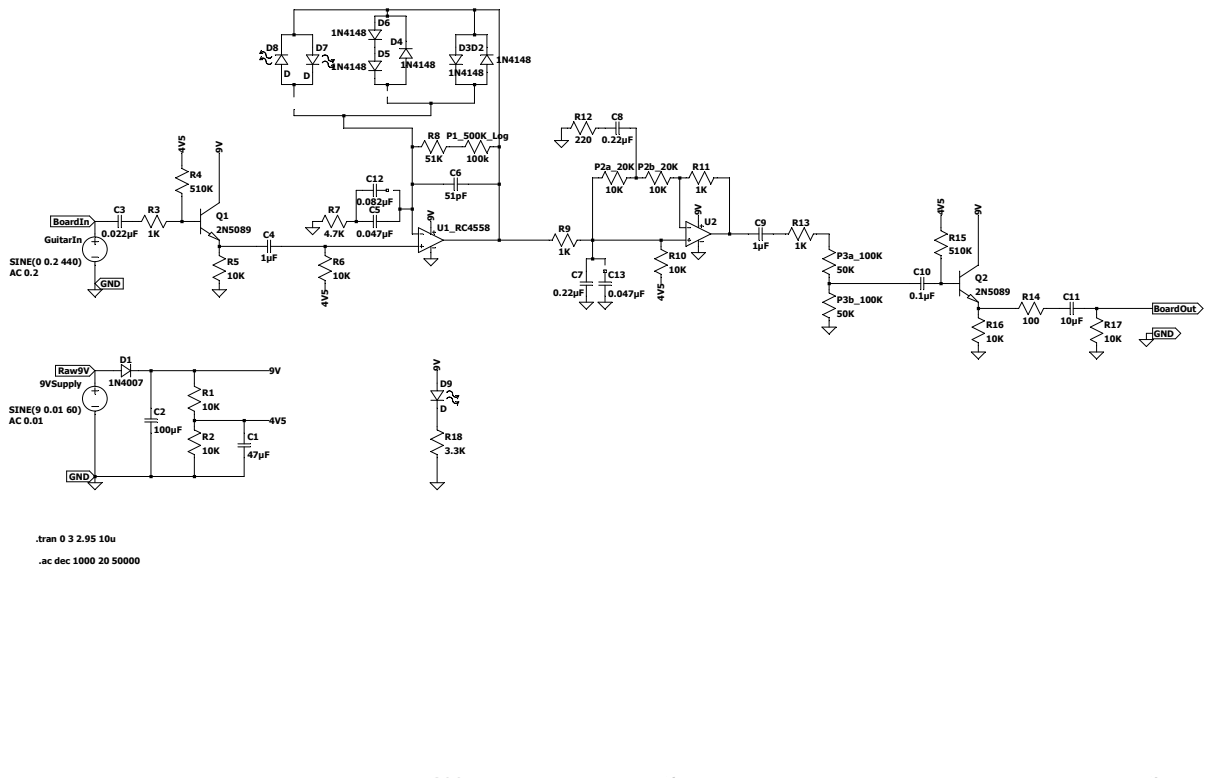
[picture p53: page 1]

--- C:\Users\miles\Downloads\Guitar\Pedals\Modded_TS\808_EQ-Plus_Guitar_Pedal\Design\LTspice\Modded_Tube_Screamer.asc ---

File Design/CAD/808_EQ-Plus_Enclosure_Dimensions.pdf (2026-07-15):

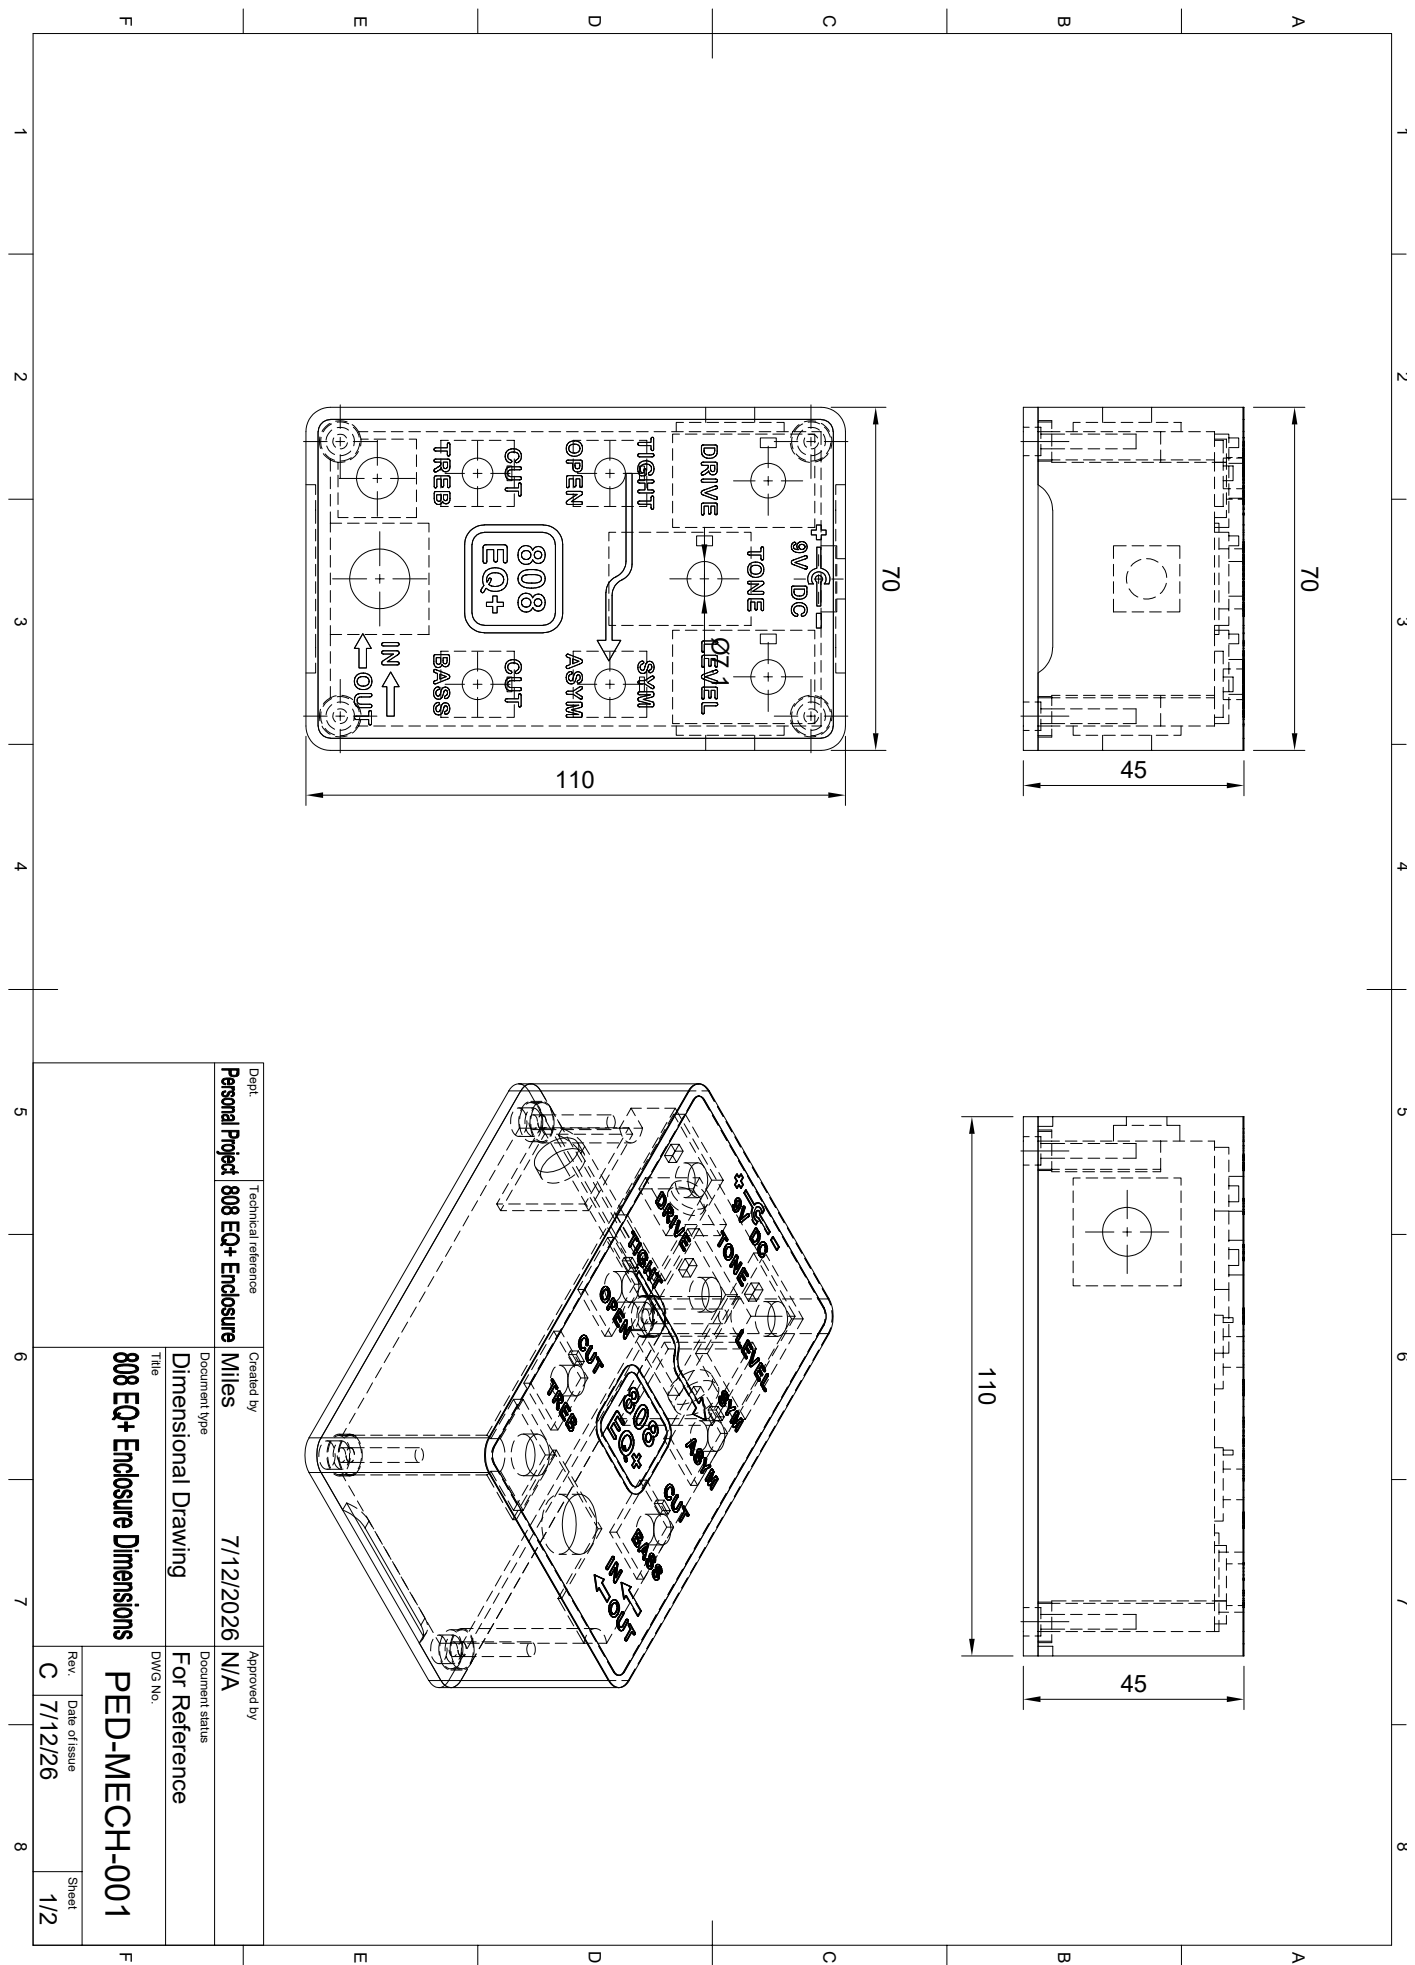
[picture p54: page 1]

Dept. Technical reference Created by Approved by Title DWG No. Document type Document status Rev. Date of issue Sheet 7/12/26 CFor Reference Dimensional Drawing 7/12/2026 1/2 PED-MECH-001 N/A Miles 1 A 2 3 4 5 6 7 8 1 2 3 4 5 6 7 8 FEDCB FEDCBA Ø7.1 70 110

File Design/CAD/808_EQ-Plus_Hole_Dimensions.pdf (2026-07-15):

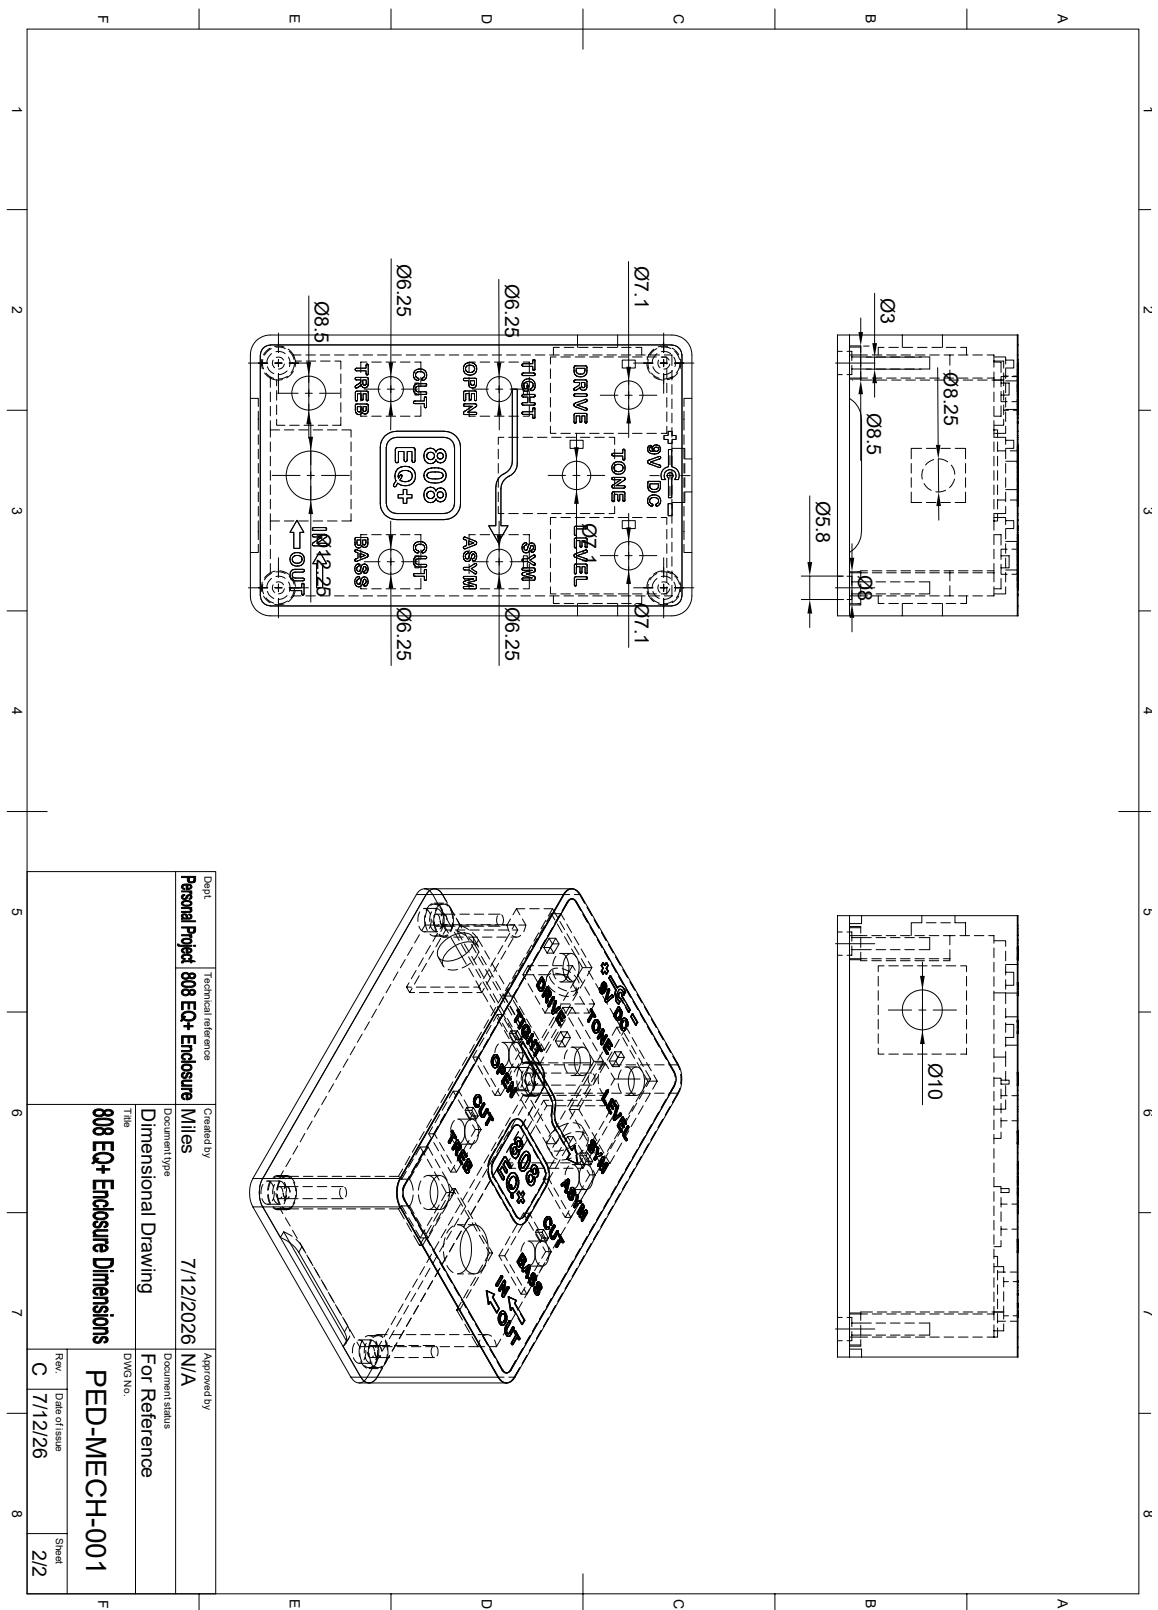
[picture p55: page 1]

Dept. Technical reference Created by Approved by Title DWG No. Document type Document status Rev. Date of issue Sheet 7/12/26 CFor Reference Dimensional Drawing 7/12/2026 2/2 PED-MECH-001 N/A Miles 1 A 2 3 4 5 6 7 8 1 2 3 4 5 6 7 8 FEDCB FEDCBA Ø8.25 Ø10 Ø7.1 Ø7.1 Ø7.1 Ø6.25 Ø6.25 Ø6.25 Ø6.25 Ø8.5 Ø12.25 Ø3 Ø8 Ø8.5 Ø5.8

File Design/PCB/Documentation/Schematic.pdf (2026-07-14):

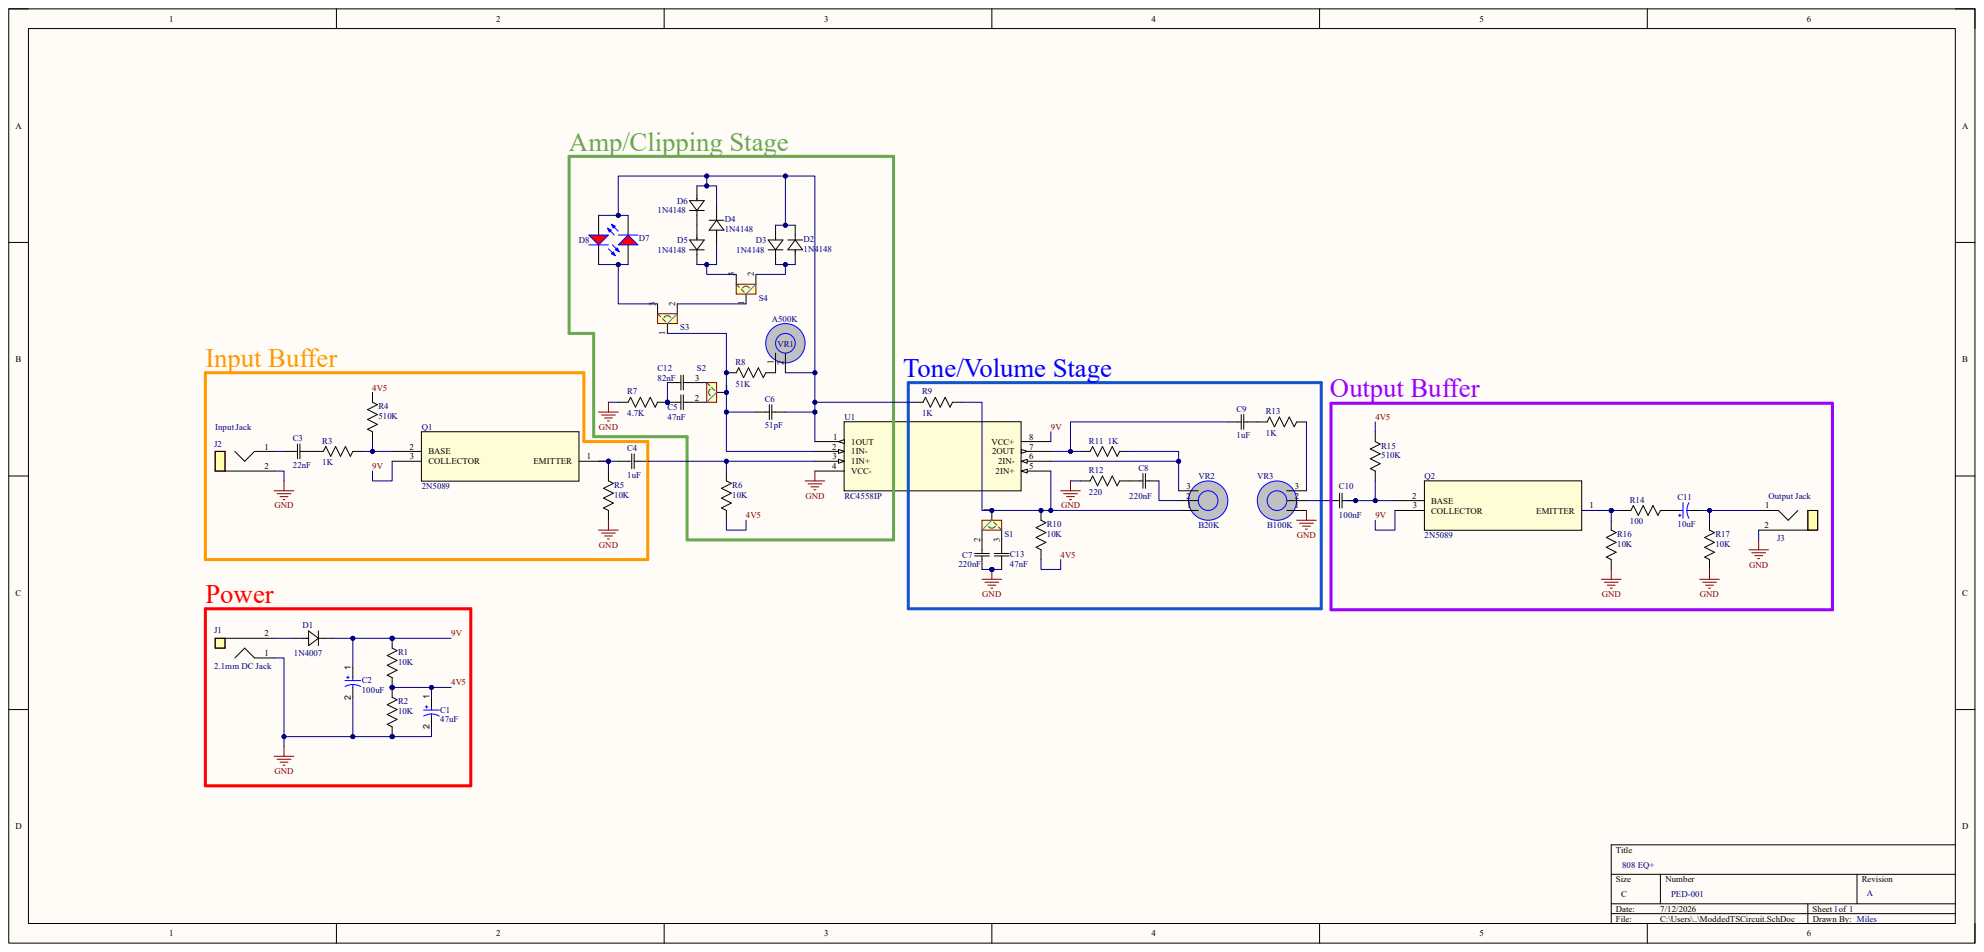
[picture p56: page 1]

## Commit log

2026-07-15 Uploaded latest enclosure CAD and 3D printing files
    [ModdedTSEnclosure_v1.3.3mf, Modded_TS_Enclosure_v1.3.stl]
2026-07-16 Added individual circuit block images
2026-07-16 Added detailed circuit design documentation; cleaned up redundancies
2026-07-16 Uploaded tube screamer output wave form
2026-09-11 Fixed LTspice circuit PDF
2026-09-16 Uploaded images of physical pedal build stages
2026-09-17 Added images of physical pedal and circuits to readmes
2026-09-17 Upload images of the assembled protoype pedal
2026-09-17 Inserted prototype images
2026-09-17 Added note to disconnect battery
